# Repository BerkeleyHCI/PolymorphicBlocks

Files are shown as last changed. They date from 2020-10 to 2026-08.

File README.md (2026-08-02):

# Polymorphic Blocks






_subcircuit generator library based hardware description language for circuit board design_

Polymorphic Blocks is an open-source, Python-based [hardware description language (HDL)](https://en.wikipedia.org/wiki/Hardware_description_language) for schematic-equivalent design of printed circuit boards (PCBs).
Its library of components provide a high-level abstraction for circuit design while subcircuit generators automate the calculation of fine details.
Abstract component interfaces enable these libraries to be general across applications and component vendors.

Generates stable KiCad netlists to be routed in the KiCad PCB Editor.

### Built Boards

Many boards have been built with this system, from a mechanical keyboard macropad, to battery-powered IoT devices, to a USB source-measure unit.
Check out the [examples page](examples.md)!

## Example: from HDL to Keyboard

**Overall flow**: write HDL -> generate netlist -> import into KiCad PCB editor -> place and route (optionally iterating with HDL) -> export BoM and Gerbers -> optionally generate JLC PCBA data

A simplified version of the [getting started tutorial](getting-started.md) is this snippet for a 3x4 mechanical keyboard:

```python
from edg import *

class Keyboard(SimpleBoardTop):
    def contents(self) -> None:
        super().contents()

        self.usb = self.Block(UsbCReceptacle())
        self.reg = self.Block(LinearRegulator(3.3 * Volt(tol=0.05)))
        self.connect(self.usb.gnd, self.reg.gnd)
        self.connect(self.usb.pwr, self.reg.pwr_in)

        with self.implicit_connect(
            ImplicitConnect(self.reg.pwr_out, [Power]),
            ImplicitConnect(self.reg.gnd, [Common]),
        ) as imp:
            self.mcu = imp.Block(IoController())
            self.connect(self.usb.usb, self.mcu.usb.request())

            self.sw = self.Block(SwitchMatrix(ncols=3, nrows=4))
            self.connect(self.sw.cols, self.mcu.gpio.request_vector("sw_col"))
            self.connect(self.sw.rows, self.mcu.gpio.request_vector("sw_row"))

            self.enc = imp.Block(DigitalRotaryEncoder())
            self.connect(self.enc.a, self.mcu.gpio.request("enc_a"))
            self.connect(self.enc.b, self.mcu.gpio.request("enc_b"))
            self.connect(self.enc.with_mixin(DigitalRotaryEncoderSwitch()).sw, self.mcu.gpio.request("enc_sw"))

    def refinements(self) -> Refinements:
        return super().refinements() + Refinements(
            class_refinements=[
                (IoController, Ch32v203),
                (Switch, KailhSocket),
            ])

compile_board_inplace(Keyboard)
```

The system:
- provides a library of subcircuit generators, like switch matrices and USB-C ports, that automatically include supporting components like decoupling capacitors and pullup resistors
- automatically selects generic parts like resistors and diodes against builtin parts tables
- performs basic electrical checks on the design, including voltage and current limits, automating some common datasheet parameter checking
- runs fully locally

This generates:
- a netlist that can be imported into the KiCad PCB editor
  - ... including hierarchical data, allowing subcircuit replication / channelization
  - ... and have stable tstamps, allowing incremental updates to in-progress board layouts
- a JLCPCB-compatible BoM
  - including a [postprocessing script](edg/tools/jlc_pcba/__main__.py) to shift part rotations from KiCad-generated component placements for JLC PCBA
- a [JSON representation of the full design](edg/core/CompiledDesignExport.py), including connectivity and solved circuit values, to integrate with custom / third-party tooling

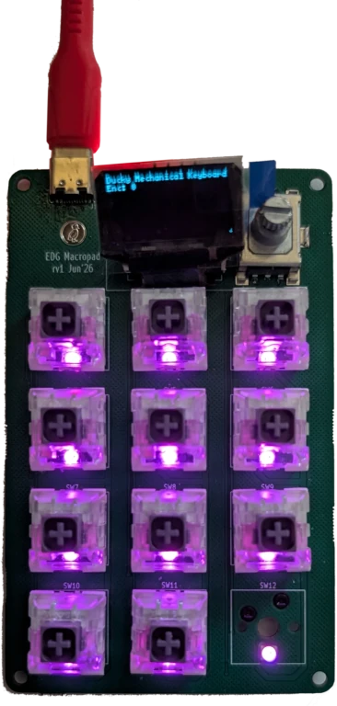
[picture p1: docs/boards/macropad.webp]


Advanced capabilities include:
- multi-board support including connector-pair management
- cross-hierarchy packing of multi-pack devices like dual op-amps and quad resistors
- standard abstract component interfaces, allowing for custom implementations of parts like resistors (including from a parts table), and microcontrollers
- full support for user component definition; very little is hard-coded into the infrastructure

## Getting Started

```
pip install edg
```

On first run, the system will automatically download a compatible Java runtime for the core compiler.

Then, work through building a mechanical keyboard (including subcircuit layout replication) in the [getting started tutorial](getting-started.md).

Also check out the [reference documentation](reference.md) for a concise list of capabilities.

Some documentation is available for library parts construction.
Be warned, this is more complex and less polished. 
See the [library block definition tutorial using KiCad schematic import](getting_started_schimport.md) and the [library construction reference](reference_library.md).

## Compared to Hierarchical Schematics

The main goal of this HDL is to enable the creation of _general_ subcircuit libraries that can be reused across many applications.

While graphical schematic tools support hierarchical sheets, direct re-use is limited because the sheets encode a lot of per-design information, like a specific resistor values or footprints.
Different users may have different requirements (e.g., different resistor values for a LED based on its input voltage, or preference for through-hole vs. surface-mount components).

This HDL addresses those limitations with two mechanisms:
- **Generators** allow the implementation of the subcircuit to depend on high-level parameters.
  A LED circuit could automatically size its resistor based on the input voltage.
- **Abstract parts** allow the subcircuit to use generic parts with generic interfaces, which many parts can implement.
  An abstract resistor interface could be implemented by through-hole and surface-mount resistors, enabling a generic LED circuit and deferring the choice.
  The top-level designer can then specify _refinements_ to make the specific choice of parts.

Both of these combined also present a higher level of abstraction for the board designer, more at the system architecture level-of-design than schematics.
We suspect this will also make it easier for novices to design boards, reducing the knowledge barrier to entry.

### Graphical Tooling

The fundamental design structure is the hierarchical block diagram, and we expect graphical tooling can layer cleanly on top of the HDL core.
Our current focus is on the HDL core and parts libraries, but we are open to collaborations with those interested in building graphical tooling.
We suspect this may be particularly useful for novice users.

We built a proof-of-concept mixed textual / graphical [IDE plugin for IntelliJ / PyCharm](https://github.com/BerkeleyHCI/edg-ide).
It has some nifty concepts (including a block diagram visualizer and [design space sweep](https://doi.org/10.1145/3613904.3642009)) but is rough around the edges and only sees basic maintenance.
It could be a good source for ideas for community developers.

## Additional Notes 

### Project Status
**This is functional has been used to [produce a wide variety of boards](examples.md) over the years.**
While the core is reasonably stable, as a pre-v1.0-release there are no formal guarantees of API stability.
In practice, deprecation shims are / will be maintained for common features if APIs change.

This started as an academic research project and continues to be developed as a personal project post-graduation, including for designing boards for fun.

### (Some) Dragons Be Ahead
Many functional boards have been built with this system and most of the library parts have been physically tested (some across many designs), but there may still be bugs and edge cases.
You are recommended to sanity check generated designs during layout.

Be prepared for things to be rough around the edges.
The error messages in particular are not great and need work.

Building boards with the included libraries should be relatively straightforward, but building custom library parts is a more complex process.

### Scope
The current libraries best support intermediate-level (and simpler) PCB designs.
This includes circuits with discrete microcontrollers, microcontroller modules (like ESP32s), and socketed dev boards.
Libraries include common subcircuits like switch matrices, digitally attached peripherals like I2C sensors, voltage converters, and some analog signal conditioning circuits.
Check out the [subcircuits library folder](edg/circuits/) and [parts library folder](edg/parts/).

There is no prescribed architecture and microcontrollers are not required.

ESPHome boards are a great fit.

Designs that do not decompose neatly(ish) into subcircuits blocks are a poor fit.

There is no support for high-speed digital design (like DDR memories).
There are some experimental RF subcircuits.

The electrical checks are not a design assurance tool and only automate some of the most common datasheet checks.
More advanced parameters, especially performance characteristics not related to maximum ratings, are currently out of scope of the electronics model.

### Parameter Engine

This system has a concept of parameters (variables, think voltages and currents) that can be attached to blocks and propagate through ports.
This is limited to directed assignments, with the goal of deterministic, predictable compilation.

Assertions are supported on parameters to enforce electrical correctness checks.

Solving may happen within a single block with arbitrary Python code (for example, find the best set of E12 resistor values to implement a divider), but not across multiple blocks.
Search involving multiple blocks must be handled by the block exposing tuning knobs and the user turning those knobs with recompilation.

### Parts Data

Most passive parts / discretes are selected from a 2022 JLCPCB parts table (included in this repository).
JLC no longer makes parts tables publicly available.

This parts table still works well and boards have been built using this table as recently as 2026.
Some basic parts have drifted and some parts may be no longer stocked.

### Contributing
We take pull requests and would love to see contributions and collaborations!

See [CONTRIBUTING.md](CONTRIBUTING.md) for details.

### Papers
This started as an academic project, though with the goal of broader adoption.
Check out our papers (all open-access), which have more details:
- [System overview, UIST'20](http://dx.doi.org/10.1145/3379337.3415860) (some details may be out of date)
- [Mixed block-diagram / textual code IDE, UIST'21](https://dl.acm.org/doi/10.1145/3472749.3474804)
- [Array ports and multi-packed devices, SCF'22](https://doi.org/10.1145/3559400.3561997)
- [Design space sweep / exploration, CHI'24](https://doi.org/10.1145/3613904.3642009)

### Misc
- **_What is EDG?_**:
  [Embedded Device Generation](https://dl.acm.org/doi/10.1145/3083157.3083159) (or more generally Electronic Device Generation) was a prior version of this project that focused on algorithms and models for embedded device synthesis, though it lacked a user-facing component.
  This project is a continuation of that work focusing on an end-to-end system, and for most of its development cycle has been called `edg`.
  But, for the purposes of writing research papers, naming collisions are confusing and bad, and we chose to keep the repo and paper name consistent.

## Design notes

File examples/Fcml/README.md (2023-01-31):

Potential improvements for v2
- Converter in connectors: rotated 90 degrees, balanced lengths to V+ and V-
- Bootstrap diodes: rotated 90 so they're not protruding into the converter power path pour
- Maybe move decoupling caps closer to FPGA and MCU
- Decoupling cap 1uF on USB Vbus line, as transient suppression

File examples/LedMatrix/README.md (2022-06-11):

## Revision 1

Revision 1 of this board had an error, where the ESP32-C3's IO8 was pulled down instead of up.
This prevents the device from going into download mode.

Suggested fix: remove the pull-down resistor, then bridge the IO8-side resistor pad to the adjacent EN resistor pad, which is pulled up.

This has since been fixed in the ESP32-C3 definition, though that fix is currently untested.

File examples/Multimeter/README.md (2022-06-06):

## Revision 2

Some items were out of stock and substituted with pin compatible alternatives:

- NLAS4157 (analog switch)
  - ~TS5A3160DCKR~
  - PI5A3157 (low-end), TS5A3159 (higher-end)
- TPA2005D1 (class D audio amp)
  - ~TPA2005D1DRBQ1 (8SON / DFN package)~ also out of stock =()
  - PAM8302AASCR (note internal resistors)
- TLV9061SQDBVRQ1 (opamp)
  - ~OPA991SIDBVR~ - NOT COMPATIBLE - IT'S ACTIVE HIGH SHUTDOWN

Part selection for some generics:
- Tactile switch
  - PTS820 J25K SMTR LFS
- FFC connector alternatives that are less expensive
  - 1734592-8
  - SFV8R-1STBE1HLF

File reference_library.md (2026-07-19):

# Quick Reference, Library Construction

A short reference specifically for building subcircuit / part library blocks.

New? Consider reading through the [getting started guide](getting-started.md), including the subsequent sections on building library blocks.

Also see the [top-level board design reference](reference.md).

This document provides a quick reference and list of common primitives and design patterns.
However, your best resource is going to be all the examples in the parts libraries. 

## Dragons be Ahead

The library design experience is much less polished and more intricate than the top-level board design experience.

## Blocks

`Block`s are a subcircuit that contain boundary ports, optional parameters, internal sub-blocks, and connections between them.

```python
class IndicatorLed(Block):
    def __init__(self, current_draw: RangeLike = (1, 10) * mAmp) -> None:
        super().__init__()
        self.current_draw = self.ArgParameter(current_draw)
        self.actual_current_draw = self.Parameter(RangeExpr())
        self.gnd = self.Port(Ground(), [Common])
        self.signal = self.Port(DigitalSink(...))

    def contents(self) -> None:
        super().contents()
        self.led = self.Block(Led(...))
        self.res = self.Block(Resistor(resistance=self.signal.link().voltage / self.current_draw))
        self.assign(self.actual_current_draw, self.signal.voltage / self.res.resistance)
        self.connect(self.signal.net, self.led.a)
        self.connect(self.res.a, self.led.k)
        self.connect(self.gnd.net, self.res.b)
```

- The `Block` API for top-level board design is also available in subcircuit `Block`s.

### Port Interfaces

- Boundary ports are defined with `self.Port(PortType(...)` and must be defined in `__init__`.
  - Boundary ports may optionally have `tags=[...]` to support implicit connections.
    Common tags are `Power` (v+), `Common` (gnd).
    Tags to support `chain` are `Input`, `Output`, and `InOut`.
  - Boundary ports may optionally define `optional=True` to indicate that the port may be left unconnected.
  - Use `PortType.empty()` to define a port without modeling, where its modeling is defined by the inner port it is connected to.
- Ports are connected with `self.connect(...)`; these may be part of a connect:
  - Boundary ports (as a unit) or their bundle inner ports (separately).
  - Boundary ports of sub-blocks (as a unit only).

> <details>
> <summary>Common Port Types</summary>
>
> - `Passive`: a single netlist pin without electrical modeling, a building block for ports with electrical modeling on top
>
> Single Wire Port that wrap (has-a) `Passive`:
> - `VoltageSource`, `VoltageSink`: models voltage and current, and their limits.
> - `DigitalSource`, `DigitalSink`, `DigitalBidir`: models voltage, voltage thresholds, current, and their limits.
>   Checks for multiple-driver conflicts, with multiple `DigitalBidir` drivers are allowed.
> - `AnalogSource`, `AnalogSink`: models voltage, current, and input/output impedance, and their limits.
>   Arbitrary requirement that the source has 1/10 the parallel impedance of sinks.
> 
> Bundle Ports
> - `I2cController`, `I2cTarget`: models I2C as two digital ports and address.
>   Checks for address conflicts.
> - `SpiController`, `SpiPeripheral`: models the shared SPI lines (excluding CS) as three digital ports.
> - `UartPort`: models UART TX/RX as two digital ports.
>   Connections generate a crossover connection.
> - `UsbHostPort`, `UsbDevicePort`: USB D+/D- ports
> - `CanControllerPort`, `CanTransceiverPort`: controller-side and transceiver-side RXD and TXD ports.
> - `CanDiffPort`: differential-side CAN (CANH, CANL) ports
> 
> See their class docstring and constructor for details.
> 
> See Design Patterns below for adapting between (some) port types.
> 
> </details>

### Parameters

Parameters are variables that can be passed into and through blocks.

- Parameters are defined purely symbolically and concrete values are not available to (non-generator) `Block`s.
- Parameters are restricted to a set of types supported by the compiler and the operations on them:
  - `BoolExpr` / `BoolLike`: boolean (true / false) variable
  - `IntExpr` / `IntLike`: numeric variable
  - `FloatExpr` / `FloatLike`: numeric variable
  - `RangeExpr` / `RangeLike`: range (interval) variable
  - `StringExpr` / `StringLike`: string (text) variable
  - See the `xExpr` class definition for supported operations.
  - See the generator section for how to use arbitrary Python code for calculations.
- Parameters must be defined in `__init__`, either with:
  - `self.ArgParameter(arg)`, to wrap `__init__` argument `arg`.
    Use the `xLike` type for `__init__` arguments, which also allow the literal Python value.
  - `self.Parameter(ParameterType())` (for a parameter without a value, to be assigned in `contents()`).
    Use the `xExpr` type in `Parameter(...)` to declare a parameter without a value, to be assigned in `contents()`.
- `RangeExpr` types are used to represent a device tolerance or toleranced specification
  - Most operations between `RangeExpr` types are tolerance-expanding (computes the worst-case range of the inputs)
  - `a = c.shrink_multiply(b)` is a tolerance-shrinking operation to calculate the maximum allowable toleranced `a`, such that tolerance-expanding `a * b` is equal to `c`.
    Example: for `v = i * r`, to solve for allowable (target) `r` given requirement `i` and contributing tolerance `v`, use `r = (1/i).shrink_multiply(v)`
- Access parameters on the link of ports using `port.link().link_param`.
  Links contain the aggregated parameter of all connected ports, for example the voltage.

Quirks:
- `port.link().link_param` will be undefined for an unconnected port.
  For optional ports, gate checks with `port.is_connected().else_then(..., ...)`.
  This may be fixed eventually, see [#360](https://github.com/BerkeleyHCI/PolymorphicBlocks/issues/360).

### Footprints

The `FootprintBlock` base class is a `Block` that defines at most one footprint.

```python
class Sk6812Mini_E(FootprintBlock):
    def __init__(self) -> None:
        super().__init__()
        self.gnd = self.Port(Ground())
        self.vdd = self.Port(VoltageSink(...))
        self.din = self.Port(DigitalSink(...))
        self.dout = self.Port(DigitalSource(...))

    def contents(self) -> None:
        self.footprint(
            "D",
            "edg:LED_SK6812MINI-E",
            {"1": self.vdd, "2": self.dout, "3": self.gnd, "4": self.din},
            mfr="Opsco Optoelectronics",
            part="SK6812MINI-E",
            datasheet="https://cdn-shop.adafruit.com/product-files/4960/4960_SK6812MINI-E_REV02_EN.pdf",
        )
```

- `self.footprint(...)` defines the footprint associated with this block and its pinning and takes these arguments:
  - `refdes`
  - `footprint`: KiCad footprint name.
  - `pinning`: dictionary mapping footprint pin numbers to ports.
    - Pin numbers must be `str` or `Tuple[str, ...]` (for multi-pin pads).
    - Ports must be `Passive` or `HasPassive`.
  - Optional metadata `mfr`, `part`, `value`, `datasheet`.
  - Optional pick-and-place metadata `pnp_rot`, `pnp_offset` for KiCad footprint to JLC PCBA PnP data. 
- While not (yet) forbidden, `FootprintBlock`s should not have inner sub-`Block`s.

## Schematic-Defined Blocks

`KiCadSchematicBlock` is a `Block` that is defined by a KiCad schematic sheet.

```python
class MySchematicDefinedBlock(KiCadSchematicBlock):
    def __init__(self) -> None:
        super().__init__()
        self.gnd = self.Port(Ground())
        self.pwr = self.Port(VoltageSink(...))

    def contents(self) -> None:
        super().contents()
        self.import_kicad(
          self.file_path(f"{self.__class__.__name__}.kicad_sch"),
          conversions={'pwr': VoltageSink(...), 'gnd': Ground()},
          auto_adapt=True
        )
```

- The HDL stub is required to define the boundary ports and parameters.
- Graphical schematic components map as follows:
  - Labels, including symbols like GND and VCC, connect internally.  
  - Hierarchical labels connect to the boundary ports.
  - True global labels (that connect design-wide) are not supported.
  - Components map to `Block`s, with the refdes mapping to the `Block` name.
  - Wires map to `connect`s.
  - Pins must be connected at a wire end or bend.
- Components can be defined as:
  - Using a `KiCadInstantiableBlock` (which defines the symbol to port mapping), and the symbol has no footprint:
    - **Value parsing**: some blocks can parse the symbol value to parameters, see the table below.
    - **HDL instantiation**: the block is instantiated in HDL and the symbol refdes matches the HDL `Block` name and has no value.
    - **Inline HDL**: the symbol value starts with a `#` and contains Python code to instantiate the `Block`.
      Multi-line values supported using the `Value2`, `Value3`, ... fields.
  - **Blackboxing**, where the symbol has a footprint specified and is created as a `Block` with all `Passive` ports.
- Port connections are direct and types of connected pins must be compatible.
  - Use `conversions` to optionally specify a electrically typed `Port` model for a `Passive` `Port`.
  - Use `auto_adapt` to automatically insert ideal adapters from `Passive` `Port`s to the HDL-defined electrically typed boundary ports.

> <details>
> <summary>Common `KiCadInstantiableBlock`s</summary>
>
> With Passive-typed Ports, typically for constructing basic (sub)circuits:
> 
> | Symbol                             | HDL Block          | Value Parsing    |
> |------------------------------------|--------------------|------------------|
> | Device:C, Device:C_Polarized       | Capacitor          | e.g. `10uF 10V`* |
> | Device:R                           | Resistor           | e.g. `100`       |
> | Device:L                           | Inductor           |                  |
> | Device:Q_NPN_\*, Device:Q_PNP_\*   | Bjt.Npn, Bjt.Pnp   |                  |
> | Device:D                           | Diode              |                  |
> | Device:D_Zener                     | ZenerDiode         |                  |
> | Device:L_Ferrite                   | FerriteBead        |                  |
> | Device:Q_NMOS_\*, Device:Q_PMOS_\* | Fet.NFet, Fet.PFet |                  |
> | Switch:SW_SPST                     | Switch             |                  |
> * Capacitor voltage is required and is specified as the expected operating voltage, not a rating.
> 
> Where value parsing is empty, the Block can only be defined by HDL instantiation or inline HDL.
> 
> In many cases, the `_Small` (like `Device:C_Small`) symbol can also be used.
>
> With electrically-typed ports, typically used in higher-level subcircuits like analog signal-processing chains:
> 
> | Symbol                               | HDL Block             |
> |--------------------------------------|-----------------------|
> | Simulation_SPICE:OPAMP               | Opamp*                |
> | edg_importable:Amplifier             | Amplifier             |
> | edg_importable:DifferentialAmplifier | DifferentialAmplifier |
> | edg_importable:IntegratorInverting   | IntegratorInverting   |
> | edg_importable:OpampCurrentSensor    | OpampCurrentSensor    |
> * `Opamp`s include any datasheet-required supporting circuitry like decoupling capacitors.
> 
> Search for all subclasses of `KiCadImportableBlock` for a complete listing.
> 
> </details>

Guidance:
- Good uses include analog subcircuits where the graphical connectivity is complex and meaningful.
- This can be used to construct both library subcircuits as well a higher-level subcircuits like signal-processing chains using amplifier subcircuits.
- Most chip subcircuits are defined purely in HDL.

## Generators

`GeneratorBlock` is a `Block` that can retrieve the concrete value of its parameters and run arbitrary Python code to create its inner definition, including structural circuitry and parameters.

```python
class IndicatorLedArray(GeneratorBlock):
    def __init__(self, count: IntLike):
        super().__init__()
        self.count = self.ArgParameter(count)
        self.generator_param(self.count)
        
        self.gnd = self.Port(Ground.empty(), [Common])
        self.signals = self.Port(Vector(DigitalSink.empty()))
    
    def generate(self) -> None:
        super().generate()
        self.led = ElementDict[IndicatorLed]()
        for led_i in range(self.get(self.count)):
          led = self.led[str(led_i)] = self.Block(IndicatorLed())
          self.connect(...)
```

- `self.generator_param(...)` is required to declare parameters that the generator needs.
  - Only `ArgParameter`s, `port.is_connected()` and `port.elements()` are allowed.
- `self.get(...)` can be invoked in `generate()` to retrieve the concrete value of a parameter.

Guidance:
- Generators are necessary for parametric structural circuit construction.
- Prefer using non-generator expression operations for parameter calculations where possible.
  Generators should only be used where the expression operations are insufficient. 

## Abstract Blocks

`abstract_block`s are `Blocks` that define an interface that can be implemented by (concrete) subclasses.
They can be instantiated but will error during compilation if not refined.

```python
@abstract_block
class Led(Block):
    def __init__(self):
        self.a = self.Port(Passive.empty())
        self.k = self.Port(Passive.empty())
```

- Boundary ports and parameters are defined as usual.
- Ports are defined with `PortType.empty()` to allow subclasses flexibility in modeling.
  - Subclasses can specify modeling with `self.port.init_from(PortType(...))`.
    Replacing the port object is not allowed.
- A default refinement can be attached to the `abstract_block` with `@abstract_block_default(lambda: DefaultRefinementBlock)`. 
  - The `lambda` is required to break circular definitions.
  - Top-level designers can still override these refinements.

Guidance:
- Use `abstract_block`s to define a common interface for `Block`s that are drop-in interchangeable.
- You can always refactor to pull out a common `abstract_block` later.

### Mixins

`BlockInterfaceMixin`s define an interface that can be added to an `abstract_block`.

```python
# mixin interface definition
class RotaryEncoderSwitch(BlockInterfaceMixin[RotaryEncoder]):
    def __init__(self, *args: Any, **kwargs: Any) -> None:
        super().__init__(*args, **kwargs)
        self.sw = self.Port(Passive.empty(), optional=True)

# concrete class implementing the mixin
class Ec11eWithSwitch(RotaryEncoderSwitch, RotaryEncoder):
    ...
```

- A `Block` definition can inherit multiple mixins (the `Block` implements multiple mixins).
- A `Block` instantiation can use multiple mixins (requiring the concrete `Block` refinement to implement those mixins).
- Mixin interface ports are typically `optional` to allow usage without the mixin.
  This may be a generator that provides a default connection in a basic usage configuration.

### Abstract Passives and Parts Tables

Many common passive and discrete parts (like `Resistor`, `Capacitor`, `Diode`) are `abstract_blocks` and support different (including user-defined) implementations, e.g. to support different vendors and distributors.

Many of these include a utility subclass for selecting a part from a table (like `TableResistor`, `TableCapacitor`, `TableDiode`).

These also provide a separate utility subclass that defines KiCad footprint to port mappings that implement the `HasStandardFootprint` interface (like `ResistorStandardFootprint`, `CapacitorStandardFootprint`, `DiodeStandardFootprint`).

These classes provide utility functions for parts table selectors:
- `PartsTablePart`: interface parameters (part requirement, excluded parts, and more) for part selected from a parts table.
- `PartsTableSelector`: utility code to select a part from a `PartsTable`, implementing `PartsTableSelector`.
- `SelectorFootprint`: interface parameters to allow filtering by footprint.
- `PartsTableFootprintFilter`: utility code to filter a parts table by footprint, implementing `SelectorFootprint`.
- `PartsTableSelectorFootprint`: utility code to construct the footprint, for a `HasStandardFootprint`. 

Look at some example implementations for the `PartsTable` API and utilities.

## Design Patterns and Conventions

These are design patterns and conventions used in the included parts library.

### `_Device` Footprint and Subcircuit

The `x_Device` `Block` defines the footprint only, while the application circuit `Block` is the user-friendly name and instantiates `x_Device`.
`x_Device` is not exported in `__init__.py`.

### Passive and Typed Layers

Passive components are `Passive` port typed, and applications of them are separate `Block`s that instantiate the `Passive` typed `Block`s. 
This allows different implementation of the same `Passive` device, eg, `PullupResistor`, `PulldownResistor`.
Subcircuits follow this pattern too, with them instantiating the `Passive` typed `Block`, connecting the `Passive` ports internally and to the `Passive` `.net` of the electrically-typed boundary `Port`s.

### Target and Actual Parameters

Most parameters are defined as a target requirement.

The actual expected operating value may be calculated as a readout parameter and is prefixed `actual_`. 

### PassiveConnector

Devices that use a standard connector (like FPCs) should instantiate the appropriate `PassiveConnector` subclass to allow the system designer to make choices for the concrete connector.
`PassiveConnector` supports parameterized pin counts.

### Circular Dependencies

There is currently no structural prevention of circular parameter dependencies.

This may happen when a `Block` has a parameter that is calculated from a `Port`'s link, and the `Port`'s link is calculated from the `Block`'s parameter.
For example, the LED calculates current from the link's voltage, while a source block that calculates voltage from the link's current would be unsolvable.

We typically resolve this by using the user-specified range for one of the parameters and accepting that it will be a wider range than the actual operating range.

## Custom Ports and Links

Custom `Port`s and `Link`s can be defined.

`Port`s should define properties of that `Port` only, not properties influenced by any other connected `Port`.
The `Link` aggregates parameters on the connected `Ports` and optionally defines constraints as assertions.

`Port`s can contain other `Port`s, such as:
- Bundles of `Port`s, like `SpiController`
- An inner `Passive` that provides the connectivity layer 

The design convention for whether bundle `Port`s are `Passive` or electrically typed is:
- Protocols that define an electrical specification are `Passive` typed.
  The electrical modeling is functionally redundant and connections between any parts should be compatible.
  Example: CAN, USB.
- Protocols that only define the signal specification are electrically typed.
  Electrical modeling is needed to check for compatibility.
  Examples: SPI, I2C, which use `DigitalSource` / `DigitalSink` / `DigitalBidir` internally.

Look at examples in the standard interfaces library for details.

### Bridges

`PortBridge` are a quirk of the hierarchical model: how to expose a single boundary `Port` of a `Block` that is internally connecting multiple internal `Port`s.

`PortBridge` "aggregate" the `inner_link` (by connecting to a `Port` on that `Link`) and expose a single `outer_port`.

General design patterns:
- Parameters always propagate outward, never inward.
- Checks that require context at the outer level are handled by propagating the relevant parameters outward. 
- If needed, define additional internal parameters (`_`-prefixed) on the `Port` to propagate all the relevant data outward.

### Mixins

Mixins on `Port`s may be an interesting concept to support opt-in specialized parameter propagation without an excessive base (see [#333](https://github.com/BerkeleyHCI/PolymorphicBlocks/issues/333)) but do not have an implementation plan yet.

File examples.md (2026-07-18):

# Example boards

This is a small, curated list of example boards built with this HDL framework. 

## Mechanical Macropad



[test_keyboard.py](examples/test_keyboard.py), [Keyboard.kicad_pcb](examples/Keyboard/Keyboard.kicad_pcb)

[Minimal Rust firmware](https://github.com/ducky64/edg-pcbs/tree/main/KeyboardExample) (note, RMK crashes on this device, possibly an issue with mutex implementation on the CH32V203 HAL).

A 3x4 mechanical macropad with per-key RGB lighting, using a discrete CH32V203 microcontroller and USB-C.
Also includes a rotary encoder and a small OLED display.
Example of a full device built with minimal HDL, demonstrating the power of subcircuit generator libraries.

A variation of the design in the [getting started tutorial](getting-started.md).

## BLE Joystick

_This is a new board, bring-up is a work in progress._

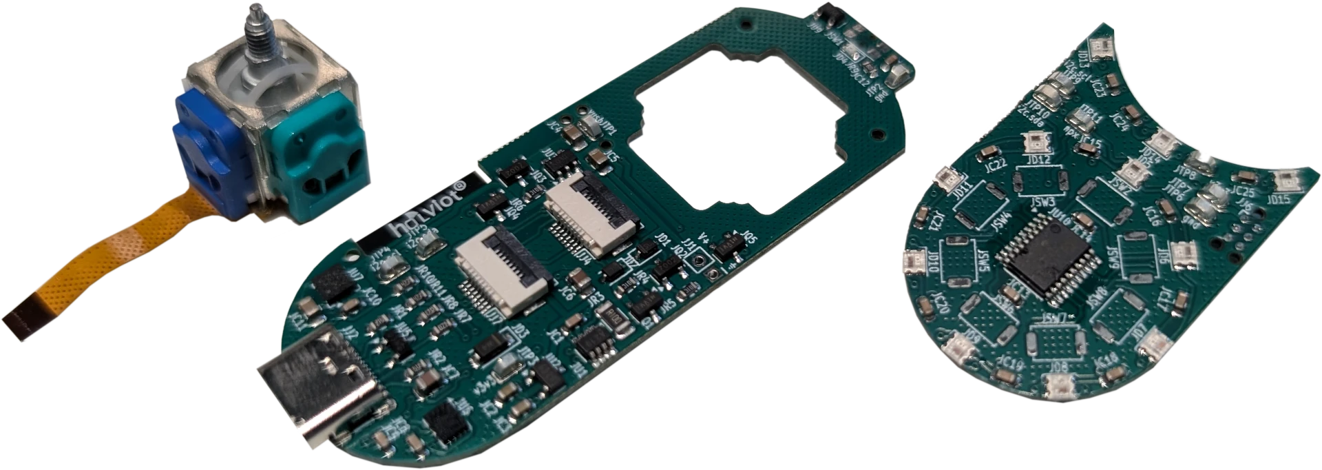
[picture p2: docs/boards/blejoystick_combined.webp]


[test_ble_joystick.py](examples/test_ble_joystick.py), [BleJoystick.kicad_pcb](examples/BleJoystick/BleJoystick.kicad_pcb) (main board), [BleJoystick_btns.kicad_pcb](examples/BleJoystick/BleJoystick_btns.kicad_pcb) (buttons sub-board), [BleJoystick_stick.kicad_pcb](examples/BleJoystick/BleJoystick_stick.kicad_pcb) (joystick FPC)

[Rust firmware](https://github.com/ducky64/blejoystick-rs)

An nRF52840 based air-mouse with an XBox joystick and d-pad.

Example of a three board assembly with connector-pairs managed by the system: the buttons daughterboard connects to the main board via a FFC, and the joystick itself is on a FPC "board".

## USB Source-Measure

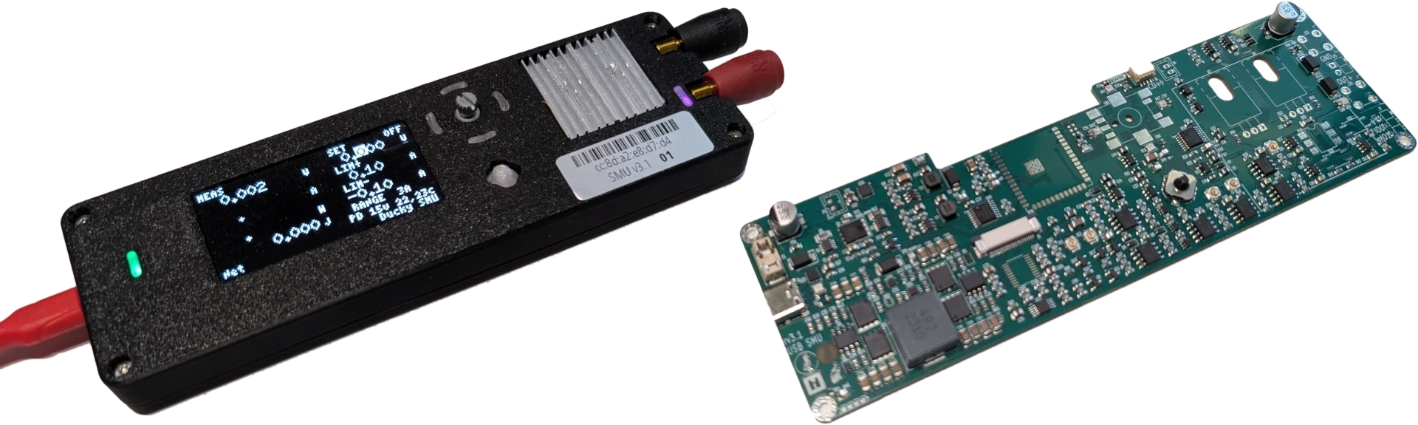
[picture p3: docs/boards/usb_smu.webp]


[test_usb_source_measure.py](examples/test_usb_source_measure.py), [UsbSourceMeasure.kicad_pcb](examples/UsbSourceMeasure/UsbSourceMeasure.kicad_pcb)

[ESPHome firmware](https://github.com/ducky64/usb-source-measure/)

A portable 2-quadrant (positive voltage only, sourcing or sinking current) DC power supply, powered from USB-PD.
Design target of 0 - 30V output, -3 - +3A current (electrical limits, thermal limits lower), three current ranges (30mA, 300mA, 3A).
Buck-boost (four-switch) pre-regulator and linear analog feedback stage.

Example of a fairly complex device with dual-pack opamps and significant analog circuitry.
The analog feedback circuitry is a high-level KiCad-schematic-defined-block:

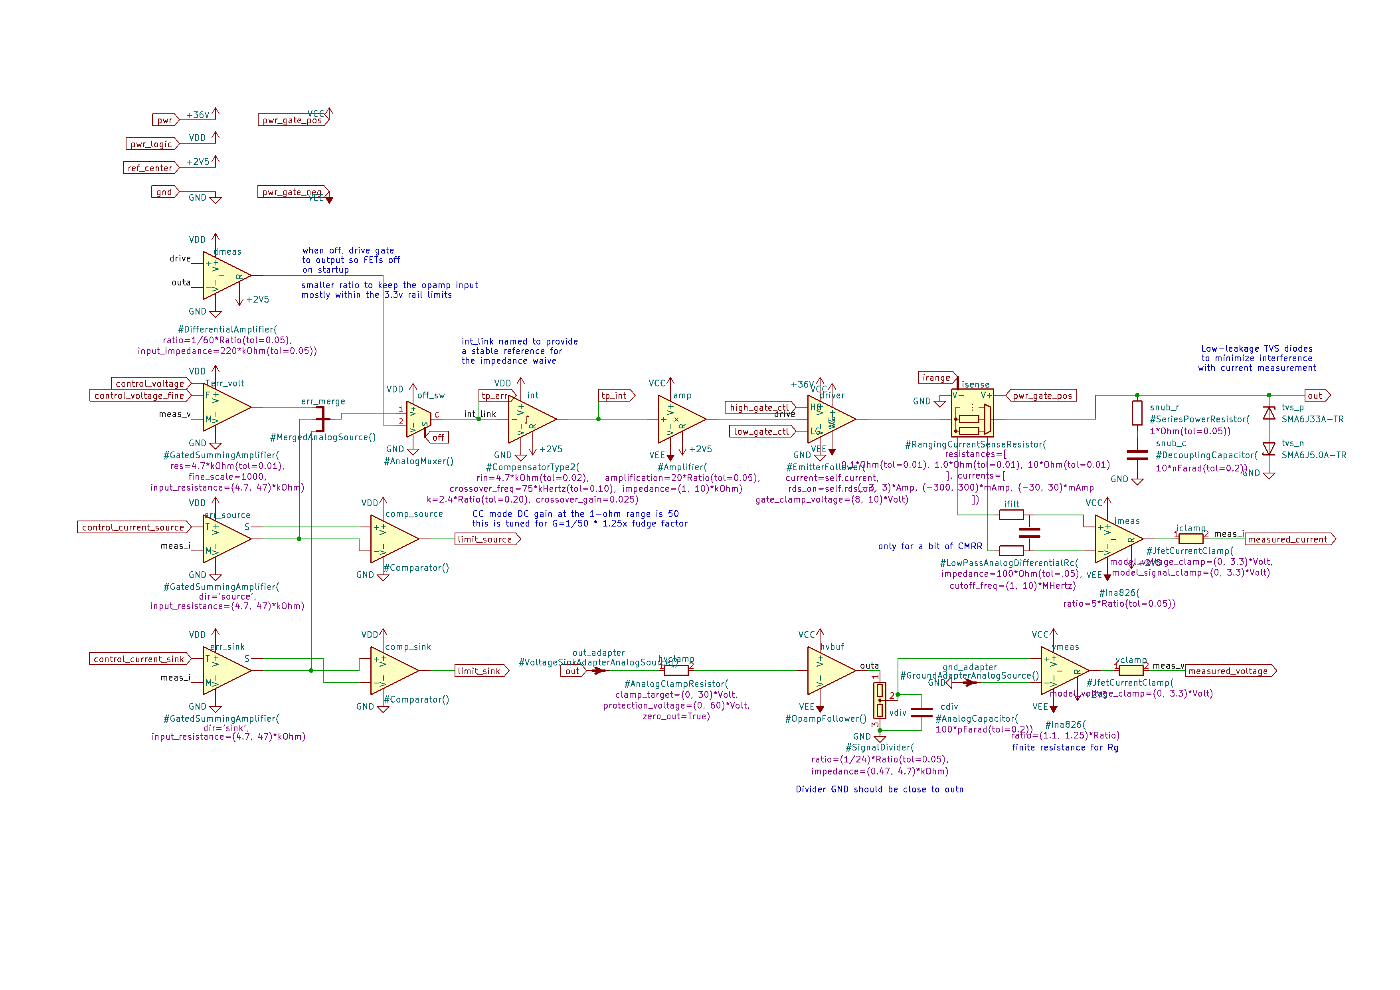
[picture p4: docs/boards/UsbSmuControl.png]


This device functions fine as a basic DC lab supply but frequency response and measurement noise needs more tuning and iteration.   

## E-ink Display

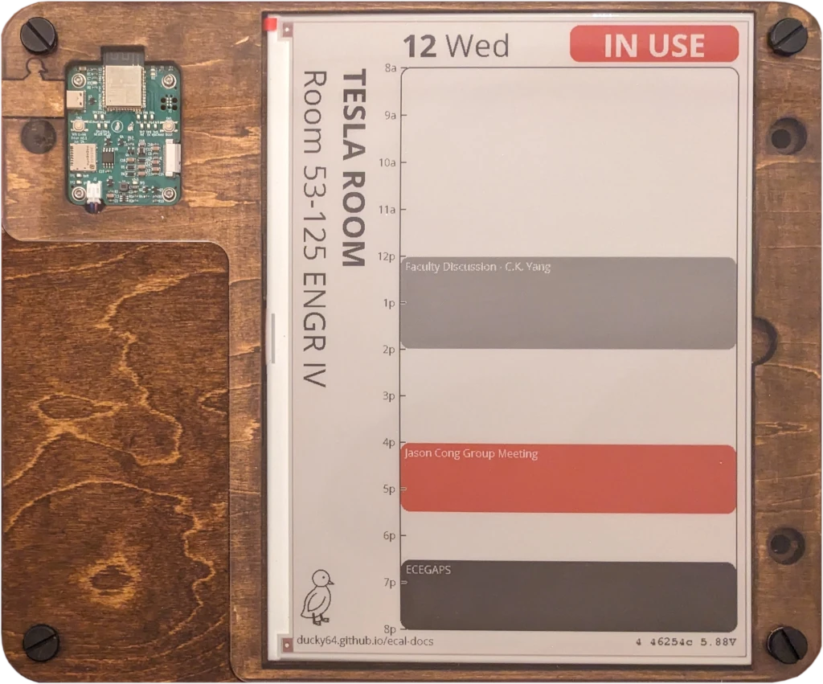
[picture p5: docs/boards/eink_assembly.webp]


[test_iot_display.py](examples/test_iot_display.py), [IotDisplay.kicad_pcb](examples/IotDisplay/IotDisplay.kicad_pcb)

[Arduino firmware](https://github.com/ducky64/edg-pcbs/tree/main/IoTDisplay)

A battery-powered WiFi e-ink display controller with low sleep current and expected 1 year life on 4xAA batteries.
Designed for simple deployment: no power wires to run, piggybacks off existing WiFi network infrastructure.

A few of these are deployed outside the UCLA ECE departmental meeting rooms as room calendars.

## SWD and ESP Programmers

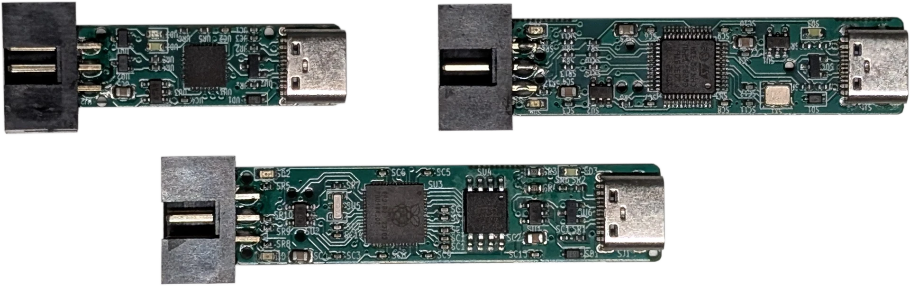
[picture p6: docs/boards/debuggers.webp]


[test_swd_debugger.py](examples/test_swd_debugger.py), [SwdDebugger.kicad_pcb](examples/SwdDebugger.kicad_pcb), [PicoProbe.kicad_pcb](examples/PicoProbe/PicoProbe.kicad_pcb),

[test_esp_programmer.py](examples/test_esp_programmer.py), [EspProgrammer.kicad_pcb](examples/EspProgrammer/EspProgrammer.kicad_pcb)

Tiny SWD and ESP programmers with USB-C and a 6-pin Tag-Connect interface to the target.

The STM32 SWD programmer run a variation of [DAPLink](https://github.com/armmbed/daplink), the RP2040 SWD programmer runs the Picoprobe firmware.

The ESP programmer is a CP2102 USB-UART bridge with no microcontroller.

## LoRa and NFC Demonstrator

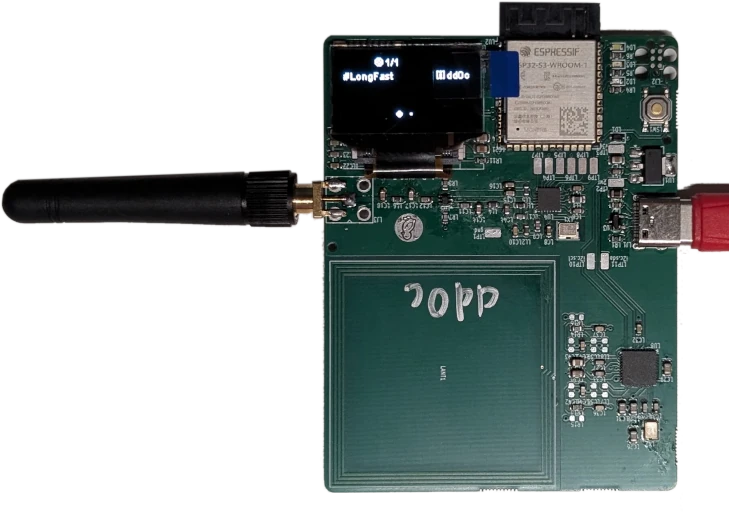
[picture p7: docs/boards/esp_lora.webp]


[test_lora.py](examples/test_lora.py), [EspLora.kicad_pcb](examples/EspLora/EspLora.kicad_pcb)

[ESPHome firmware for NFC](https://github.com/ducky64/edg-pcbs/blob/main/IoTDevices/nfctest.yml); also runs Meshtastic

A demonstrator / test board for RF subcircuit generators, generating the analog frontend for the SX1262 LoRa transceiver and PN7160 NFC controller.
Both of these subcircuits work, though RF performance hasn't been characterized in any detail.

## Multilevel Converter Demonstrator

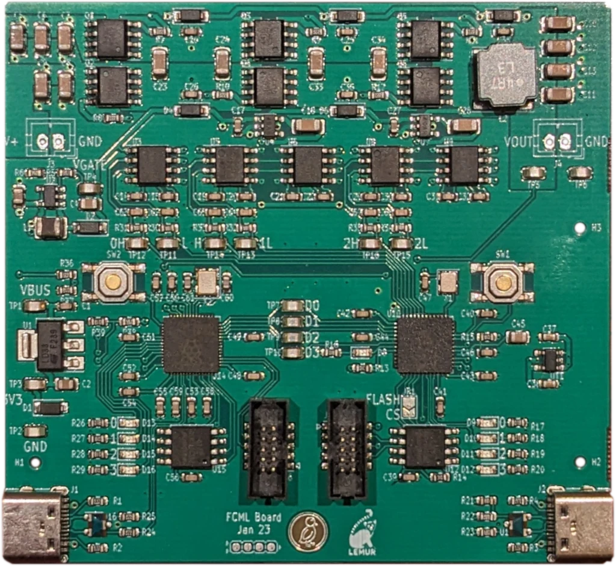
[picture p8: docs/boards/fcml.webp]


[test_fcml.py](examples/test_fcml.py), [Fcml.kicad_pcb](examples/Fcml/Fcml.kicad_pcb)

[Minimal Chisel RTL / gateware](https://github.com/calisco/fcml-rtl)

A design using an iCE40 FPGA that drives a 4-level flying capacitor multilevel buck converter, a converter topology that trades inductor size for more switches. 
A few basic tests have been run with this device, and it appears to be able to process power efficiently.

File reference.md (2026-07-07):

# Quick Reference

A short reference for writing HDL for (top-level) board designs.

New? Consider reading through the [getting started guide](getting-started.md).

Also see the [reference for building subcircuit / part library blocks](reference_library.md).

### DesignTop Block
`Block`s represent a subcircuit (including the top-level circuit) and contain inner blocks and connections between them.

```python
class MyBoard(SimpleBoardTop):
    def contents(self) -> None:
        # declare subblocks and connections here
        super().contents()  # required to call this superclass method first        
        self.mcu = self.Block(IoController())
        self.led = self.Block(IndicatorLed())
        self.connect(self.mcu.gpio.request("led"), self.led.signal)
        self.connect(self.mcu.gnd, self.led.gnd)
        self.sw = self.Block(DigitalSwitch())
        self.connect(self.mcu.gpio.request("sw"), self.sw.out)
        self.connect(self.mcu.gnd, self.sw.gnd)
        
    def refinements(self) -> Refinements:
        # refinements describe modifications across the design hierarchy
        return super().refinements() + Refinements(
            class_refinements=[
                (IoController, Esp32c3),  # replace all abstract IoController with Esp32c3
            ],
            instance_values=[
                (["mcu", "pin_assigns"],  ["led=3", "sw=6"])  # assign to footprint pins 3 and 6
            ],
        )
```

- `SimpleBoardTop` maps abstract passive components to the JLC parts library and relaxes some strict constraints that do not matter for maker-type boards.
- Alternatively, use `DesignTop` (which has no default mappings) or `JlcBoardTop` (which has JLC part mappings).

### Block definition

Internal blocks are created using `self.Block(...)` and must be assigned a unique name (in `self`) for netlist stability.

```python
self.block_name = self.Block(BlockType(...))
```

- Some blocks may take arguments, see their `__init__` for details.
- Builtin parts (like ICs) are in [the parts folder](edg/parts) and builtin circuits are in [the circuits folder](edg/circuits).
- See [the examples](examples/) for common blocks and how they're used.
- Abstract blocks can be instantiated, but require a refinement in the top-level design.
  - Some DesignTop subclasses like `SimpleBoardTop` provide default refinements.

#### Range Arguments

Blocks commonly take arguments as a range-like type, typically a specification for an allowable range accounting for tolerance stackup.

```python
self.reg = self.Block(LinearRegulator(3.3 * Volt(tol=0.05)))
```

#### ElementDict

`ElementDict` creates an internal namespace, providing an unique name for elements in an array of blocks by attaching their index to the name.

```python
self.block_name = ElementDict[IndicatorLed]()
for i in range(4):
    self.block_name[i] = self.Block(IndicatorLed())
```

### Connections

`self.connect` connects ports on blocks, inferring the link type from the port types in the connection.

```python
self.connect(self.block1.port, self.block2.port, ...)
```

- `self.connect` returns a `Connection` object, which can be used in connections.
- Optionally assign a name to the `Connection` by assigning to a `self` variable.
- Connections must be between ports of compatible type.
  Typed ports (like `Ground` or `VoltageSink`) are distinct from `Passive` ports and not connectable without adapters.
- Only the block's ports and inner blocks' ports can be connected.
  Connections cannot be made arbitrarily deep in the block hierarchy.

#### Implicit Connection Blocks

`self.implicit_connect` creates a scope for implicit connections, typically for power and ground.

```python
with self.implicit_connect(
    ImplicitConnect(self.pwr, [Power]),
    ImplicitConnect(self.gnd, [Common]),
) as imp:
    self.block_name = imp.Block(BlockType(...))
``` 

- Port matching is done against the block's ports' tags using tag objects `Power` and `Common`.

#### Chain Connections

`self.chain` connects ports (and ports on blocks) in a chain, from left to right.

```python
(self.led,), _ = self.chain(imp.Block(IndicatorSinkLed()), self.mcu.gpio.request("led"))
```

- `self.chain` returns a nested tuple of `((blocks...), chain)`.
  Blocks must be named, the chain object can be optionally named to name the interior nets.
- In the example above:
  - The trailing comma in `(self.led, )` unpacks the single-element blocks tuple to name it.
  - The `_` discards (does not name) the chain object.
- Blocks in the chain are connected to:
  - their `Input` tagged port, for an incoming connection from the left,
  - their `Output` tagged port, for an outgoing connection to the right,
  - their `InOut` tagged port, for both incoming and outgoing connections (tapped connection).

#### .connected(...)

Some (but far from all) blocks define a `.connected(...)` as a shorthand connection method, see each class's API for details.
These return the block itself, allowing it to be assigned to a name.

```python
self.tp_gnd = self.Block(GroundTestPoint()).connected(self.gnd)
```

### Refinements

Refinements allow specifying, at the top level, modifications across the design hierarchy.

```python
def refinements(self) -> Refinements:
    return super().refinements() + Refinements(
        class_refinements=[
            (IoController, Esp32c3),
        ],
        instance_refinements=[
            (["mcu"], Esp32c3),
        ],
        instance_values=[
            (["mcu", "pin_assigns"],  ["led=3"])
        ],
        class_values=[
            (SelectorArea, ["footprint_area"], Range.from_lower(1.5)),
        ]
    )
```

- `class_refinements` replaces all instances of a block type with a subclass.
- `instance_refinements` replaces a specific instance of a block with a subclass.
  The instance is specified as a path, as a list of block names from the root.
- `instance_values` sets a parameter value on a specific instance of a block, specified as a path.
- `class_values` sets a parameter value on all instances of a block type.
  It is specified as a class, then a sub-path to the parameter.

### Parts Table Parts

- Some blocks, particularly discrete components like `Resistor`s and `Fet`s, are implemented as automatic selection from a parts table.
- These are some common top-level refinements:
  - Class refinement `(SelectorArea, ["filter_area"], Range.from_lower(1.5))`: require a minimum footprint courtyard area, in mm²
  
    | Package | Minimum Area (mm²) |
    |---------|------------------|
    | 01005   | 0.72             |
    | 0201    | 0.98             |
    | 0402    | 1.74             |
    | 0603    | 4.32             |
    | 0805    | 6.38             |
    | 1206    | 10.21            |
  - Instance refinement `(["part_table_block", "excluded_parts"], ["1N2127"])`: exclude parts from selection, e.g., if they're out-of-stock.
  - Instance refinement `(["part_table_block", "part"], "1N2127")`: require a particular part.
  - Instance refinement `(["part_table_block", "filter_footprints"], ["Diode_SMD:D_SMA"])`: require specific footprints.

### IoController

`IoController` is an abstract class for any programmable IO controller, typically microcontrollers, but also including FPGAs.

```python
self.mcu = imp.Block(IoController())
self.connect(self.mcu.gpio.request("led"), self.led.signal)
```

- `IoController`s have `gnd` and `pwr` input power ports, and `gpio`, `adc`, `spi`, `i2c`, `uart`, and `usb` Vector IO ports which elements can be requested from.
- Not all `IoController`s support all IO types, see each class's API for details.
- The `request(...)` name is used in the `pin_assigns` refinement, with each entry specified as either `led=3` (by footprint pin number) or `led=GPIO4` (by IO name, see each class's API for details).
- These request types are available, and their pin assignment entries are:

  | Request Type            | Request Syntax                           | Pin Assignment Entries                                 |
  |-------------------------|------------------------------------------|--------------------------------------------------------|
  | Single Element          | `self.mcu.gpio.request("my_io")`         | `"my_io=3"`                                            |
  | Vector                  | `self.mcu.gpio.request_vector("my_ios")` | `"my_ios_0=3", "my_ios_1=4", ...` (underscore-indexed) |
  | Bundle (e.g., SPI, I2C) | `self.mcu.spi.request("my_spi")`         | `"my_spi.sck=3", "my_spi.mosi=4", ...` (dot-indexed)   |
  | Unnamed                 | `self.mcu.gpio.request()`                | Arbitrarily named, don't rely on this                  |

### Mixins

Mixins are a way to require additional functionality (or ports) on an abstract block, they restrict refinements to concrete classes that implement the mixin.

```python
# require additional ports defined by a mixin
self.connect(self.can.controller, self.mcu.with_mixin(IoControllerCan()).can.request("can"))

# require a mixin as a refinement constraint only
self.mcu.with_mixin(IoControllerWifi())
```

- IoController has these mixins:
  - defining IO ports: `IoControllerDac`, `IoControllerI2cTarget`, `IoControllerSpiPeripheral`, `IoControllerTouchDriver`, `IoControllerCan`, `IoControllerUsbCc`, `IoControllerI2s`, `IoControllerDvp8`
  - connectivity requirements only: `IoControllerWifi`, `IoControllerBluetooth`, `IoControllerBle`
  - defining power ports, typically for microcontroller dev boards: `IoControllerPowerOut`, `IoControllerUsbOut`, `IoControllerVin`

### Connector Blocks

Custom connectors are implemented as a `Block` with ports representing its IOs.

```python
class CustomUartConnector(Block):
    def __init__(self) -> None:
        super().__init__()
        self.gnd = self.Port(Ground(), [Common])
        self.pwr = self.Port(VoltageSink(), [Power])
        self.uart = self.Port(UartPort())

        self.conn = self.Block(PassiveConnector(length=4)).connected(
            {
                "1": self.gnd,
                "2": self.pwr,
                "3": self.uart.tx,
                "4": self.uart.rx,
            }
        )
```

- `self.port_name = self.Port(...)` defines a port on the block.
- Ports must be typed, the `Passive` port type is not automatically connectable to typed single-wire ports like `Ground` or `VoltageSink` without adapters.
- Ports take electrical modeling parameters (like voltage and current limits) as parameters, empty parameter generally means an ideal port.
- `PassiveConnector` is an abstract class for connectors with a parameterizable number of passive-typed pins, including 2.54mm headers, FPCs, and more.
- `PassiveConnector.connected(...)` automatically adapts typed ports to the connector's Passive ports.

### Multipacking

Multipacking allows multiple components, potentially spread across the design hierarchy, to be combined into one component.
This is an optimization that may save board area and cost.
Example: quad-pack resistor networks, dual-pack opamps, RGB LEDs.

```python
class MyBoard(SimpleBoardTop):
    def contents(self) -> None:
        ...
    
    def multipack(self) -> None:
        self.res_pack = self.PackedBlock(ResistorArray())
        self.pack(self.res_pack.elements.request('0'), ['led[0]', 'res'])
        self.pack(self.res_pack.elements.request('1'), ['led[1]', 'res'])
        self.pack(self.res_pack.elements.request('2'), ['led[2]', 'res'])
        self.pack(self.res_pack.elements.request('3'), ['led[3]', 'res'])
```

- `multipack()` is a blend of `contents()` (in that `PackedBlocks` are declared within) and `refinements()` (in that it uses `List[str]` to reference blocks in the design hierarchy).
- All multipack Blocks, Blocks that allow other components to be packed into it, extend `MultipackBlock`.
- `self.PackedBlock(...)` is similar to `self.Block(...)`.
- `self.pack(...)` takes two arguments:
  - `multipack_part`: the multipack element that is part of the packed block, either a block or an element of a dynamically-sized packed block array.
  - `path`: the path to the block which this replaces, as a list of strings.
- This remains correct ERC model-wise, elements of the packed block are modeled as being 'inside' the replaced block.  
- Each multipack element has its own ports, including for shared pins like the common power pins of a dualpack opamp.
  A compiler assertion checks that these are all connected to the same netlist net.
- Multipacking can only be defined at the BoardTop level.

### Sub-boards and Connector Pairs

Subboards are `Block`s that define a subcircuit that is its own board (generates a separate netlist).

```python
class LedSubboard(SubboardBlock):
    def __init__(self) -> None:
        super().__init__()

        self.led = self.Block(IndicatorLed())
        self.gnd = self.Export(self.led.gnd, [Common])
        self.signal = self.Export(self.led.signal, [Input])

        self.conn = self.Block(Fpc050SocketTabPair(2), external=True)
        self.export_tap(self.gnd.net, self.conn.pins.request("1"))
        self.export_tap(self.signal.net, self.conn.pins.request("2"))
```

- These are defined `Block`s that have their subcircuits inside and exported ports crossing the physical board boundary.
- These use a `SubboardConnectorPair` block (like `Fpc050SocketTabPair`) to define the physical connector pair.
  - `SubboardConnectorPair` are similar to `PassiveConnector`, with `Passive` typed ports. 
    - Typed ports (like `Ground` or `VoltageSink`) internally contain a `Passive` `net` which can be attached to the connector's `Passive` ports.
  - `self.Export(...)` creates a Port on the Block that is connected to (and takes on the type) of the inner port.
  - `self.export_tap` behaves similar to `self.connect`, but attaches the inner port to the outer port without propagating parameter values (non-physical attachment).
    Conceptually, the connector taps onto (or hangs off) the parameter-propagating Export connection.

### Overriding Values / "Waiving" ERCs

Some of the electrical modeling may have overly strict limits or overly broad operating parameters resulting in compiler errors from ERC failures, use refinements to override their values.

```python
class_refinements=[
    (Neopixel, ["pwr", "voltage_limits"], Range(3.0, 5.5)),  # kinda works-ish at 3.3v
]
```

- Values can be inspected via:
  - CLI compiler error messages for values failing constraints,
  - the IDE,
  - or, the .json generated during compilation which contains the entire compiled / solved design.

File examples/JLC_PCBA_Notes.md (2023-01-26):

## Process for generating a JLC pick-and-place file

### Exporting data

From EDG: export with NetlistGenerator.py set to refdes mode and LCSC parts

From KiCad: export both BoM and footprint position files (in CSV)

### Post-processing data

#### Script

The `jlcpcb_pcba_postprocess.py` automates the below steps.

Note that other plugins depend on a schematic with a LCSC field, whereas currently this writes the LCSC part number in the value field.

#### Manual post-processing 

Post-process BoM CSV:

- Replace `;` with `,` to make it an actual CSV
- Rename these columns:
  - Designation -> JLCPCB Part #
- Add a Comment column

Post-process position CSV:

- Rename these columns:
  - Ref -> Designator
  - PosX -> Mid X
  - PosY -> Mid Y
  - Rot -> Rotation
  - Side -> Layer  
- Diodes may need a 180 rotation

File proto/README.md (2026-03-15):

IR definition in protocol buffer format.

You will need [mypy-protobuf](https://github.com/dropbox/mypy-protobuf) (to generate type stubs) and protoletariat (post-processing to use relative imports)
```commandline
pip install grpcio-tools
pip install mypy-protobuf
pip install protoletariat
```

To compile, run in this directory:

```
protoc --proto_path=. --python_out=../edg --mypy_out=../edg edgir/*.proto edgrpc/*.proto
protol --in-place --python-out ../edg protoc --proto-path=. edgir/*.proto edgrpc/*.proto
```

If installing with `pip` under Ubuntu, you may have to invoke `pip` with `sudo` so the executables are found in your PATH. 

The current committed stubs are generated with mypy-protobuf 3.0.0.
pip can be forced to install particular versions of packages, such as with: 
```
pip install --force-reinstall 'mypy-protobuf==3.0.0'
```

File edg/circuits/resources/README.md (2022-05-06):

This folder contains parts tables used by some components.

## JLC Parts Library
The full table (274MB) was downloaded on April 24, 2022, and is [available on the Internet Archive here](https://web.archive.org/web/20220424072635/https://jlcpcb.com/componentSearch/uploadComponentInfo).

Only a pruned version is included in this repository, to reduce cloning and compilation time.
See jlcprune.py for the script used to produce the pruned file.

## DigiKey Parts Library (deprecated)
Some older example designs used parts tables from DigiKey using their CSV export.
A strict reading of their terms of service implies that we cannot redistribute those, so those were never made public.

In any case, the export format has also changed, and newly downloaded tables will not work with the existing component parsers. 

For context, these tables were downloaded between Fall 2019 and Spring 2020.

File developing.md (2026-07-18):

# Developer Documentation

## Quick Reference Commands

### Static checking
This project has optional static typing annotations for Python which can be checked using [mypy](http://mypy-lang.org/).
If you have mypy installed (you may also need the type stubs for protobuf: `pip install mypy-protobuf`), you can typecheck code using:

```
mypy .
```

Or faster, with mypy in daemon mode:
```
dmypy run .
```

Or, using the [Mypy plugin for Intellij](https://plugins.jetbrains.com/plugin/13348-mypy-official-).

### Unit testing
```
python -m unittest discover
```

Or, to run tests for a specific package (eg, `edg_core` in this command):
```
python -m unittest discover -s edg.core -t .
```

Or, to run one specific test:
```
python -m unittest examples.test_blinky.BlinkyTestCase.test_design_complete
```

### Compiling the Compiler
A pre-compiled compiler JAR is included.
If you have not modified any of the .scala files, you do not need to recompile the compiler.

1. [Download and install sbt](https://www.scala-sbt.org/download.html), a build tool or Scala.
2. In the `compiler/` folder, run `sbt assembly` to compile the compiler JAR file.
   The system will automatically prefer the locally built JAR file over the pre-compiled JAR and indicate its use through the console.
3. Optionally, to commit a new pre-compiled JAR, move the newly compiled JAR from `compiler/target/scala-*/edg-compiler-assembly-*-SNAPSHOT.jar` to `edg_core/resources/edg-compiler-precompiled.jar`.

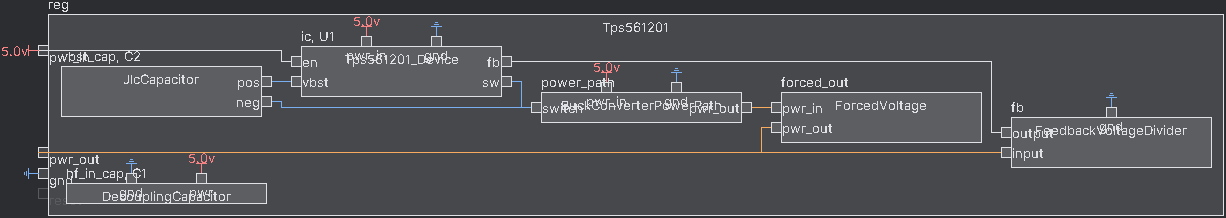
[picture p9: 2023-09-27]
docs/ide/ide_buck_internal.png

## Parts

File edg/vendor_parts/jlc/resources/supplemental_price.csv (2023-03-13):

LCSC Part | First Category | Second Category | MFR.Part | Package | Solder Joint | Manufacturer | Library Type | Description | Datasheet | Price | Stock
C2678152 | ICE40UP5K-SG48I |  |  |  |  |  |  |  |  | 0:9.15 | Digikey
C2962219 | X1270WVS-2x05B-6TV01 |  |  |  |  |  |  |  |  | 0:0.2774
C5118826 | MDBT50Q-1MV2 |  |  |  |  |  |  |  |  | 0:9.94 | Digikey
18010 | 18010 |  |  |  |  |  |  |  |  | 0:6.58 | AliExpress
ESP32-WROVER-DEV | ESP32-WROVER-DEV |  |  |  |  |  |  |  |  | 0:8.21 | AliExpress
C8734 | STM32F103C8T6 |  |  |  |  |  |  |  |  | 0:2.4824

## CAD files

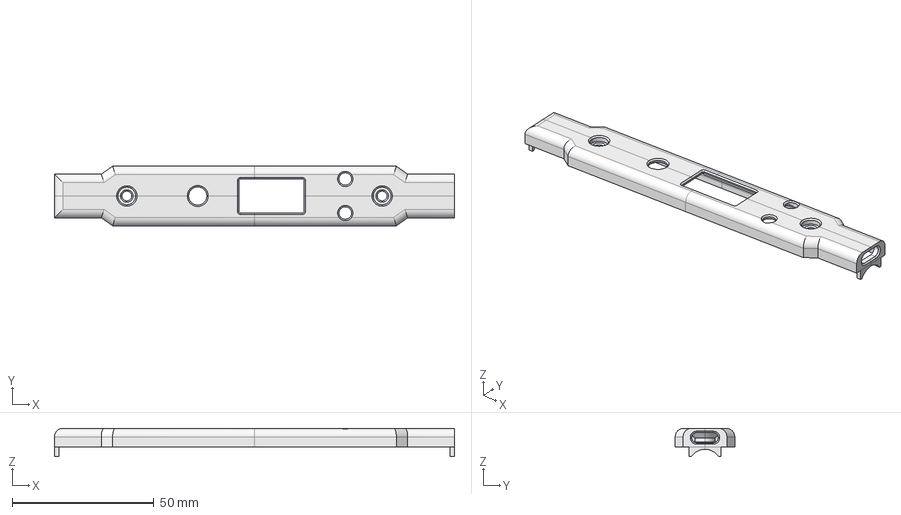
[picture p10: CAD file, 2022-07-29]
examples/Multimeter/mechanical/top-case.FCStd
141.0 x 21.0 x 10.0 mm

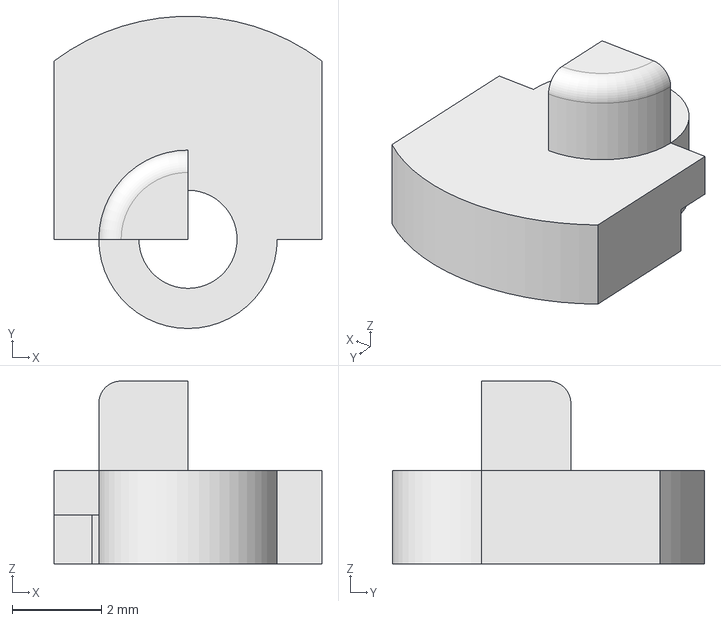
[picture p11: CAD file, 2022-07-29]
examples/Multimeter/mechanical/button-small.FCStd
6.00 x 7.00 x 4.10 mm

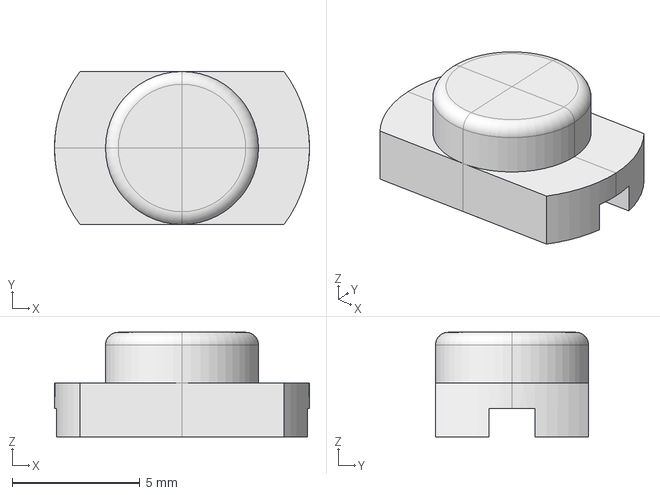
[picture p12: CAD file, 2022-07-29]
examples/Multimeter/mechanical/button.FCStd
10.0 x 6.00 x 4.10 mm

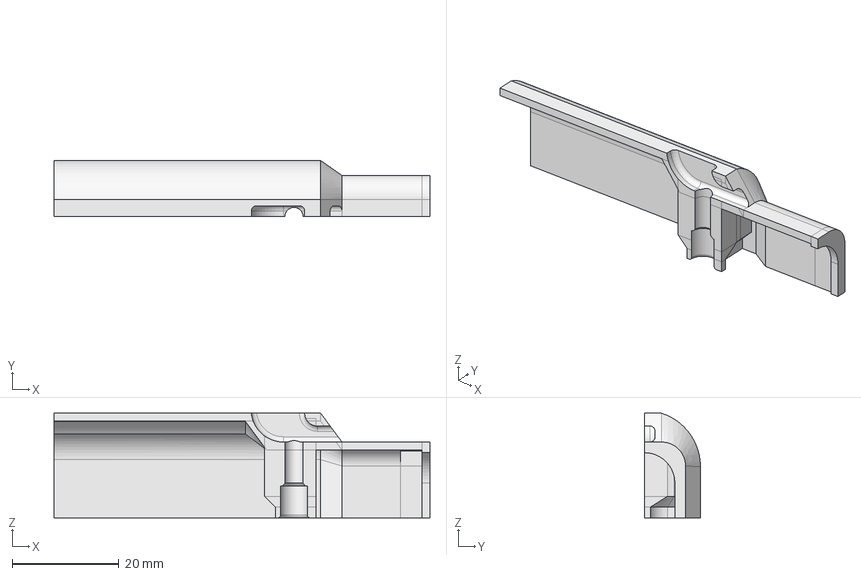
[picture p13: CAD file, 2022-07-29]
examples/Multimeter/mechanical/bottom-case.FCStd
70.5 x 10.5 x 19.6 mm

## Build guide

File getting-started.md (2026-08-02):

# Getting Started Tutorial

Introductory tutorial and example starter project, building towards a basic mechanical keyboard macropad.

The overall workflow is:
1. Write HDL code to define a top-level design, using library blocks.
2. Compile the design to generate a netlist and BoM data.
3. Load the netlist into KiCad PCB Editor for layout and routing.
4. Optionally, iterate without losing layout progress.

### Reference Document
While this getting started guide is meant to be self-contained, you may also find the [reference document](reference.md) helpful, especially as you build designs outside this tutorial.

## Goals
The main goal of this HDL are:
- enable libraries of subcircuits, through concepts supporting direct (without modification) reuse of subcircuit blocks, even in projects with different requirements
- automate straightforward calculations, like resistor sizing
- automate passive parts selections, like choosing resistors from a parts table
- automate common correctness checks, including voltage limits, current limits, and logic level compatibility

These capabilities will be shown throughout this tutorial. 

## Setup

```
pip install edg
```

On first run, the system will automatically download a compatible Java runtime for the core compiler.

## Core concepts
The core abstraction is the hierarchical block diagram, shown here using an example design of a microcontroller driving an LED.

In conventional schematic tools, such a design could be a flat schematic, consisting of the microcontroller module, LED, and resistor:  
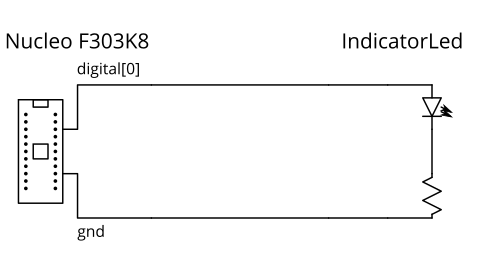
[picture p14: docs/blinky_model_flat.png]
Blinky Hierarchy Block Diagram


Modern tools have the concept of hierarchy blocks, where a block could be a subcircuit:
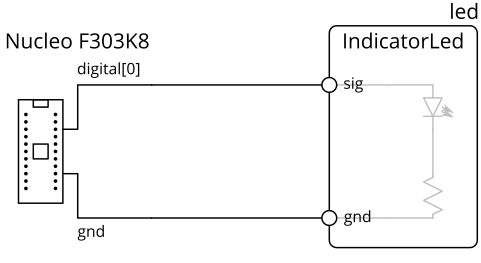
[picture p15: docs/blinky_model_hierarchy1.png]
Blinky Hierarchy Block Diagram


In the example above, the LED-resistor subcircuit is contained within a block, which can be manipulated as a unit, and exposes ports (circles on the diagram) while encapsulating internal pins.

Generalizing this model, components are blocks too, and component pins are also block ports:  
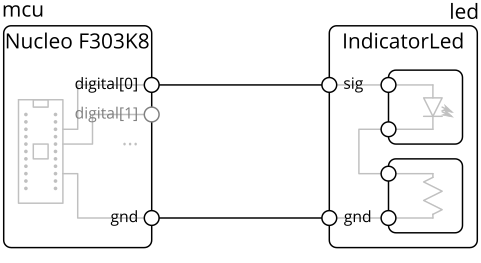
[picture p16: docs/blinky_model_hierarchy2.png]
Blinky Hierarchy Block Diagram


The main concepts our model extends on top of the simple hierarchy blocks above are **parameters** and **generators**.

**Parameters** are variables that can be attached to blocks and ports.
For example, a digital IO, like the `mcu`'s `digital[0]` in the example above, would have parameters like voltage limits, output voltage range, and logic thresholds.
This allows for automated design correctness check of basic datasheet parameters (think ERC++) and provides a foundation for generators.

**Generators** allow a block's internal contents to be constructed by code, possibly based on parameters on it and its ports.
For example, the `IndicatorLed` block automatically sizes the resistor based on the input voltage on the `sig` pin, and the DC-DC converter block automatically sizes inductors and capacitors based on the target output voltage and current.

<details> <summary>Under the hood: from connections to links</summary>

While the user-facing HDL design model is connections between ports, the internal model expands these connections into **links**.
Links are a block-like construct (diamonds in the diagram) that define how parameters propagate between ports and constraints on them.
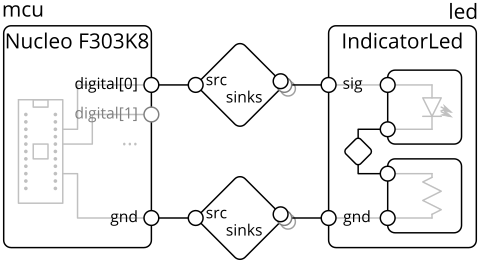
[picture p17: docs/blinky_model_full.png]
Blinky Hierarchy Block Diagram


Continuing the digital IO example, the link checks the output thresholds against the input thresholds and calculates the full range of voltage levels given all connected drivers.
These could be viewed as a block-like object (diamonds on the diagram) instead of direct wire connections:  

All links are fully defined in the same HDL code, and you can inspect the link definitions of included port types to see how they work and what they check.
You can also write custom links and ports, though this will be unnecessary for most users.

</details>

### Hardware Description Language (HDL)
To support user-defined computation of parameters and generator blocks, the design system is implemented as a _hardware description language_ (HDL).
That is, blocks are "placed" or instantiated, and their ports are connected, through lines in code instead of GUI actions in a graphical schematic.

### Optional PyCharm IDE with Graphical Editor
We have also built a basic IDE (as a PyCharm plugin, must be compiled locally) that provides some basic graphical integrations for working with HDL. 
Specifically, it:
- generates a block diagram visualization of the design
- allows inspection of solved / computed parameters in the design
- provides schematic-like graphical edit actions to insert HDL

The graphical edit actions have significant limitations (and probably bugs / unhandled edge cases) compared to the full HDL and are best suited for simple designs or as a learning tool.
It sees only minimal maintenance.
**Consider it more of a tech demonstrator and proof-of-concept**.

If you want to try it, see its [README](https://github.com/BerkeleyHCI/edg-ide/blob/main/README.md) for setup instructions. 

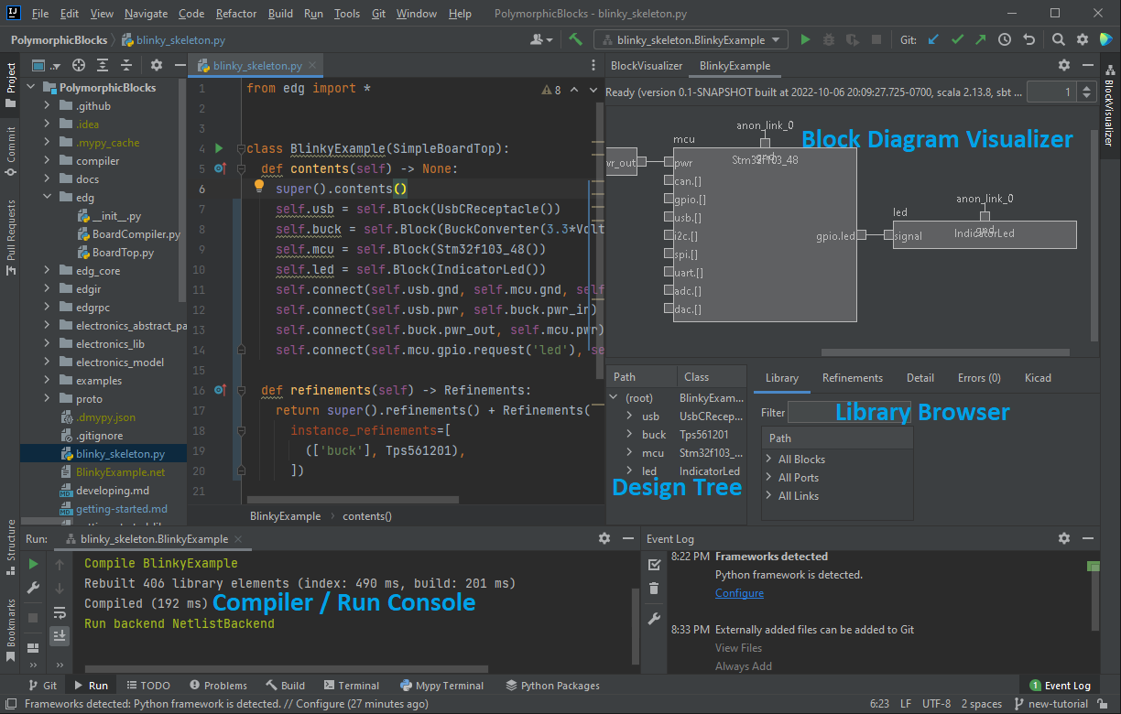
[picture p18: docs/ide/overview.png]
Annotated IDE screen


The IDE has these major components:
- **Block Diagram Visualization**: shows the compiled design visualized as a block diagram.
  - **Design Tree**: shows the compiled design as a tree structure of the block hierarchy.
- **Library Browser**: shows all the library blocks, ports, and links.
  The text box at the top allows filtering by keyword.
  - The preview box on the right shows more information on the selected library block, including docstring (if available), instantiation parameters, and block diagram preview.
- **Compiler / Run Console**: shows the compilation log, including any errors and prints from Python as HDL runs.

The rest of this tutorial focuses on the HDL, but equivalent graphical edit actions (where possible) are described in expandable boxes.
**As you go through the tutorial, you can write the code shown in the code blocks or follow the graphical actions.**

## A top-level design: Blinky
_In this example, we will create a basic LED controlled by a microcontroller._

Start by creating a `blinky.py`, and filling it with this skeleton code:

```python
from edg import *

class BlinkyExample(SimpleBoardTop):
    def contents(self) -> None:
        super().contents()
        # your implementation here

if __name__ == "__main__":
    compile_board_inplace(BlinkyExample)
```

- `from edg import *` brings in the base classes for circuit construction, like `SimpleBoardTop`.
- `class BlinkyExample` contains the (top-level) circuit you're going to build, and it extends the top-level block base class `SimpleBoardTop`.
  It's empty for now, but we'll fill it in the next section.
  - `SimpleBoardTop` provides some default component mappings and relaxes some strict constraints that do not matter for maker-type boards.
- `compile_board_inplace(...)` invokes the circuit generator given the top-level design (`BlinkyExample`).
  This is the starting point that allows the file to run as a Python script, and you can treat it as magic.

Try building the example now.

**If using the command line**: 
1. Run `python blinky.py`.
   If all worked, this should create a folder `BlinkyExample` with a netlist `BlinkyExample.net` inside.

**If using the IDE**: 
1. Click the run icon run icon in the gutter (with the line numbers) next to `class BlinkyExample`:

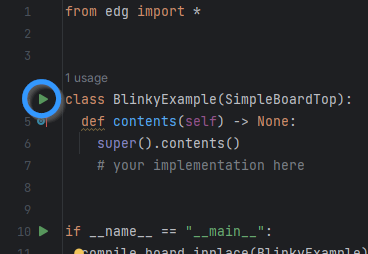
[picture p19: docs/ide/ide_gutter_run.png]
run in IDE
   
   
   _Make sure that you're using the run icon associated with `class BlinkyExample`, not the file, and not `if __name__ == "__main__"`._
2. Then from the menu, click the Run option.  
   run menu
   > **Tip**: Next time, you can rebuild the design by re-running the last selected run configuration with hotkey **Shift+F10** (Windows) or **Ctrl+R** (MacOS).

   > **Recompilation caching behavior**: the IDE only re-compiles block classes when it detects changes in its source (including some dependencies), but this misses edge cases including:
   >
   > - Any changes outside the class, even if the code is called by the class.
   > - Changes to supporting files (such as part tables and imported schematics), even if they are referenced in the class.
   > - Changes to default values of `__init__` arguments.
   >
   > You can clear all compiled blocks through main menu > Tools > Empty Block Cache.
3. The design should build, and you should get a run log that looks something like:
   ```
   Starting compilation of blinky.BlinkyExample
   Using interpreter from configured SDK [...]
   [... lots of compilation output here ...]
   Completed: generate netlist: wrote [...]
   Completed: generate BOM: write [...]
   Done
   ```
4. Some options (like where the netlist is generated into) can be modified via the run options at the top right:  
   run menu

### Creating the microcontroller and LED
For this simple example, we connect an LED to a self-powered Xiao Rp2040 microcontroller dev board.

**Make these changes** to the `contents` method:
```diff
  def contents(self) -> None:
      super().contents()
-     # your implementation here
+     self.mcu = self.Block(Xiao_Rp2040())
+     self.led = self.Block(IndicatorLed())
```

<details> <summary>Alternatively, with IDE graphical edit actions</summary>

Let's start by instantiating the USB type-C receptacle through graphical operations in the IDE.
1. In the Library Browser, search for the block (here, `Xiao_Rp2040`) using the Filter textbox:  
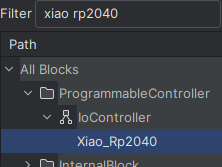
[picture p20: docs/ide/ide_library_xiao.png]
Library filtering by xiao
   

   > The library icons have these meanings:
   > - Folder (category): this "block" is actually a category organizer and cannot be instantiated.
   > - Abstract Type (abstract type): this block is an abstract type.
   >   Abstract blocks can be instantiated and will be discussed more later.

2. Double-click the library entry.
   This will insert the code to instantiate the block as a _live template_, code with template fields you can fill in:  
   Live template example  
   **Editing outside the currently active template field (boxed in blue) will break off and cancel the template.**
   **Moving the cursor outside the currently active template field, either using the mouse or keyboard arrows, is discouraged.**
3. Name the block `mcu`, by typing it into the first template field.  
   Live template example
4. Then press [Tab] through the end of the template (leaving the other fields empty, they're optional).
5. Once you commit the live template, the block will appear in the block diagram visualizer.
    - The hatched pattern (diagonal lines) in the block diagram visualizer indicates that the block may be out-of-sync with the code until the next re-compile.

> While the template is active, you can:
> - Press [Enter] or [Tab] to move to the next template field.
>   Validation may prevent moving to the next field, for example if the name field is invalid.
> - Tabbing past the last field will commit the template.
> - Press [Shift+Tab] to move back to the previous template field.
> - Use [Alt+Click] to move the template to another place in the code.
>   If the selected place isn't valid, the template will snap to a valid location.
> - Press [Esc] to cancel the template, ending the editing but leaving the code in place.
>   Canceling a blank template deletes the inserted code.

**Repeat for the LED** (`IndicatorLed`, named `led`).

</details>

`self.Block(...)` creates a sub-block in `self` (the current hierarchy block being defined).
It must be assigned to an instance variable (in this case, `mcu`), which is used as the name sub-block.

If using the IDE: the compiled block diagram should look like:  
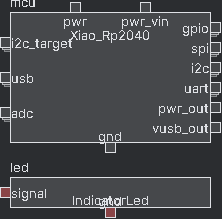
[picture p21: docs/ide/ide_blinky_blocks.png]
Blink diagram with blocks only
  
With something on your screen now, you can zoom in and out of the visualization using the mousewheel, or pan by clicking and dragging.

As the design is incomplete, **it is expected that there will be errors**.
The red ports indicate ports that need to be connected, but aren't.
We'll fix that next.

### Connecting blocks
Blocks alone aren't very interesting, and they must be connected to be useful.
First, we need to connect the power and ground between the devices.

**Make these changes** to the `contents` method:
```diff
  def contents(self) -> None:
      super().contents()
      self.mcu = self.Block(Xiao_Rp2040())
      self.led = self.Block(IndicatorLed())
+     self.connect(self.mcu.gnd, self.led.gnd)
```

<details> <summary>Alternatively, with IDE graphical edit actions</summary>

1. Double click any of the ground ports (say, `mcu.gnd`).
   This starts a connection operation, which dims out the ports that cannot be connected:  
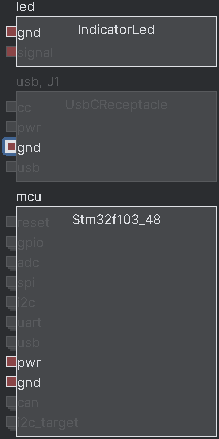
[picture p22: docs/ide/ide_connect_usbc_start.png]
Connection beginning
   
2. Select (single click) the other ports to be connected (here, just `led.gnd`).
3. Double-click anywhere (within a block) to complete and insert the connections as a live template.
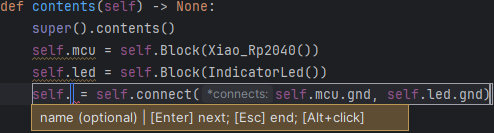
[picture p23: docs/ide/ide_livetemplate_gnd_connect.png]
Connection live template
   
   > - Double-click on a port to simultaneously select that port and complete and insert the connection.
   > - Alternatively, cancel a connect operation by pressing [Esc] while the block diagram visualizer is selected.
4. The name template field is optional, leave it blank and [Tab] past it.
   > - Like the block instantiation, you can move the live template with [Alt+Click].
5. Once you commit the live template, the connection will appear in the block diagram visualizer.

</details>

`self.connect(...)` connects all the argument ports together.
Connections are strongly typed based on the port types: the system will try to infer a _link_ based on the argument port types and count.

Then, we need to connect the LED to a GPIO on the microcontroller.
Make these changes to the `contents` method:

```diff
  def contents(self) -> None:
      super().contents()
      self.mcu = self.Block(Xiao_Rp2040())
      self.led = self.Block(IndicatorLed())
      self.connect(self.mcu.gnd, self.led.gnd)
+     self.connect(self.mcu.gpio.request('led'), self.led.signal)
```

<details> <summary>Alternatively, with IDE graphical edit actions</summary>

1. **Repeat the previous connect process**, but with `mcu.gpio` to `led.signal`.
   The microcontroller GPIO port port array symbol looks different as it is a dynamically sized port array.
   Connections into it port array symbol `request(...)` a new element from the array.

   Graphical port array connect operations are buggy. 
2. Give the GPIO pin an (optional) name `led` by modifying the generated code:
   ```diff
   - self.connect(self.mcu.gpio.request(), self.led.signal)
   + self.connect(self.mcu.gpio.request('led'), self.led.signal)
   ```
   
   Port array element naming has no graphical operation. 

</details>

Microcontroller GPIOs (and other IOs like SPI and UART) are _port arrays_, which are dynamically sized.
Here, we `request(...)` a new GPIO from the GPIO port array, then connect it to the LED.
`request(...)` takes an optional name parameter, the meaning of which depends on the block.

By default, these connections are arbitrarily assigned to microcontroller pins.
However pin assignments can also be manually specified (using this name parameter) to simplify board layout - this will be covered at the end of this tutorial.
 
Port arrays can be connected as a unit, which also propagates the length, though this isn't yet supported with graphical operations.
 
Port arrays behave differently when viewed externally (as we're doing here) and internally (for library builders).
Internal usage of port arrays will be covered later in the library building section.

This should now compile without errors.
The LED subcircuit automatically calculates the resistor specification from the connected microcontroller's GPIO voltage and a builtin wide target current range (1-10mA).
The resistor in the LED subcircuit then chooses a suitable resistor from its parts table.

If using the IDE: the compiled block diagram should look like:
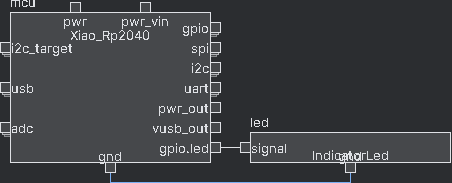
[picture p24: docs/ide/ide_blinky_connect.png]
Fully connected block diagram


## To KiCad Layout

If you have KiCad installed, you can import the design into the layout editor. _KiCad 6.0+ is required, the netlist format is not compatible with 5.x or lower!_

The example-so-far needs the Seeed Studio KiCad footprint library: https://github.com/Seeed-Studio/OPL_Kicad_Library
Don't worry about installing it, in a few sections this will be replaced with a standard STM32.

In the KiCad standalone PCB Editor (layout tool), go to File > Import > Netlist..., and open the netlist file generated.
KiCad will produce an initial placement that roughly clusters components according to their hierarchical grouping:
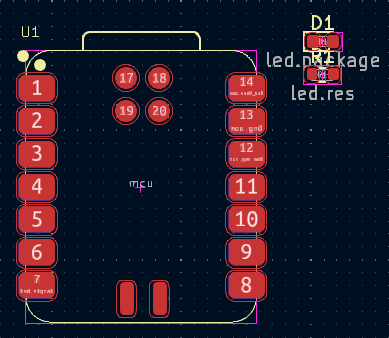
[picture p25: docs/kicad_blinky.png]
Blinky layout with default placement


The generated netlist preserves the design hierarchy.
This works with KiCad 10+'s native design blocks feature (which is somewhat heavyweight) as well as the [Sublayout plugin](https://github.com/ducky64/sublayout) (more lightweight and limited).
Once you complete this keyboard example, check out the [hierarchical layout tutorial](getting_started_hierarchy_layout.md) for hierarchical layout replication.
Some plugins (like Replicate Layout) require a schematic for equivalence validation and cannot be used with this flow.

By default, each footprint's value field is set to the block's full path name, on the F.Fab layer.
This can be useful during placement to understand the function of each component.

As you continue to modify HDL, the unique component identifiers (tstamps) are stable and allows you to update a partial layout with a new netlist.
**Unique component identifiers are generated from Block names, so if HDL names change those footprints will not update.**

Component refdeses are generated in order of block instantiation, depth-first.

## Adding a Switch Matrix Generator
__Now, we'll add a 3x2 switch matrix with just a few lines of code, this is where generators really shine!__

**Make these changes** to the `contents` method:
```diff
  def contents(self) -> None:
      super().contents()
      self.mcu = self.Block(Xiao_Rp2040())
      self.led = self.Block(IndicatorLed())
      self.connect(self.mcu.gnd, self.led.gnd)
      self.connect(self.mcu.gpio.request('led'), self.led.signal)
  
+     self.sw = self.Block(SwitchMatrix(ncols=2, nrows=3))
+     self.connect(self.sw.cols, self.mcu.gpio.request_vector('cols'))
+     self.connect(self.sw.rows, self.mcu.gpio.request_vector('rows'))
```

Array-array connect operations are not supported with graphical edit actions.

`SwitchMatrix` is a generator block that takes the number of columns (width) and rows (height) as parameters and generates the switch matrix (including diodes for multi-key detection).
For keyboard enthusiasts, this generates COL2ROW circuits.

`SwitchMatrix` has two ports, `cols` and `rows`, both of which are port arrays.
Unlike microcontrollers, where the array is defined by its incoming connections (are elements sinks), `SwitchMatrix` port arrays are internally defined (are elements sources) based on the parameters.

Port arrays can be connected to other arrays, forming a parallel connection.
Here, we connect `cols` (and `rows`) to the microcontroller, using `request_vector(...)` to request a new GPIOs the size of the incoming connection.

If we load the netlist into KiCad, we get this:
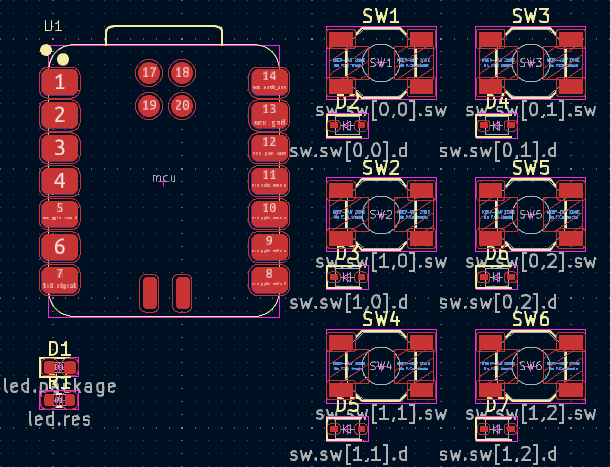
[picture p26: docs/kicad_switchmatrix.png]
Default SwitchMatrix Layout


## Abstract Parts and Refinements
_Tactile switches are probably not what we want for a mechanical keyboard, so we'll fix that here._

Internally, SwitchMatrix uses the abstract `Switch` block, and `SimpleBoardTop` defines a global default mapping `Switch` to a 5.1mm tactile switch.

**Make these changes** to the `contents` method:
```diff
  class BlinkyExample(SimpleBoardTop):
      def contents(self) -> None:
          ...
  
+   def refinements(self) -> Refinements:
+       return super().refinements() + Refinements(
+           class_refinements=[
+               (Switch, KailhSocket),
+           ],
+       )
```

<details> <summary>Alternatively, with IDE graphical edit actions</summary>

1. **Navigate into the switch in the switch matrix hierarchy and select it**.
   It is currently refined to a JlcSwitch, the tactile 5.1mm switch that is part of the JLC basic parts library.

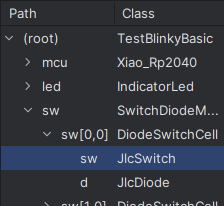
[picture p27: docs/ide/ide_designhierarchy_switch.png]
Switch design hierarchy
   
2. **In the library, search for KailhSocket**, then right-click it and select "Refine class Switch to KailhSocket"

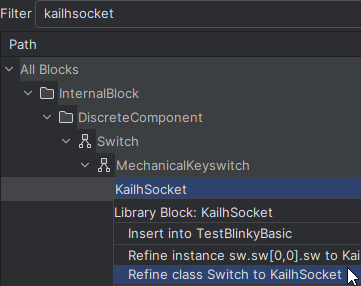
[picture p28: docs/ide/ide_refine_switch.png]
KailhSocket refinement menu
    

</details>

Refinements allow specifying, at the top level, modifications across the design hierarchy.
Here, we override the default Switch refinement to use a mechanical keyswitch socket.

If we load the netlist into KiCad, we get more reasonable components:
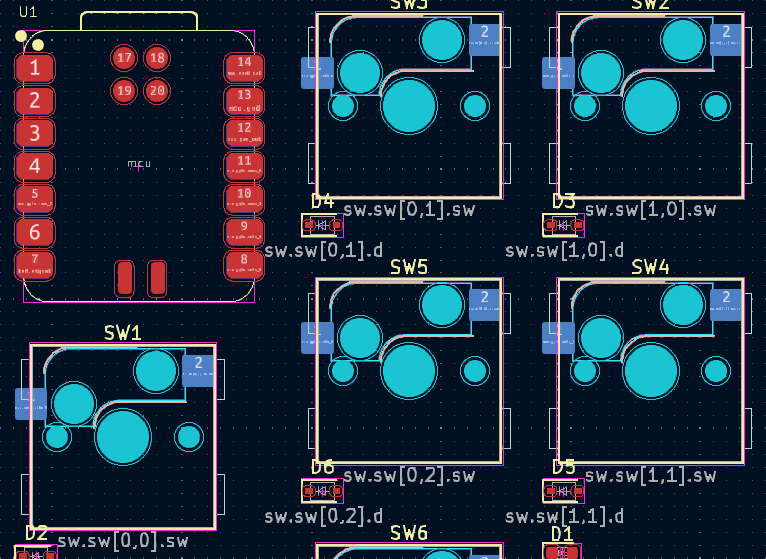
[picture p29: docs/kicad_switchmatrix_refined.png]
Refined SwitchMatrix Layout


After finishing this tutorial, see the [hierarchical layout tutorial](getting_started_hierarchy_layout.md) for speeding up layout using hierarchical layout replication.

You could place and route this board now, get it fabbed, and it will (probably) work.
This design requires footprints from the Keyswitch KiCad Library, available in the KiCad Plugin and Content Manager.

## Towards a Discrete Microcontroller 
_So far, we have used a microcontroller development board, which while convenient, may not be the best choice from a cost and size perspective. Here, we'll replace it with a discrete chip and supporting component._

Because blocks encapsulate their subcircuits, using a discrete microcontroller is as easy as a development board from an HDL perspective.

**Make these changes** to the design:
```diff
  class BlinkyExample(SimpleBoardTop):
      def contents(self) -> None:
          super().contents()
-         self.mcu = self.Block(Xiao_Rp2040())
+         self.mcu = self.Block(IoController())
          self.led = self.Block(IndicatorLed())
          self.connect(self.mcu.gnd, self.led.gnd)
          self.connect(self.mcu.gpio.request('led'), self.led.signal)
      
          self.sw = self.Block(SwitchMatrix(ncols=2, nrows=3))
          self.connect(self.sw.cols, self.mcu.gpio.request_vector('cols'))
          self.connect(self.sw.rows, self.mcu.gpio.request_vector('rows'))
    
      def refinements(self) -> Refinements:
          return super().refinements() + Refinements(
              class_refinements=[
+                 (IoController, Stm32f103),
                  (Switch, KailhSocket),
              ],
          )
```

Refactoring and delete operations are not supported with graphical edit actions.
However, you can delete lines of code, then recompile, then insert new blocks and connections using the graphical edits flow.

Instead of directly replacing the microcontroller, we replace it with the `IoController` abstract block, which all microcontrollers implement.
Then, we refine that to a specific microcontroller, here the STM32F103.

If we recompile this now, it will give errors since the microcontroller has no power source.

### Adding Supporting Components

We'll add in the USB type-C port that was previously part of the Xiao, and connect its power and data lines.
**Make these changes** to the `contents` method:
```diff
  class BlinkyExample(SimpleBoardTop):
      def contents(self) -> None:
          super().contents()
          
+         self.usb = self.Block(UsbCReceptacle())
          
          self.mcu = self.Block(IoController())
+         self.connect(self.usb.gnd, self.mcu.gnd)
+         self.connect(self.usb.pwr, self.mcu.pwr)
+         self.connect(self.usb.usb, self.mcu.usb.request('usb'))
    
          self.led = self.Block(IndicatorLed())
          self.connect(self.mcu.gnd, self.led.gnd)
          self.connect(self.mcu.gpio.request('led'), self.led.signal)
      
          self.sw = self.Block(SwitchMatrix(ncols=2, nrows=3))
          self.connect(self.sw.cols, self.mcu.gpio.request_vector('cols'))
          self.connect(self.sw.rows, self.mcu.gpio.request_vector('rows'))
```

We will still get errors if we recompile, since USB provides 5v, while the STM32F103 is a 3.3v part.
We'll insert a simple linear regulator, a step-down voltage converter.
**Make these changes** to the `contents` method:
```diff
  class BlinkyExample(SimpleBoardTop):
      def contents(self) -> None:
          super().contents()
          
          self.usb = self.Block(UsbCReceptacle())
          
+         self.reg = self.Block(LinearRegulator(3.3*Volt(tol=0.05)))
+         self.connect(self.usb.gnd, self.reg.gnd)
+         self.connect(self.usb.pwr, self.reg.pwr_in)
          
          self.mcu = self.Block(IoController())
          self.connect(self.usb.gnd, self.mcu.gnd)
-         self.connect(self.usb.pwr, self.mcu.pwr)
+         self.connect(self.reg.pwr_out, self.mcu.pwr)
          self.connect(self.usb.usb, self.mcu.usb.request('usb'))
    
          self.led = self.Block(IndicatorLed())
          self.connect(self.mcu.gnd, self.led.gnd)
          self.connect(self.mcu.gpio.request('led'), self.led.signal)
      
          self.sw = self.Block(SwitchMatrix(ncols=2, nrows=3))
          self.connect(self.sw.cols, self.mcu.gpio.request_vector('cols'))
          self.connect(self.sw.rows, self.mcu.gpio.request_vector('rows'))
```

Once we recompile, it should complete with no errors.

If we load the netlist into KiCad, we get the discrete microcontroller and its bundles of capacitors.
Because we used USB, the microcontroller subcircuit also automatically generated a crystal to meet USB timing requirements.
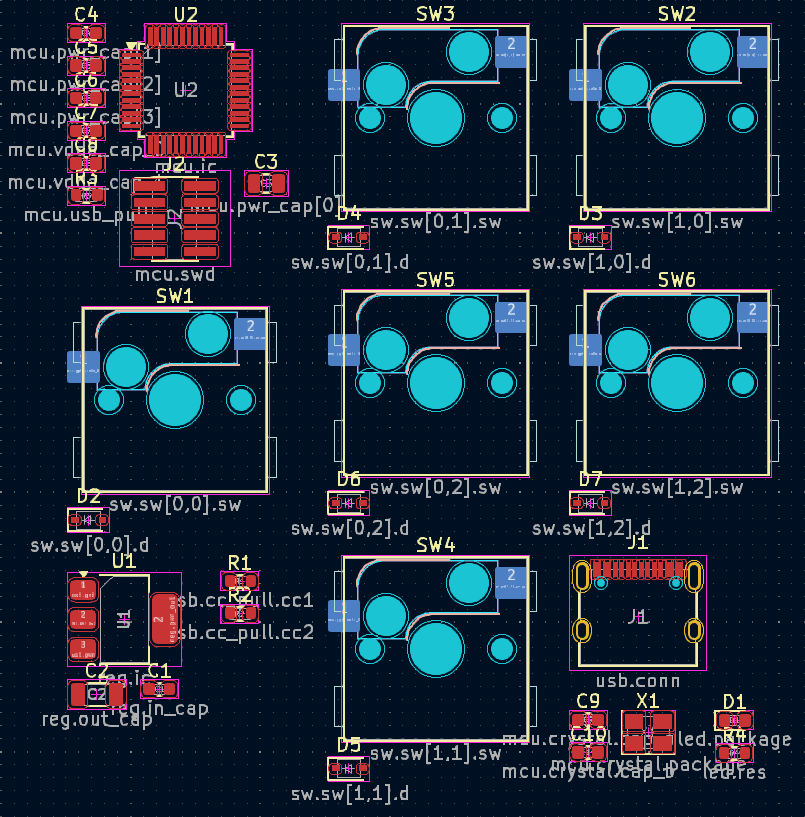
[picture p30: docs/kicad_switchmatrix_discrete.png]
Refined SwitchMatrix Layout


After finishing this tutorial, see the [hierarchical layout tutorial](getting_started_hierarchy_layout.md) for speeding up layout by loading an existing microcontroller block layout.

## Adding addressable RGBs with Mixins
Electronics sometimes have variations-on-a-theme with a common base, for example adding addressable RGBs to the switch matrix without redefining it completely.
This is supported through **mixins**.

**Make these changes** to the `contents` method:
```diff
  class BlinkyExample(SimpleBoardTop):
      def contents(self) -> None:
          super().contents()
          
          self.usb = self.Block(UsbCReceptacle())
          
          self.reg = self.Block(LinearRegulator(3.3*Volt(tol=0.05)))
          self.connect(self.usb.gnd, self.reg.gnd)
          self.connect(self.usb.pwr, self.reg.pwr_in)
          
          self.mcu = self.Block(IoController())
          self.connect(self.usb.gnd, self.mcu.gnd)
          self.connect(self.reg.pwr_out, self.mcu.pwr)
          self.connect(self.usb.usb, self.mcu.usb.request('usb'))
    
          self.led = self.Block(IndicatorLed())
          self.connect(self.mcu.gnd, self.led.gnd)
          self.connect(self.mcu.gpio.request('led'), self.led.signal)
      
          self.sw = self.Block(SwitchMatrix(ncols=2, nrows=3))
          self.connect(self.sw.cols, self.mcu.gpio.request_vector('cols'))
          self.connect(self.sw.rows, self.mcu.gpio.request_vector('rows'))
          
+         sw_npx = self.sw.with_mixin(SwitchMatrixNeopixels(npx_order="row_snake"))
+         self.connect(self.usb.gnd, sw_npx.npx_gnd)
+         self.connect(self.usb.pwr, sw_npx.npx_pwr)
    
+         self.npx_shift = self.Block(L74Ahct1g125())
+         self.connect(self.usb.gnd, self.npx_shift.gnd)
+         self.connect(self.usb.pwr, self.npx_shift.pwr)
+         self.connect(self.mcu.gpio.request('npx'), self.npx_shift.input)
+         self.connect(self.npx_shift.output, sw_npx.npx_din)

    def refinements(self) -> Refinements:
        return super().refinements() + Refinements(
            class_refinements=[
                (IoController, Stm32f103),
                (Switch, KailhSocket),
+               (Neopixel, Ws2812c_2020),
            ],
        )
```

Mixins are not supported with graphical edit actions.

Mixins are a way to require additional functionality (including ports and parameters) on a base abstract block.

Mixins are also used elsewhere, such as adding optional IO types to IoController (like CAN or the requirement for onboard WiFi) or adding requiring a switch port on a rotary encoder.

We have also added a buffer (`L74Ahct1g125`) to shift the 3.3v logic level of the microcontroller to the higher data voltage required by the addressable RGBs.
The RGBs datasheet defines their input thresholds as incompatible with 3.3v and this will generate ERC errors without the buffer.
Go ahead and try it!

We also add a refinement to use the `Ws2812c_2020`, an 0808-size addressable RGB LED.
The `SK6812-Mini-E`, a through-board addressable LED commonly used on mechanical keyboards, is also part of the HDL library, but requires the [examples footprint library](examples/edg.pretty). 

## Implicit Connections
_The code is starting to get a bit long and tedious. We'll refactor that using implicit scopes, a syntactic sugar construct, to make it shorter and more readable._

**Replace** the `contents` method:
```python
class BlinkyExample(SimpleBoardTop):
    def contents(self) -> None:
        super().contents()
        
        self.usb = self.Block(UsbCReceptacle())
        
        self.reg = self.Block(LinearRegulator(3.3*Volt(tol=0.05)))
        self.connect(self.usb.gnd, self.reg.gnd)
        self.connect(self.usb.pwr, self.reg.pwr_in)
        
        with self.implicit_connect(
            ImplicitConnect(self.reg.pwr_out, [Power]),
            ImplicitConnect(self.reg.gnd, [Common]),
        ) as imp:
            self.mcu = imp.Block(IoController())
            self.connect(self.usb.usb, self.mcu.usb.request('usb'))
      
            self.led = imp.Block(IndicatorLed())
            self.connect(self.mcu.gpio.request('led'), self.led.signal)
      
            self.sw = self.Block(SwitchMatrix(ncols=2, nrows=3))
            self.connect(self.sw.cols, self.mcu.gpio.request_vector('cols'))
            self.connect(self.sw.rows, self.mcu.gpio.request_vector('rows'))
        
        with self.implicit_connect(
            ImplicitConnect(self.usb.pwr, [Power]),
            ImplicitConnect(self.usb.gnd, [Common]),
        ) as imp:
            sw_npx = self.sw.with_mixin(SwitchMatrixNeopixels(npx_order="row_snake"))
            self.connect(self.usb.gnd, sw_npx.npx_gnd)
            self.connect(self.usb.pwr, sw_npx.npx_pwr)
      
            self.npx_shift = imp.Block(L74Ahct1g125())
            self.connect(self.mcu.gpio.request('npx'), self.npx_shift.input)
            self.connect(self.npx_shift.output, sw_npx.npx_din)
```

Refactoring operations are not supported with graphical edit actions.
The IDE is not implicit-scope-aware for graphical edit actions.

The implicit scope defines the connections to make and the conditions for which ports to connect (through tags):

```python
with self.implicit_connect(
    ImplicitConnect(self.reg.pwr_out, [Power]),
    ImplicitConnect(self.reg.gnd, [Common]),
) as imp:
    # any blocks here instantiated with imp.Block(...) instead of self.Block(...)
    # will have Power-tagged ports connected to self.reg.pwr_out
    # and Common-tagged ports connected to self.reg.gnd
```

> When blocks define ports, they can associate tags with them to specify implicit connectivity.
> To prevent errors, all ports with tags are required to be connected, either implicitly (as in this section) or explicitly (through `connect` statements).
>
> The most common tags are `Power` (for a general positive voltage rail) and `Common` (for ground).

Inside an implicit connection block, only blocks instantiated with `imp.Block(...)` have implicit connections made.

There is also a more complex `self.chain(...)` construct allowing for very compact HDL, detailed in the [reference document](reference.md).

### Explicit Pin Assignments
While `IoController` automatically assigns IO pinnings according to the capabilities of each chip, it does not have access to layout data to do physically-based pin assignment.
However, it does define a `pin_assigns` parameter (as an array-of-strings) which allows specifying a pin number (on the footprint) or pin name (eg, `GPIO3` - format specific to each microcontroller) for each requested pin.

We can also force parameter values through the refinements system, using `instance_values`.
Let's arbitrarily choose sequential pins:
**Add a pin assignment for the STM32 in the refinements section**:
```diff
  class BlinkyExample(SimpleBoardTop):
      def contents(self) -> None:
        ...
        
      def refinements(self) -> Refinements:
          return super().refinements() + Refinements(
              ...
+             instance_values=[
+                 (['mcu', 'pin_assigns'], [
+                     'led=10',
+                     'cols_0=16',
+                     'cols_1=17',
+                     'rows_0=18',
+                     'rows_1=19',
+                     'rows_2=20',
+                 ])
              ])
```

Each pin assignment entry is specified as `pin=num`.
`pin` is the name of the requested pin (the `request(...)` argument for single element requests, or the argument plus a `_index` for vector requests).

## Next: Hierarchical Layout
Continue to the [hierarchical layout tutorial](getting_started_hierarchy_layout.md) for importing the generated netlist into KiCad PCB layout and using the hierarchical structure to speed up layout through reuse.

Or, continue to [the library block definition tutorial using KiCad schematic import](getting_started_schimport.md).

### Additional Resources
For some more complex examples of boards designed in this HDL, check out:
- [Keyboard](examples/test_keyboard.py): the fabbed-out version of this example, with a few more features and different choices of parts.
- [LED Matrix](examples/test_ledmatrix.py): a charlieplexed LED matrix, using a parameterized charlieplexing LED array generator.
- [Seven Segment Clock](examples/test_seven_segment.py): an IoT (ESP32S3) seven-segment LED clock, using individually-addressable RGBs for each segment.
- [Simon Game](examples/test_simon.py): an implementation of the Simon electronic game, that uses 12v dome buttons and includes the needed power conversion circuitry.

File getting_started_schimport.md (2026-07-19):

# Getting Started Tutorial: Schematic-Defined Library Blocks
_In this section, we build a graphical-schematic-defined HX711-based load cell amplifier subcircuit block and add it to our board._

> This section describes how to define a block in KiCad's graphical schematic editor and import it into an HDL flow.
> Blocks can also be defined in HDL using the same constructs used to define a board, which is covered in the [next section](getting_started_library.md).
>
> While defining blocks in HDL provides the most programming power, schematics can be a better option for blocks with complex connectivity or where the graphical arrangement is meaningful, in particular analog subcircuits.
> Graphical schematics may also be a more familiar interface and may be a good choice where programmatic generation is not necessary.
> 
> Schematic-defined blocks can make use of HDL library blocks (as schematic components), including all the automation (like automatic parts selection from a parts table) those libraries provide. 

### Dragons be Ahead
Library block definition is a less polished and more complex experience than building boards using existing library blocks.

## Schematic Definition
**Start by drawing the application schematic for the HX711**, as described in Figure 4 of its [datasheet](https://cdn.sparkfun.com/datasheets/Sensors/ForceFlex/hx711_english.pdf).

For common parts like capacitors, resistors, and transistors, we use the generic built-in KiCad symbols, which ultimately map down to HDL library blocks with parts selection automation.
A full list is available in the [reference section](#reference).
Parts where there isn't a corresponding library block can instead be defined with a footprint and pinning (like the HX711 chip here).

Hierarchical labels are used to define the block's boundary ports (electrical interface).

Our finished schematic looks like this and is available in [examples/resources/Hx711.sch](examples/resources/Hx711.sch):  
HX711 schematic

A few notes here:
- Labels like GND and VCC work as expected within this block.
- True global labels (which would directly connect to the rest of the design, not through the block's boundary ports) are not supported.
- Components mapping down to parameterized library blocks (like resistors and capacitors) must be defined with a value.
 See the [reference section](#reference) for details on formatting.

## HDL Stub
While the schematic defines the implementation, an HDL Block wrapper class is still required to interoperate with the rest of the system.
Start by **creating a empty `KiCadSchematicBlock` Block class:**

```diff
+ class Hx711(KiCadSchematicBlock):
+   def __init__(self) -> None:
+     super().__init__()
+     # block boundary (ports, parameters) definition here
+ 
+   def contents(self) -> None:
+     super().contents()
+     # block implementation (subblocks, internal connections, footprint) here
```

> `KiCadSchematicBlock` is a `Block` that is defined by a KiCad schematic.

Then, **define the ports in `__init__(...)`**, which must have the same name as the hierarchical labels:

```diff
  class Hx711(KiCadSchematicBlock):
    def __init__(self) -> None:
      super().__init__()
+ 
+     self.pwr = self.Port(VoltageSink.empty(), [Power])
+     self.gnd = self.Port(Ground.empty(), [Common])
+ 
+     self.dout = self.Port(DigitalSource.empty())
+     self.sck = self.Port(DigitalSink.empty())
+ 
+     self.ep = self.Port(Passive.empty())
+     self.en = self.Port(Passive.empty())
+     self.sp = self.Port(Passive.empty())
+     self.sn = self.Port(Passive.empty())

    def contents(self) -> None:
      super().contents()
      # block implementation (subblocks, internal connections, footprint) here
```

> Like the top-level board, the contents of a Block can be defined in `def contents(...)`.
> However, interfaces (like boundary ports and constructor parameters) must be defined in `def __init__(...)`.

> In the HDL model, ports must have a type.
> `Ground`, `VoltageSink`, `DigitalSource`, and `DigitalSink` are typed ports that have electronics modeling (e.g. voltage limits for `VoltageSink` and IO thresholds for `DigitalSink`).
> `Passive` represents a port with no electronics modeling and can be connected to any other `Passive` port.
> Unlike schematic ERC, `Passive` cannot be directly connected to a typed port and requires an adaptor (described later).
> 
> As these are intermediate ports (they connect to internal ports, here in the schematic), they must be `.empty()` to not define parameters like voltage limits which will be inferred from internal connections.

Then, **import the schematic**:

```diff
  class Hx711(KiCadSchematicBlock):
    def __init__(self) -> None:
      super().__init__()
      ...

    def contents(self) -> None:
      super().contents()
+ 
+     self.import_kicad("path/to/your/hx711.sch", auto_adapt=True)
```

> Many of the symbols in KiCad map to library Blocks with ports that are Passive-typed.
> The `auto_adapt` argument in `import_kicad` automatically adds adapters from Passive to (for example) VoltageSink and DigitalSource at these interfaces.
> These automatically-generated adapters produce ideal ports (for example, a VoltageSink with infinite voltage limits) and are great to get a quick-and-dirty schematic out fast, but do not enable the electronics model to check for correctness.

> `KiCadSchematicBlock` provides a `file_path` method which allows paths to be specified relative to the Python file.
> This takes a variable number of arguments, each as a path component under the Python file's folder.
>
> In the core libraries and examples, we typically put imported schematics in the `resources` folder and name the schematic consistently with the class, which is then imported as:
> ```python
> self.file_path("resources", f"{self.__class__.__name__}.kicad_sch")
> ```

Finally, while the capacitors and resistor parameters can be parsed by value, the transistor is more complex and must be instantiated separately in the HDL.
**Instantiate a BJT in contents(...), making sure the name matches with the schematic refdes so the importer recognizes both as the same component.**
**Make sure the schematic symbol has no value.**

```diff
  class Hx711(KiCadSchematicBlock):
    def __init__(self) -> None:
      super().__init__()
      ...

    def contents(self) -> None:
      super().contents()
  
+     self.Q1 = self.Block(Bjt.Npn((0, 5)*Volt, 0*Amp(tol=0)))
      self.import_kicad("path/to/your/hx711.sch", auto_adapt=True)
```

> Overall, there are four ways to define a component in this schematic import process:
> 1. **Value parsing** (like with resistors and capacitors), where the importer has an associated library Block for that particular symbol: the particular library Block is created and parses the value string to determine parameters.
>    Typically, these are Passive-typed.
> 2. **HDL instantiation** (like with the BJT), where the symbol has neither footprint or value, but a Block whose name matches the symbol refdes and with a defined symbol to port mapping: the existing Block is connected as described in the schematic.
> 3. **Inline HDL** (not shown, but could be done with the BJT), where a Block's value contains HDL code prefixed with a `#`, and the resulting Block defines a symbol to port mapping.
>    For the BJT, instead of instantiating the Block in `contents(...)`, you could instead have set the value in the schematic to `#Bjt.Npn((0, 5)*Volt, 0*Amp(tol=0))`.
>    - Multi-line values are supported using the `Value2`, `Value3`, ... fields.
> 4. **Blackboxing** (like with the HX711 chip), where the symbol has a footprint defined: a Block is created with all Passive ports.
>
> See the [reference section](#reference) below for KiCad symbols for value parsing, HDL instantiation, or inline HDL.  

## Top-Level Board
With a fully defined library Block, you can now **add it to your board:**

```diff
  class BlinkyExample(SimpleBoardTop):
    def contents(self) -> None:
      super().contents()
      ...

      with self.implicit_connect(
              ImplicitConnect(self.reg.pwr_out, [Power]),
              ImplicitConnect(self.reg.gnd, [Common]),
      ) as imp:
        self.mcu = imp.Block(IoController())

        ...

+       self.conn = self.Block(PassiveConnector(4))
+       self.sense = imp.Block(Hx711())
+       self.connect(self.mcu.gpio.request('hx711_dout'), self.sense.dout)
+       self.connect(self.mcu.gpio.request('hx711_sck'), self.sense.sck)
+       self.connect(self.conn.pins.request('1'), self.sense.ep)
+       self.connect(self.conn.pins.request('2'), self.sense.en)
+       self.connect(self.conn.pins.request('3'), self.sense.sp)
+       self.connect(self.conn.pins.request('4'), self.sense.sn)
```

> The new Block should also show up in the library browser and can be added with graphical actions in the IDE.
> A recompile may be needed for the library browser to index the new Block.

## Additional Modeling

While a schematic-defined Block allows subcircuit definition quickly and easily, we didn't model the device's electrical characteristics like pin voltage limitations, and as a result the automated checks would not be able to help here.
However, instead of using `auto_adapt`, we can instead define `conversions` on a symbol pin or boundary port basis.
**Add these conversions:**
```diff
  class Hx711(KiCadSchematicBlock):
    def __init__(self) -> None:
      super().__init__()
      ...

    def contents(self) -> None:
      super().contents()
  
      self.Q1 = self.Block(Bjt.Npn((0, 5)*Volt, 0*Amp(tol=0)))
-     self.import_kicad("path/to/your/hx711.sch", auto_adapt=True)
+     self.import_kicad("path/to/your/hx711.sch",
+                       conversions={
+                         'pwr': VoltageSink(
+                           voltage_limits=(2.6, 5.5)*Volt,
+                           current_draw=(0.3 + 0.2, 1400 + 100)*uAmp),
+                         'gnd': Ground(),
+                         'dout': DigitalSource.from_supply(self.gnd, self.pwr),
+                         'sck': DigitalSink.from_supply(self.gnd, self.pwr),
+                       })
```

> `conversions` allows a port model to be specified on either a symbol pin or boundary port, and is defined as a dict from the pin name to the port model.
> If specified on a symbol pin, the adapter is inserted inline at the symbol pin; and if specified on a boundary port, the adapter is inserted before the boundary port, with the symbol pins internally connected as Passive.
> 
> Port models can be fully or partially specified.
> For example, the `pwr` VoltageSink is fully specified with both `voltage_limits` and `current_draw`, while the `sck` DigitalSink is only partially specified and missing its digital input thresholds which are not defined in the datasheet.
> By convention, unspecified fields default to ideal models: for example, a missing `voltage_limits` would mean infinite voltage tolerance.
> 
> `conversions` can be used in conjunction with `auto_adapt`, with `conversions` taking priority:
> ```python
> self.import_kicad("path/to/your/hx711.sch", conversions={...}, auto_adapt=True)
> ```

## References

See the [library construction reference](reference_library.md) for a list of KiCad symbols.

## Defining Library Parts
Continue to [the next part of the tutorial](getting_started_library.md) on defining a library Block in pure HDL.

### Additional Resources
If you want to see some more complex examples of schematic-defined Blocks, check out:
- The FET power gate [schematic](examples/resources/FetPowerGate.kicad_sch) and [FetPowerGate stub class](examples/test_multimeter.py), a power button that turns on a FET which can then be latched on by a microcontroller.
- The priority power OR [schematic](electronics_lib/resources/PriorityPowerOr.kicad_sch) and [PriorityPowerOr stub class](electronics_lib/PowerConditioning.py), a diode-FET circuit that merges two voltage sources with priority.
- The source measure unit analog chain [schematic](examples/resources/SourceMeasureControl.kicad_sch) and [SourceMeasureControl stub class](examples/test_usb_source_measure.py), a higher-level schematic that makes use of the opamp building blocks.
- The differential amplifier [schematic](electronics_abstract_parts/resources/DifferentialAmplifier.kicad_sch) and [DifferentialAmplifier stub class](electronics_abstract_parts/OpampCircuits.py), a standard opamp circuit that mixes schematic definition for the connectivity and generator code to compute resistor values.

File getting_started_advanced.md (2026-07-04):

# Getting Started Tutorial: Advanced Library Construction
_In this section, we will build a re-usable n-LED array Block, going through the advanced constructs of generators and port arrays._

> The IDE does not support graphical operations for programmatic circuit construction.
> However, you can continue to use the IDE for visualization.

## The Naive (but Broken) Approach

The HDL provides the ElementDict construct for giving unique names to a dynamically-sized array of blocks.
An array of LEDs looks like: 
```python
self.led = ElementDict[IndicatorLed]()
for i in range(4):
  self.led[i] = self.Block(IndicatorLed())
  ...
```

You might be tempted to drop the above into a Block and pipe the `int` through as a constructor argument:
```python
# DON'T DO THIS - THIS WON'T WORK
class LedArray(Block):
  def __init__(self, count: int) -> None:
    super().__init__()

    self.led = ElementDict[IndicatorLed]()
    for i in range(count):
      self.led[i] = self.Block(IndicatorLed())
      ...
```

However, there's a few problems with this, which illustrates a few significant ways our HDL model differs from Python:
- When you instantiate a block, for example with `self.Block(LedArray(4))`, it only constructs a block stub.
  As a result, we can't pass parameters into `Blocks` that are concrete values like `int`.
  - This structure allows the compiler to resolve the dataflow and fill out the details when the parameter values are ready, instead of forcing the user to take into account dataflow when ordering their code.
    For example, the `IndicatorLed` generated resistor depends on its input voltage, which depends on the voltage on its signal pin, which isn't available until it's connected.
- All IOs must be static, since classes define a single template block.
  So we can't create different numbers of top-level IOs based on a parameter value.

But, we have ways of achieving the same goals even within the above structure.

## Interface
_In this section, we'll define the block's interface using advanced constructs for library writers._
_This will hopefully also illuminate how some of the existing block generators work under the hood._

**Start by creating an empty block, as done previously:**
```python
class LedArray(Block):
  def __init__(self) -> None:
    super().__init__()
```

### Parameters
First, we'll need to define the block such that it can take a parameter.
This is actually only slight twist on the naive approach:  
```python
class LedArray(Block):
  def __init__(self, count: IntLike) -> None:
    super().__init__()
```

Instead of the constructor argument being a Python type that defines a value like `int`, we use an expression-type.
This defines the type of the parameter being passed but not the value.

> The expression type is a way to refer to the parameter but without giving it a concrete value.
> This is needed since the value is resolved in the compiler and therefore not available in the HDL to the constructor.
> 
> Note that the type is not `IntExpr`, but `IntLike`, which also includes `int`.
> This allows calling the constructor with an `int` value directly, if we just have a static parameterization.

### Port Arrays - Definition
Next, because we will have _n_ LEDs, we will need _n_ IO pins.
While we can't define a separate top-level IO for each LED, we can define a port array IO that is dynamically sized:  
```python
class LedArray(Block):
  @init_in_parent
  def __init__(self, count: IntLike) -> None:
    super().__init__()
    self.ios = self.Port(Vector(DigitalSink.empty()), [Input])
    self.gnd = self.Port(Ground.empty(), [Common])
```

Port arrays are a container port that contain individual ports internally.
As we saw from Part 1, viewed externally, they have no defined size and ports can be requested from them with optional names.
However, from internally, we will be able to define their size, as well as get the names of incoming connections.

> Port arrays require the port type to be undefined.
> Since we have not defined any ports so far, this is only needed for the type and may not have additional data like parameter values.

## Implementation
_In this section, we'll actually implement the circuit generator._

### Generator
First, we will need a way to get the concrete (`int`) value for the LED count.
Generators are a way to defer the implementation of the block until its parameter values are ready, then get the concrete Python version of that parameter for use in the HDL.
**We'll change the base class in our prior code from `Block` to `GeneratorBlock` which provides this functionality**.
```python
class LedArray(GeneratorBlock):
  @init_in_parent
  def __init__(self, count: IntLike) -> None:
    super().__init__()
    self.ios = self.Port(Vector(DigitalSink.empty()), [Input])
    self.gnd = self.Port(Ground.empty(), [Common])
    self.count = self.ArgParameter(count)
    self.generator_param(self.count)
    
  def generate(self) -> None:
    super().generate()
    ...
```

> While here we use generators as a way to get a concrete value for circuit generation (the LED count), generators can also be used to do calculations beyond the operations available with the parameters.
> For example, while we can add two `IntExpr`s (which produces another `IntExpr`), something more complex like square root is not provided.
> For those cases, use a generator to get the parameter's concrete value, where you have access to the full power of Python.
> 
> Generator parameters must be explicitly defined using `self.generator_param(...)`.
> Within `generate`, you can get the concrete value of a generator parameter using `self.get(...)`.

### Port Arrays - Internal
So far, the port array is still empty, so we must define its elements.
With the count available as an int, we can use the `for` loop structure from before:
```python
class LedArray(GeneratorBlock):
  ...
  def generate(self) -> None:
    super().generate()
    for i in range(self.get(self.count)):
      self.ios.append_elt(DigitalSink.empty())
      ...
```

> Port array's `.append_elt(...)` takes in the same arguments as `self.Port(...)`.
> 
> To mark a port array as explicitly having no elements, use `.defined()`:
> 
> ```python
>   class EmptyArrayBlock(Block):
>     def __init__(self) -> None:
>       super().__init__()
>       self.empty_array = self.Port(Vector(DigitalSink.empty()))
>       self.empty_array.defined()
> ```

### Circuit Generation
Instantiate the LEDs and connect them to the IO pin and ground as needed.
`.append_elt(...)` returns the newly created port within the array, which can be used in `self.connect(...)`.

> <details>
>   <summary>At this point, your HDL might look like...</summary>
>
>   ```python
>   class LedArray(GeneratorBlock):
>     @init_in_parent
>     def __init__(self, count: IntLike) -> None:
>       super().__init__()
>       self.ios = self.Port(Vector(DigitalSink.empty()), [Input])
>       self.gnd = self.Port(Ground.empty(), [Common])
>       self.count = self.ArgParameter(count)
>       self.generator_param(self.count)
>   
>     def generate(self) -> None:
>         super().generate()
>         self.led = ElementDict[IndicatorLed]()
>         for i in range(self.get(self.count)):
>           io = self.ios.append_elt(DigitalSink.empty())
>           self.led[i] = self.Block(IndicatorLed())
>           self.connect(io, self.led[i].signal)
>           self.connect(self.gnd, self.led[i].gnd)
>   ```
> </details>

## Putting it All Together

Replace the `for` loop in your top-level design with the single parameterized `LedArray` instantiation, and connect it to the microcontroller:  
```python
class BlinkyExample(SimpleBoardTop):
  def contents(self) -> None:
    ...
    with self.implicit_connect(
            ...
    ) as imp:
      ...
      self.led = imp.Block(LedArray(4))
      self.connect(self.mcu.gpio.request_vector('led'), self.led.ios)
```

As shown above, port arrays can be directly connected together to make parallel connections, and we can request sub-arrays from a port array.
When connecting port arrays together, exactly one must define the array width, which is automatically propagated to the others in the connection.
As a result, the single LED count parameter also drives the connection width and the pins requested from the microcontroller. 

> There are several ways to connect to arrays from externally:
> - As in the first part of the tutorial, we can request individual sub-ports.
> - As seen here, we can request a sub-array.
> - Or as also seen here, we can connect the array as a whole
> 
> For connections, only the types have to match, so you can (as done above) connect a whole array to a requested sub-array, or connect two whole arrays.
> Just remember that in any array connection, there must be exactly array of defined width, and all other arrays will take their widths from that.
> 
> Exception, if connecting an internally-facing array as a whole: it can only be connected to exactly one other externally-facing array. 

When `request_vector` is used, each element's suggested name is the sub-array's suggested name, an underscore (`_`), then the element index.
This is slightly different than the naming we've used for pin assignment so far, so we will need to update the refinements:

```python
class BlinkyExample(SimpleBoardTop):
  ...
  def refinements(self) -> Refinements:
    return super().refinements() + Refinements(
      ...
      instance_values=[
        (['mcu', 'pin_assigns'], [
          'led_0=26',
          'led_1=27',
          'led_2=28',
          'led_3=29',
        ])
      ])

```

### Additional Resources
Check out these examples of generators:
- [Charlieplexing LED generator](examples/test_ledmatrix.py): a much more advanced version of the LED array that minimizes IO pins to drive LEDs, by allowing one IO pin to drive both a column and row of LEDs.
- [Buck and boost converter generators](electronics_abstract_parts/AbstractPowerConverters.py): the power path generator for these switching DC/DC converters encode well-known design equations using generators.

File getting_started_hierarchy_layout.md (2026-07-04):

# Hierarchical Layout Tutorial

Hierarchical layout tips and tricks, using the macropad circuit from the [introductory tutorial](getting-started.md) as an example.

This assumes familiarity with KiCad PCB layout.
If you're new to KiCad, there are plenty of excellent tutorials online, go through one of those, then come back.

## Requirements

The example uses the Keyswitch Kicad Library, available on the KiCad Plugin and Content Manager.

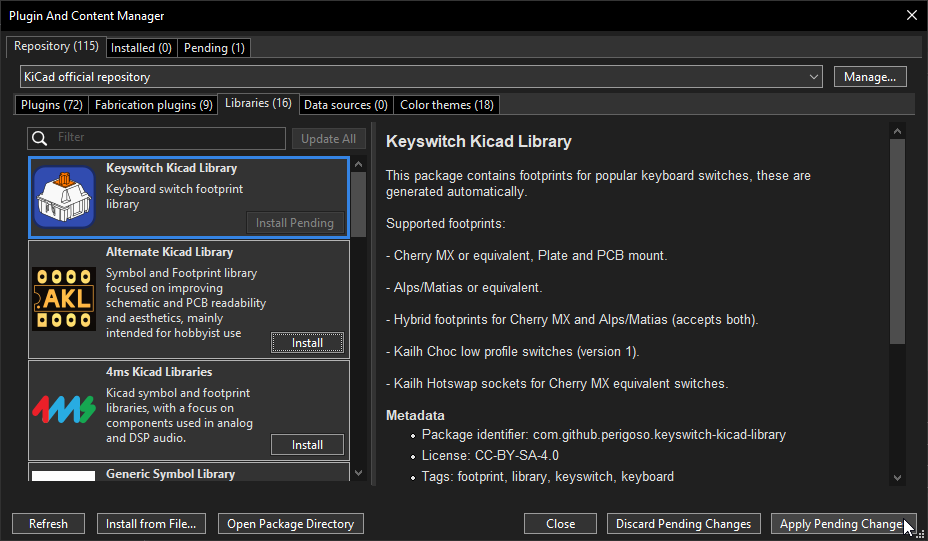
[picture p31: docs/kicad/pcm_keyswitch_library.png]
Keyswitch


For hierarchical loading and replication, you have a few options:

- Use the Sublayout plugin (KiCad 8+), also available on the KiCad Plugin and Content Manager.

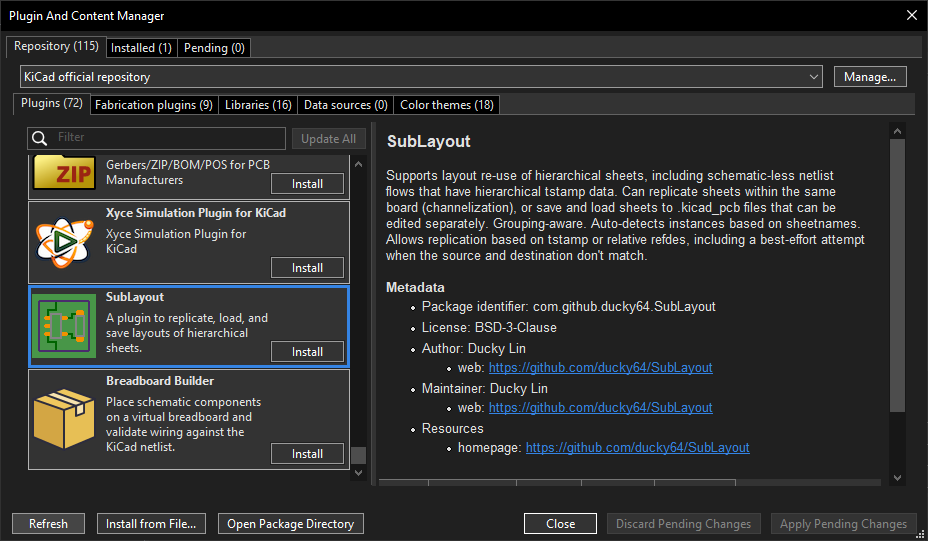
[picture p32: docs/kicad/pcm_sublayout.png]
Sublayout
  
  - This was designed to work with netlist-based flows and automatically detects grouping based on hierarchy data in the netlist.  
  - This works with KiCad 10+, but zones will not be replicated.
- Use KiCad's native design blocks feature (KiCad 10+).
  - This tutorial covers hierarchical replication, but hierarchical loading is not covered.
  - The design blocks flow is heavyweight (requires local library creation) and (at least for netlist driven flows, like this one) requires you to group footprints within a block manually.
- Use KiCad's Multi-Channel and Placement Rule Area feature.
  - This tutorial does not cover this.
  - This seems brittle to other traces overlapping the placement rule area and does not seem grouping-aware. 

> ⚠️ Replicate Layout, Save/Restore Layout, and HierarchicalPCB will **NOT work**. 
> These require and validate against schematic files, which are not generated in this HDL flow.

## Netlist Import

1. Start the PCB Editor (standalone)

   PCB Editor
2. Open Import Netlist from the toolbar: 
   
   
   > If you launched the PCB Editor from a KiCad project, this will not be on the toolbar (you will have "Update PCB from Schematic" instead).
   > You can still access it from the menu: File > Import > Netlist...
3. Select the generated netlist file, likely `BlinkyExample/BlinkyExample.net` in wherever you ran your HDL script, then click Load and Test Netlist.
   It should load with no errors, but there may be some warnings about missing pins.

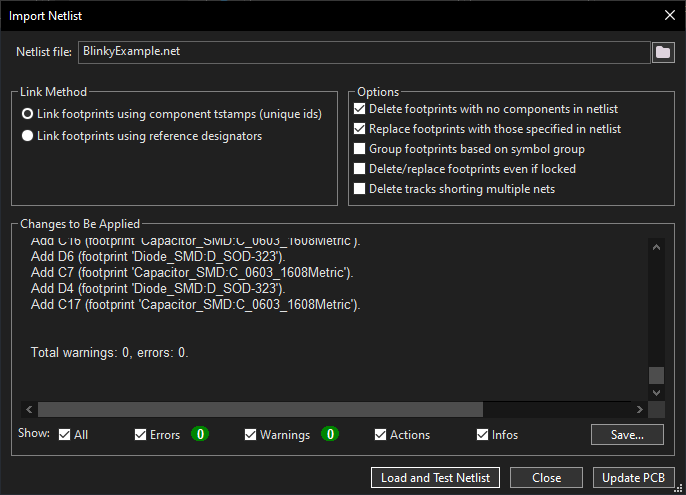
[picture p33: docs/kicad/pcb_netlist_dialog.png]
   

   > In KiCad 10, uncheck "Group footprints based on symbol group".
   > This ignores hierarchical data in the netlist and removes footprint grouping.

4. Click "Update PCB" to place the components on the board.
   Drop them anywhere for now.

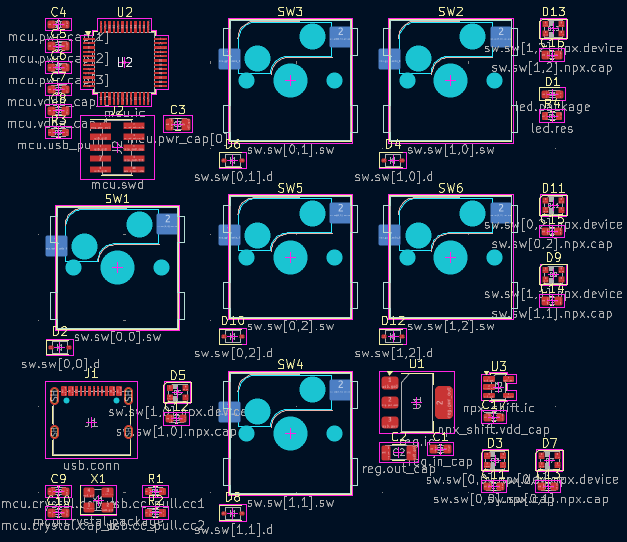
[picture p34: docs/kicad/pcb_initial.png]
   
   - This may give you error(s) about missing pins, which you can ignore.

## Switch Matrix Placement and Replication

The switch, diode, LED, and LED capacitor are all part of a SwitchCell hierarchical sheet in the netlist, which allows the layout to be replicated for each switch.

Start by arranging all the switch footprints in a grid.
This can be done by selecting all the switch footprints, then right-clicking and selecting Create from Selection > Create Array...
Set the grid array size (here, 2x3 as consistent with the HDL parameters) and spacing (19.05mm typical for mechanical keyboard switch spacing).
Set Item Source to Arrange selection (move the footprints, instead of creating new ones), and the Grid Position to Source items remain in place.

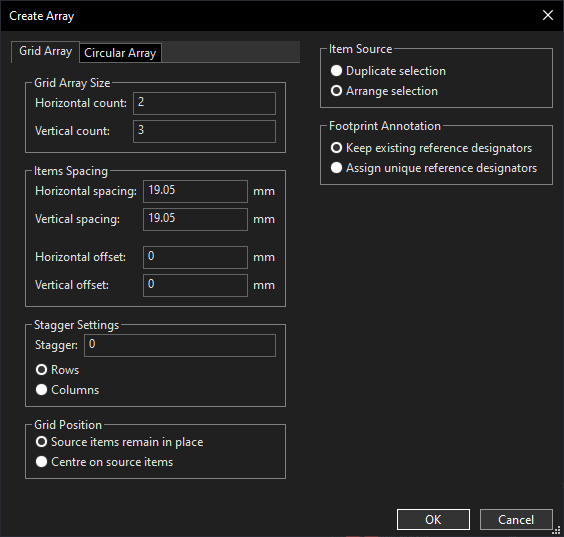
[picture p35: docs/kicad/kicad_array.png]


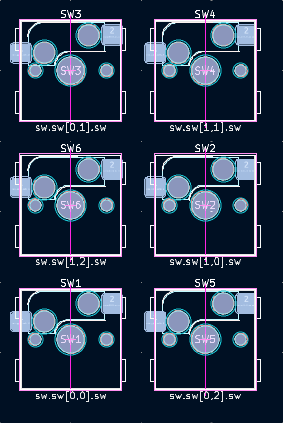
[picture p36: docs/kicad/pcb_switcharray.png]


You may need to swap components to get the right ordering.

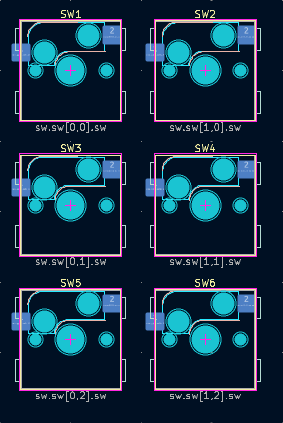
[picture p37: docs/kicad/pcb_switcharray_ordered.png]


> You may also use external plugins to arrange the footprints.

Then, lay out a single switch cell, including the switch, diode, LED, LED capacitor, and traces.
Here is an example layout:

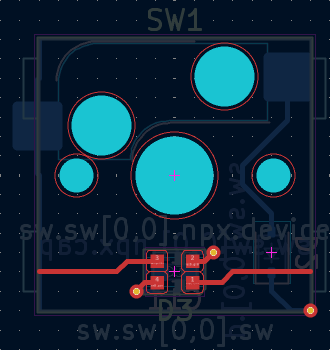
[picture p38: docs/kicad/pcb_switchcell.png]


In this layout, I've allocated the top layer to run horizontal traces (rows and LEDs) and the bottom layer to run vertical traces (columns).

> Tip: use the footprint pathname on the F.Fab layer to find the footprints that are part of the same block.
> For example, find all the footprints starting with `sw.sw[0,0]`.

> Right-click > Select > Items in Same Hierarchical Sheet only selects items _strictly_ in the same sheet, not recursively.
> For example, selecting the hierarchical sheet for the switch includes the diode, but not the LED or LED capacitor, which are in a sub-sheet.

Group the switch cell footprints: select them, right click, Grouping > Group Items.

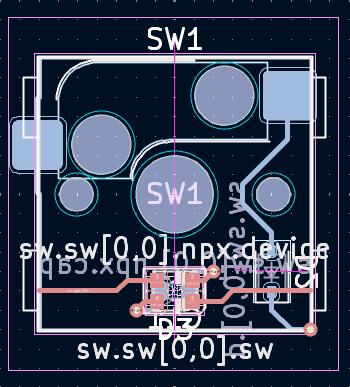
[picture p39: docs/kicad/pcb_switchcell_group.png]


### Option 1: Sublayout Plugin

1. Enter into the switch cell footprint group you just created and select the switch.

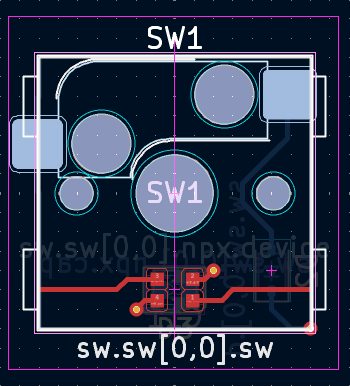
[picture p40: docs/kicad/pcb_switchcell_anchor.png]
   

   The group defines the objects to replicate, while the selected footprint defines the _anchor footprint_, the matching component in the other sheets that other footprints are placed around.

2. Run the Sublayout plugin and select all the instances (bottom list box).

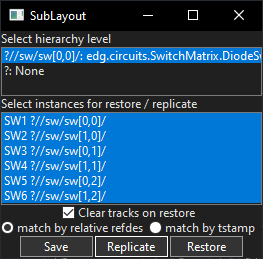
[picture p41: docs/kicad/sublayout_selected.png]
   

   The Sublayout plugin automatically detects all instances of the same hierarchical sheet (HDL block, by name) and lists them.

3. Press Replicate, and the plugin will replicate the layout, including footprint positions, traces, and groupings.

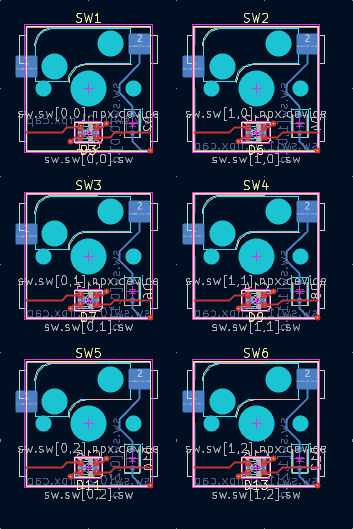
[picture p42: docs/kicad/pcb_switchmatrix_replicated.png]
   

4. You can re-replicate if you change the switch cell layout, it will update the other instances including clearing out the previous traces.

### Option 2: KiCad Design Blocks

_KiCad 10+ required._

1. Open the Design Blocks panel: main menu > View > Panels > Design Blocks.

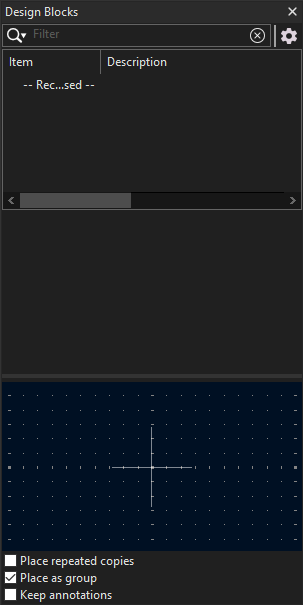
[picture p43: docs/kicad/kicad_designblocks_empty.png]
   
2. If you don't already have a testing library: create a new library.
   Right click > New Library, and select a location for it.

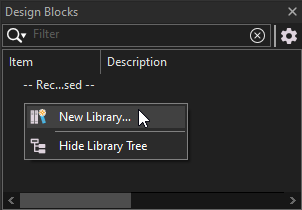
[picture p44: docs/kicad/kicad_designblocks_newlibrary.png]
   
3. Select the switch cell footprint group, and save it.
   Right click on the design blocks library, > Save Selection as Design Block...

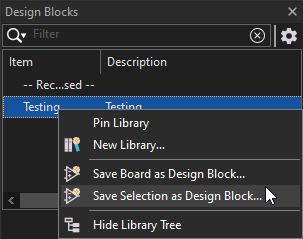
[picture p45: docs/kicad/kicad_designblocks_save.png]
   

   It should show up as a new entry in the library:

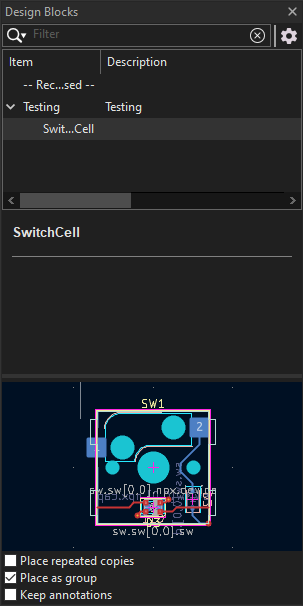
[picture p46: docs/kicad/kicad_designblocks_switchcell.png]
   
4. If you inspect the group properties of the reference layout (select group, `E` hotkey), you'll see the Library link.
   This links the group to the design block.

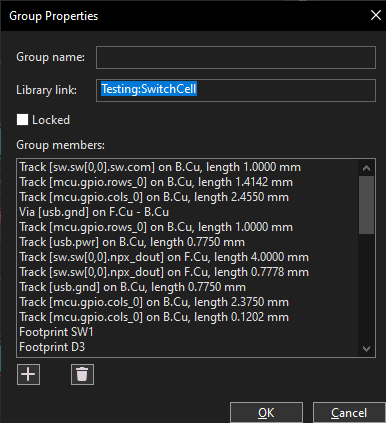
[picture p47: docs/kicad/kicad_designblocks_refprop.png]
   
5. Group the other switch cells footprints (switches, diodes, LEDs, capacitors), one group per switch cell instance.
   For each group, set the library link to the same as the reference group.

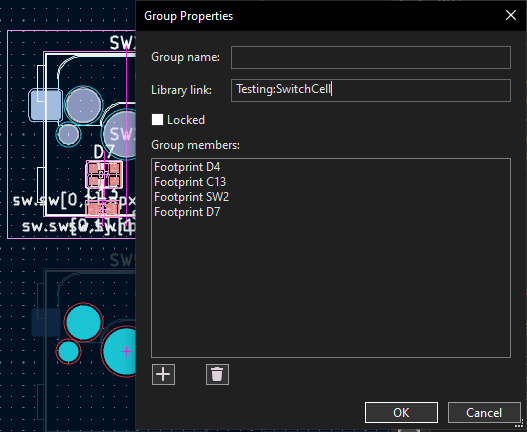
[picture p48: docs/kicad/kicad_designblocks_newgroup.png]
   
6. To replicate: right-click the group and select Apply Design Block Layout.

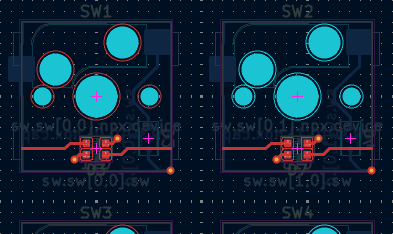
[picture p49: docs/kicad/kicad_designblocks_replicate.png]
   

   > This may shift the position of footprints and you may need to reposition the group.

### Snaking

The LEDs are connected in a snaking pattern, which means every other row reverses the LED connection order.
You may want to have a different switch cell for the odd rows, which flips the LED rotation so data flows from right-to-left.

## Loading a Stock Microcontroller Layout

_The tutorial only covers using the Sublayout plugin._
_Some pre-routed blocks are provided in [examples/prerouted_blocks](examples/prerouted_blocks) which are Sublayout-compatible .kicad_pcb files._
_You can open those files as boards to inspect the layout snippet._

1. Select the STM32F103 footprint and run the Sublayout plugin.
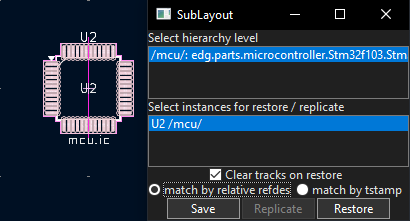
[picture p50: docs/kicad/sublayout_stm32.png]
   

2. Press Restore and select the pre-routed block, here [examples/prerouted_blocks/Stm32f103.kicad_pcb](examples/prerouted_blocks/Stm32f103.kicad_pcb).
   It will complete with warnings about missing footprints (R3, the USB pullup resistor, and J2, the programming header) which are not included in the prerouted block. 
   However, it will place the rest of your components including the crystal oscillator.

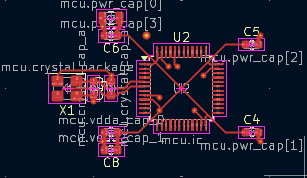
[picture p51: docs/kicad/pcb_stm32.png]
   

> Footprints are positioned exactly as they appear in the prerouted block, even if they are different footprints (e.g., using 1206 instead of 0603, or choosing a different crystal package).
> The Sublayout plugin allows restoring a prerouted block with different footprints, but you will probably need to do some fix-up work.
> In this case, consider it as a first-pass layout.

## Finishing the Board

With the switch matrix and microcontroller done, that's a huge chunk of the work of laying out this board.

You will still need to place and route the USB connector (including the CC pulldown resistors for passive power delivery negotiation), programming header, voltage regulator, and debugging LED.

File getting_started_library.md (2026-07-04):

# Getting Started: Building Library Blocks
_In this section, we build and add a digital magnetic field sensor ([LF21215TMR](https://www.littelfuse.com/~/media/electronics/datasheets/magnetic_sensors_and_reed_switches/littelfuse_tmr_switch_lf21215tmr_datasheet.pdf.pdf)) to our design._
_We do this in two stages, first defining a `FootprintBlock` for the chip itself, then building the wrapper application circuit `Block` around it._

> While `Block`s are arbitrary hierarchy blocks that only have ports, inner blocks, and connections, `FootprintBlock` also allows up to one PCB footprint, and a mapping from the block ports to footprint pins.
> In schematic terms, think of `FootprintBlock` as analogous to a schematic symbol, while `Block` is closer to a hierarchy sheet.

### Dragons be Ahead
Library block definition is a less polished and more complex experience than building boards using existing library blocks.

This tutorial only walks through the basics and constructs.
The next best place is to look through the parts libraries for how these work in practice.

## Creating a part
Block definitions correspond to classes, and a new block can be defined by creating a new class.
**Create the class for `Lf21215tmr_Device`** by inserting: 
```python
class Lf21215tmr_Device(FootprintBlock):
  def __init__(self) -> None:
    super().__init__()
    # block boundary (ports, parameters) definition here 

  def contents(self) -> None:
    super().contents()
    # block implementation (subblocks, internal connections, footprint) here
```

> IDE support for graphical edit actions for library construction is very limited and is not recommended.

> `__init__` is meant to define the interface of a block (all Ports and Parameters), while `contents` is meant to define the contents of a block (largely Blocks, connections, and constraints).
> This split is not enforced (and there are cases where it is desirable to mix them into just `__init__`), but the main benefits of this are performance (avoid building the full design tree unnecessarily) and separation for readability.

### Creating Ports
The chip itself has three pins:
- Vcc: voltage input, type **VoltageSink**
- GND: voltage input, type **VoltageSink**
- Vout: digital output, type **DigitalSource**

Let's start by **creating a port for each** in `__init__`:
```python
class Lf21215tmr_Device(FootprintBlock):
  def __init__(self) -> None:
    super().__init__()
    self.vcc = self.Port(VoltageSink())
    self.gnd = self.Port(VoltageSink())
    self.vout = self.Port(DigitalSource())
  ...
```

Similar to the buck converter blocks, these ports are also parameterized.
We will need to modify these with values from the datasheet:
- operating supply voltage of 1.8-5.5v
- supply current of 0.5-2.0uA
- output thresholds of 0.2v (low) and (Vcc-0.3) (high)

> Limits are typically modeled with recommended operating conditions (as opposed to absolute maximum ratings) where available - for example, the 1.8 - 5.5v Vcc input limit.
> Other parameters are modeled for worst case / full range - for example, the 0.5 - 2.0uA typical current draw and the 9 mA (assumed symmetric) output current capability.
>
> Currently, we only model electrical characteristics - so while data like temperature range and accuracy would be useful, those are not currently modeled.

For Vcc, **set the `voltage_limits` and `current_draw`**:
```python
self.vcc = self.Port(
  VoltageSink(voltage_limits=(1.8, 5.5)*Volt, current_draw=(0.5, 2.0)*uAmp))
```

For `gnd`, we have a special `Ground()` convenience constructor for voltage inputs used as ground:
```python
self.gnd = self.Port(Ground())
```

For `DigitalSource`, while we could write the parameters explicitly:
```python
# DON'T DO THIS - BETTER STYLE BELOW
self.vout = self.Port(DigitalSource(
  voltage=(self.gnd.link().voltage.lower(),
           self.vcc.link().voltage.upper()),
  current_limits=(-9, 9)*mAmp,
  output_thresholds=(self.gnd.link().voltage.upper() + 0.2 * Volt,
                     self.vcc.link().voltage.lower() - 0.3 * Volt)
))
```

there's also a wrapper `DigitalSource.from_supply` that wraps the common way of specifying a digital output as offsets from voltage rails:
```python
self.vout = self.Port(DigitalSource.from_supply(
  self.gnd, self.vcc,
  current_limits=(-9, 9)*mAmp,
  output_threshold_offset=(0.2, -0.3)
))
```

> With a relatively simple example like this, you may be wondering why this needs an HDL instead of a diagram with property sheet interface that supports mathematical expressions.
> That interface would have a few shortcomings:
> - First, it would be less straightforward to support wrappers like `DigitalSource.from_supply`.
>   While possible, these wrappers may need to be baked into the tool (and limited to what the tool designers support), instead of being user-defineable.
> - Second, interfaces that don't allow multi-line code (think spreadsheets) generally have issues with duplication for re-use.
>   While this example only had one port, consider if we had several outputs with the same electrical characteristics.
>   In code, we could define one port model and instantiate it multiple times, while the GUI may require repeating the definition several times.

> <details>
>   <summary>At this point, your HDL might look like...</summary>
>
>   ```python
>   class Lf21215tmr_Device(FootprintBlock):
>     def __init__(self) -> None:
>       super().__init__()
>       self.vcc = self.Port(
>         VoltageSink(voltage_limits=(1.8, 5.5)*Volt, current_draw=(0.5, 2.0)*uAmp))
>       self.gnd = self.Port(Ground())
>   
>       self.vout = self.Port(DigitalSource.from_supply(
>         self.gnd, self.vcc,
>         current_limits=(-9, 9)*mAmp,
>         output_threshold_offset=(0.2, -0.3)
>       ))
> 
>     def contents(self) -> None:
>       super().contents()
>   ```
> </details>

### Defining the footprint
`FootprintBlock` defines its footprint and pin mapping (from port to footprint pin) via a `self.footprint(...)` call.
**Add into `def contents()`**:
```python
class Lf21215tmr_Device(FootprintBlock):
  ...
  def contents(self) -> None:
    super().contents()
    self.footprint(
      'U', 'Package_TO_SOT_SMD:SOT-23',
      {
        '1': self.vcc,
        '2': self.vout,
        '3': self.gnd,
      },
      mfr='Littelfuse', part='LF21215TMR',
      datasheet='https://www.littelfuse.com/~/media/electronics/datasheets/magnetic_sensors_and_reed_switches/littelfuse_tmr_switch_lf21215tmr_datasheet.pdf.pdf'
    )
```

> `self.footprint(...)` takes these parameters:
> 1. Refdes prefix: when generating a traditional refdes (like U1 or R3), this is the prefix to use.
> 2. KiCad footprint name: in the same format KiCad uses.
> 3. Pinning: a dict associating a pin number to a port.
> 4. Additional data like `mfr`, `part`, and `datasheet`, which is generated in the netlist and may eventually be used for BoM generation.

> <details>
>   <summary>At this point, your HDL might look like...</summary>
>
>   ```python
>   class Lf21215tmr_Device(FootprintBlock):
>     def __init__(self) -> None:
>       super().__init__()
>       self.vcc = self.Port(
>         VoltageSink(voltage_limits=(1.8, 5.5)*Volt, current_draw=(0.5, 2.0)*uAmp))
>       self.gnd = self.Port(Ground())
>   
>       self.vout = self.Port(DigitalSource.from_supply(
>         self.gnd, self.vcc,
>         current_limits=(-9, 9)*mAmp,
>         output_threshold_offset=(0.2, -0.3)
>       ))
> 
>     def contents(self) -> None:
>       super().contents()
>       self.footprint(
>         'U', 'Package_TO_SOT_SMD:SOT-23',
>         {
>           '1': self.vcc,
>           '2': self.vout,
>           '3': self.gnd,
>         },
>         mfr='Littelfuse', part='LF21215TMR',
>         datasheet='https://www.littelfuse.com/~/media/electronics/datasheets/magnetic_sensors_and_reed_switches/littelfuse_tmr_switch_lf21215tmr_datasheet.pdf.pdf'
>       )
>   ```
> </details>

## Creating the application circuit
_In most cases, individual components are not used alone and  often require supporting components._ 
_Here, we will define the application circuit for the LF21215TMR, which then can be instantiated in the top-level design._

As described in the typical application circuit of the LF21215TMR datasheet, it requires a 0.1uF decoupling capacitor.
We will build the application circuit as a block around the device defined above, then use this in the top-level design.

**Start by creating a new block, `Lf21215tmr`**.
Since this won't be a footprint, it should extend `Block` directly, and you can insert such code by right clicking on All Blocks in the library browser.

> In contrast to definition we just wrote, this drops the `_Device` postfix we used to indicate a footprint block.

As indicated by the application circuit, this block would have the same ports as the device (two **VoltageSink** and one **DigitalSource**). It would have two parts, the `Lf21215tmr_Device` we just defined, and a `DecouplingCapacitor`.
**Instantiate them both, then connect them together**.
```python
class Lf21215tmr(Block):
  def __init__(self) -> None:
    super().__init__()
    self.ic = self.Block(Lf21215tmr_Device())
    self.cap = self.Block(DecouplingCapacitor(capacitance=0.1*uFarad(tol=0.2)))
```

> The design model requires a tolerance for all parts.
> We've chosen a default loose 20% tolerance for decoupling capacitors. 

For the ports, because these are intermediate ports, they must not have parameters (be `empty()`).
You can also add the implicit tags `Power` and `Common` and make the connections:
```python
class Lf21215tmr(Block):
  def __init__(self) -> None:
    ...
    self.pwr = self.Port(VoltageSink.empty(), [Power])
    self.gnd = self.Port(Ground.empty(), [Common])
    self.out = self.Port(DigitalSource.empty())

    self.connect(self.ic.vcc, self.cap.pwr, self.pwr)
    self.connect(self.ic.gnd, self.cap.gnd, self.gnd)
    self.connect(self.ic.vout, self.out)
```

> By default, instantiating a port without parameters defaults it to ideal parameters - for example, infinite voltage tolerance and zero current draw.
> This is different than empty parameters.
> 
> Having parameters in intermediate ports will cause an over-assignment error, as those parameters are simultaneously assigned from the port definition and the interior port.
> To avoid that, we explicitly use `.empty()`.

> <details>
>   <summary>At this point, your HDL might look like...</summary>
>
>   ```python
>   class Lf21215tmr(Block):
>     def __init__(self) -> None:
>       super().__init__()
>       self.ic = self.Block(Lf21215tmr_Device())
>       
>       self.pwr = self.Port(VoltageSink.empty(), [Power])
>       self.gnd = self.Port(VoltageSink.empty(), [Common])
>       self.out = self.Port(DigitalSource.empty())
> 
>       self.cap = self.Block(DecouplingCapacitor(capacitance=0.1*uFarad(tol=0.2)))
> 
>       self.connect(self.ic.vcc, self.cap.pwr, self.pwr)
>       self.connect(self.ic.gnd, self.cap.gnd, self.gnd)
>       self.connect(self.ic.vout, self.out)
>   
>     def contents(self) -> None:
>       super().contents()
>   ```
> </details>

### Export
Instead of creating ports, we can also use the `self.Export(...)` function to export an inner port directly.
This effectively combines the `self.Port` for creating the port and the `self.connect` from that new port to the inner port.
An additional benefit is that the port type is inferred from the inner port, so you don't need to repeat the specification.

With this style, the ports can be rewritten as follows (and remember to fix the capacitor connections):
```python
class Lf21215tmr(Block):
  def __init__(self) -> None:
    super().__init__()
    self.ic = self.Block(Lf21215tmr_Device())
    self.pwr = self.Export(self.ic.vcc, [Power])
    self.gnd = self.Export(self.ic.gnd, [Common])
    self.out = self.Export(self.ic.vout)
    ...
```

> <details>
>   <summary>At this point, your HDL might look like...</summary>
>
>   ```python
>   class Lf21215tmr(Block):
>     def __init__(self) -> None:
>       super().__init__()
>       self.ic = self.Block(Lf21215tmr_Device())
>       self.pwr = self.Export(self.ic.vcc, [Power])
>       self.gnd = self.Export(self.ic.gnd, [Common])
>       self.out = self.Export(self.ic.vout)
>   
>       self.cap = self.Block(DecouplingCapacitor(capacitance=0.1*uFarad(tol=0.2)))
>       self.connect(self.cap.pwr, self.pwr)
>       self.connect(self.cap.gnd, self.gnd)
>   
>     def contents(self) -> None:
>       super().contents()
>   ```
> </details>

## Finishing Touches
Instantiate and connect the magnetic sensor at the top level (if you haven't done so already).
You can put it in the implicit block to avoid the explicit power and ground `connect` statements.
The sensor output can be connected to the microcontroller's GPIO.

```python
class BlinkyExample(SimpleBoardTop):
  def contents(self) -> None:
    super().contents()
    ...
    with self.implicit_connect(
        ...
    ) as imp:
      ...
      self.mag = imp.Block(Lf21215tmr())
      self.connect(self.mcu.gpio.request('mag'), self.mag.out)
```

## Advanced Library Construction

Continue to [the next part of the tutorial](getting_started_advanced.md) on using generators and port arrays to refactor the LED array as a parameterized block.

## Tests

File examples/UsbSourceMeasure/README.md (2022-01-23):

First unit:
- J1: Molex 217179-0001
- J2: GCT USB4105-GF-A
- High side transistor: ~NPN PHPT60410NYX~, NMOS SIR172ADP-T1-GE3
- Low side transistor: ~PNP PHPT60410PYX (exploded at ~3A)~, PMOS SQJ433EP-T1_GE3

Second unit:
- D1, D2: white LEDs
- U15, U16: CPC1106N
- U20, U14, U18 (HV opamp): MC33171DT
- U4, U6, U8, U10, U12: MCP6001T-I/OT

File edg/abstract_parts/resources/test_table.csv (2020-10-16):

header1 | header2 | header3
1 | foo | 9
2 | bar | 8
3 | ducks | 7

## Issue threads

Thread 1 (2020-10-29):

Ground API refactor

ducky64, 2020-10-29:
All wires should have a ground reference (to another Port, of ground type or voltage-source type).

This issue only cares about the user-facing HDL / API, it does not include any analyses enabled by this API modification, or IR changes to propagate this.

Mechanism would be for all electrical model Ports to have an optional kwarg `ref_wire` that defaults to an object indicating a tag reference - keeping the current implicit ground model, but adding optional overrides. The ground port would be tagged on declaration.

## Explicit ground tagging
```python
self.gnd = self.Port(..., tag=Common, tag_internal=True)
```

Positives: very explicit syntax

Negatives: requires the most boilerplate, especially boilerplate that is needed for every single block, and probably isn't useful for anything else

## self.Ground() construct
```python
self.gnd = self.Ground(...)
```

where `self.Ground(...)` adds the internal-facing tag, in addition to everything `self.Port` is doing. This requires the containing Block to define a `Ground` method, so this would require a circuit-specific `Block` subclass (like `CircuitBlock`) in the hierarchy. Which might be a good thing in the future.

Positives: `Ground` makes sense as a conceptual unit, and `CircuitBlock` could be used for other extensions

Negatives: requires a circuit-specific `Block` type in the hierarchy

**This seems the best balance so far**

## Implicit Ground

`CircuitBlock` of above would also declare a `self.gnd`, available to all subclasses.

Positives: almost all circuit blocks would use this, except for those with isolation (and where there isn't an obvious primary)

Negatives: very magical

ducky64, 2024-07-24:
Obsoleted by #364. Implicit grounds have too many drawbacks.

Closed 2024-07-24.

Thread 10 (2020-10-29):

Hacking in net connections

ducky64, 2020-10-29:
Lack of comprehensive / fully modeled libraries means some tasks are very difficult to complete, so there needs to be some quick and dirty hack to allow pin-to-pin (or net) copper connections, bypassing the type system and block hierarchy (so this can be done at the top level). Goal is to keep centralized design data in the HDL (instead of doing netlist modifications in PCB layout).

Future ideas:
- bidirectional netlist diff, to allow / track changes in PCB layout

Migration ref: 144

ducky64, 2024-07-24:
Probably obsoleted by KiCad schematic import and unmodeled ports

Closed 2024-07-24.

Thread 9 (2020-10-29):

Clean up metadata keys

ducky64, 2020-10-29:
Currently, there are a bunch of strings that define metadata keys, spread out through the frontend codebase. This should get moved over to a typesafe object, or constants in proto.

Currently used core metadata:
- `refinement_original`: indicates the block is refined, value is a serialized proto [?] of the library path of the original base class
- `abstract`: indicates the block is abstract; errors during compilation, value is a dummy string
- `error`: indicates the block has an error, contains a subtree
  - `params`.(path as proto) -> error string
  - `constraints`.(constraint name) -> evaluated value
- `_params_order`, `_ports_order`, `_links_order`, as dict of index to name (since proto maps are unordered)
- `_edgdoc` (currently not fully implemented): contains docstring (for classes) and additional documentation for instantiated ports / etc
- `_sourcelocator`: source locator, as dict of reference to `(source file): (line no)`

Currently used electronics-specific metadata:
- `nets`: contains copper nets for netlisting, currently means all ports are connected by copper
- `pinning`: blocks defines a component for netlisting
  - tied to `footprint_name`, `mfr`, `part`, `value`, `refdes_prefix` parameters in the block
  - contains a dict of pin_name (footprint pin name), pin_path (proto Ref to associated Port)

Migration ref: 143

ducky64, 2023-05-07:
Obsoleted by refactoring that reduces the use of metadata

Closed 2023-05-07.

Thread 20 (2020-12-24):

Block-side Port Arrays

ducky64, 2020-12-24:
Potential implementation
- LinkArray construct, that allows an arbitrary-length parallel array of links. It has ports that remap to the internal links.
  For example, if the internal link is a DigitalLink with `src: DigitalSource` and `sinks: Array[DigitalSink]` ports, the LinkArray would have:
  - superclass `DigitalLink`
  - (once fully elaborated) ports `src: Array[DigitalSource]` and `sinks: Array[Array[DigitalSink]]`
  - (once fully elaborated) constraints to connect `array.src[x] <=> array.links[x].src` and `array.sinks[0][x] <=> array.links[x].sinks[0]`
  - Its length is equal to the length of all of its ports (bidirectional propagation / merged construct). It is ready to elaborate when any port's length is known.
  - **TODO**: how should width inference be handled in the constraint language - or should it be a special construct? Can it work for a fully directioned constraint language - in this case, where are the constraint directions set?
- `LENGTH` ReservedParam, which can be used on a PortArray to get a Int type corresponding to the length.
  - This is the mechanism for width inference. This `LENGTH` parameter can both be a value source (eg, in a generator, get the actual length of the block's ports) and a sink (eg, set the length from a generator)
- `ALLOCATE` ReservedParam, which can be used on a block-side PortArray to get a fresh "slice" of ports of the array. Dynamic length (length propagates to the block), and can be connected to either an element port (single link connect) or array port (link array "parallel" connect). The PortArray's length is the sum of the length of all ALLOCATE operations. Any PortArray can either be connected as a whole, or piecewise with its ALLOCATEd components (but never both - mutually exclusive).
  - The motivating use case is a microcontroller's digital IOs, which might consist of a mix of known-width connects and unknown-width (at compile time, but resolved by parameter propagation width inference in the backend) connects, and to make that representable in the IR.

### Alternatives
- Instead of an PortArray.ALLOCATE operation, perhaps something can be done with a make_array expression, eg `connect(make_array(io0, io1), link.io_array)`. But this doesn't capture the microcontroller digital IOs use case well, and would also collapse the links from multiple connect statements into one mega link-array which could make visualization and debugging less intuitive.
- However, make_array might be a good for for link-side array allocation - instead of connecting block ports to link.ios, all the block-side IOs in the connection can be grouped into one connect statement. Potentially simplifies the Python fake-backend code.
- Even for (single) links with array-typed IOs (eg, DigitalLink's arbitrary-length sinks), it might be worth indexing them with `ALLOCATE` in IR to distinguish an element connect from a vector (parallel) connect.
- Is it worth having a separate `ALLOCATE_ARRAY` for a array-typed slice vs. an element-typed slice?
  - Might need to in the frontend (mypy) type system. Doesn't necessarily need to propagate to IR?

### Mockup example
Motivating example: an abstract analog switch generator, that has n-bit AnalogSink inputs, 1 AnalogSource output, and log(n) (parallel) DigitalSink control bits.

#### System-level
Overview: the AnalogSwitch is connected to n analog sources at the top level (through n independent links), and a parallel log2(n) digital control line from the microcontroller. Width inference goes n analog sources -> AnalogSwitch generator runs -> defines its log2(n)-wide control line -> defines the microcontroller digital IO array length -> microcontroller generator runs

Frontend mockup
```python
self.mcu = self.Block(Microcontroller())
self.analog_switch = self.Block(AnalogSwitch())
self.connect(self.analog_switch.ins.allocate(), self.analog_in0)  # single element link connect
self.connect(self.analog_switch.ins.allocate(), self.analog_in1)  # single element link connect
...
self.connect(self.mcu.digital_ios.allocate(), self.analog_switch.control)  # link-array connect
```

IR mockup
- Blocks
  - analog_switch: AnalogSwitch
  - mcu: Microcontroller
- Links
  - ctl_link: Array[DigitalLink]
- Constraints
  - Export: analog_in0, analog_switch.ins.ALLOCATE
  - Export: analog_in1, analog_switch.ins.ALLOCATE
    - Note: the length of analog_switch.ins is inferred from these two connect statements
  - Connect: analog_switch.ctl, ctl_link.sinks[0]
    - Depending on if (element) link port allocations are done in the frontend
  - Connect: mcu.digital_ios.ALLOCATE, ctl_link.source
    - Note: the length of mcu.digital_ios can be inferred after the length of ctl_link.source is known, which happens after the length of analog_switch.ctl is known, which happens after the analog_switch generator runs
    - Note: mcu.digital_ios.ALLOCATE can be used in other connections, eg blinky LEDs and tactile switches

#### Analog Switch Generator
Overview: the switch generator requires the length of the analog inputs to be known before it can run, and provides the length of the digital control line.

##### Overall Computation Flow Mockup
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

1. The three export connections define all the allocations to analog_switch.in
2. Aggregating them, the port-array is of length 3. Solver knows analog_switch.in.length=3.
3. With the analog_switch.in.length defined, analog_sw is ready to generate. Inside, it also defines analog_switch.ctl.length = log2Ceil(3) = 2 and instantiates those internal connections.
4. With analog_switch.ctl.length defined, the link array is ready to elaborate. All the ports on the link array are constrained to have the same length.
5. Elaboration runs, the effects aren't visible externally (since the length equivalence on all ports is defined in the link array, not a product of elaboration).
6. All allocations to mcu.digital_ios are knows, and the solver knows mcu.digital_ios.length = 2.
7. mcu can elaborate.

##### Syntax Mockup

Frontend skeleton (`__init__`) mockup
```python
self.in = self.Port(Vector(AnalogIn()))
self.out = self.Port(AnalogOut())
self.ctl = self.Port(Vector(DigitalIn()))
self.register_generator(  # mockup API for generators that are dependent on directed constraints (eg, can only run after some parameter is resolved)
    prereqs=self.in.length,
    outputs=self.ctl.length,  # optional?
    self.generate
)
```

Frontend `generate` mockup
```python
length = self.get(self.in.length)
self.ctl.set_length(log2(length))  # instantiates (and allows indexing into) array elements

# and in a concrete implementation, which connects the abstract interface to an internal chip
self.ic = self.Block(SomeAnalogSwitchChip())
self.connect(self.in[0], self.ic.in0)
self.connect(self.in[1], self.ic.in1)
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
rohit507, 2021-11-01:
- What exactly is `ALLOCATE` in the context of the protos?
   - Is it a constraint expression?
   - A reserved/special local-step?

ducky64, 2021-11-01:
`ALLOCATE` is currently a ReservedParam LocalStep. It gets replaced with a named LocalStep during the compilation process. Currently, there aren't array connects, so the constraint is just rewritten, but with this proposed feature array connects will need to compile / lower into multiple single connects.

rohit507, 2021-11-01:
From my end, the key question is: How do I have non-directional semantics for an `ALLOCATE`?

In the local-step case, it would mean making both paths and array-like elements slightly more symbolic. I'd also have to explicitly bound the max size of an array, which is going to be interesting.

Finally, is there any issue with non-contiguous indices on arrays on your end? If I generate a design where an Array has elements at `[0,2,5,7]` will it break anything? Or do they have to be contiguous and minimal `[0,1,2,3]`? The former would make my implementation a bit simpler, and I'll be doing it regardless for an initial pass (since we don't plan to pipe things back from my solver) but it'd be something for me to keep in mind.

ducky64, 2021-11-01:
What do you mean non-directional semantics for `ALLOCATE`?

There shouldn't be any issues with non-contiguous indices, I believe the current compiler is set up to handle arbitrary indices, though generates contiguous and minimal indices when rewriting `ALLOCATE`s.

ducky64, 2022-03-01:
Rough roadmap:
- IR changes
  - Add array_export and connect_export constructs
- Add frontend changes to support these
- Unit test that the proto is expected
  - Test allocate-to-array connect (example use case: micro pin assignment, connecting to dynamically-sized ports eg n-ported analog switch), using existing (individual) connect constructs and individual links.
  - Test array-to-array connect (example use case: m-bit Digital control lines to micro pin IO), using new array-connect constructs and the link-array construct
  - Test individual ports (inner) to array (boundary) exports.
  - Are array-array exports needed? Potentially to support the adapter pattern?
- Write compiler support - expand array connects
- Compiler unit tests for array connect expansion
- Design and build frontend API for arrays on generators
  - How can generators declare which ones are input arrays and which ones are output arrays? Perhaps port-array elements in the generator that map to arrays of names in the generator function?
  - How can generators handle outputs? Perhaps just as collections of leaf-to-array export, minus input arrays?
- Compiler support for arrays on generators
- Refactor microcontroller pin assignment utility
  - Refactor examples to support this new style
- Unit tests for array-to-fixed refinement (eg, N:1 analog switch refined to a 2:1 analog switch - at least if N <= 2)
- Build new array types: N:1 voltage source merges, N:1 analog switches, ...
- Refactor examples to use these
- Opportunistic refactoring

Closed 2022-04-19.

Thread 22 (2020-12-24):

Compiler core rewrite

ducky64, 2020-12-24:
Some of the planned changes are pretty fundamental, in that it's likely the compiler core will need to be completely rewritten anyways. Current plan is to rewrite the core in Scala, which should make the code a bit more cleaner.

Planned changes:
- #20 link arrays
- #13 directed constraints
- Possible directed generators? As an alternative to the current subset tightening model, directed generators would "fire" when its inputs are ready. More thought would need to be put into supporting fixed-point design practices / loops
- Possibly #9, improved metadata fields
- Would need a Scala <-> Python interface to call into Python generators and still allow a Python top-level object

Design for these performance improvements, by having a persistent cache object, ideally one that can be serialized
- #17 cached generators
- #7 cached libraries
- #18 might be obsoleted, though there might be places to eliminate CopyFrom in the frontend (but likely to be less important, since the frontend execution is pretty shallow)

### Compiler structure
For each top-level design, the compiler maintains:
- The design graph, analogous to IR - which may contain unelaborated elements
- A directed graph data structure for parameters, parsed from the directed constraints. In addition to being useful for optimized solving, this could also be used as part of a constraint tracing visualization for debugging
- All solved variables

1. Start with the top-level design graph, which may or may not have been elaborated
2. Iterate, to fixed point (or nothing left to do) - in any order:
   1. Propagate solved values (can be done any time)
      - Refinements / parameter overrides are applied during this phase
      - This can be implemented as a fixed point algorithm (naive simple version - inefficient) or using a directed graph that keeps track of unevaluated directed assignments (edges pointing into (inputs/ RHS) and out of (outputs / LHS) each constraint, with the evaluation attempts triggered by evaluation of RHSs and on instantiation).
      - Multiple assignment would be an error
      - Unassigned parameters would be an error (everything must have a default in the frontend -
      - The two above should effectively detect cyclic dependencies - but a dedicated analysis pass might be useful for debugging and visualization purposes
      - Unreachable parameter names are ignored - but a dedicated check pass might be useful for debugging
      - Existing "==" constraints would be treated as assertions rather than assignments
      - Checks would make sure values are accessible from constraints to prevent non-local effects and enable cache.
   2. Elaborate blocks (can be done any time - including generators, though the generate phase won't run immediately).
      - Refinements are applied during elaboration.
      - Constraints are added to the constraint graph as elaboration happens.
      - TODO: what would be required to instantiate an entire sub-tree from cache (instead of only a single level at a time - which is expected to produce only marginal gains)?
   3. Elaborate links (can be done any time - though link arrays must wait until the length is evaluated - this can use a similar mechanism to directed generators)
   3. Run generators (if inputs are ready / available)
      - If the generator is marked as cache-able, and the generator results based on it specified input parameters are in cache, it is retrieved from cache instead of calling into the generator.
      - Otherwise, pass the input parameters into Python and run the generator to return the elaborated IR
      - Note: the explicit generator argument list also helps bound the amount of data to cache
3. Check assertions, check all parameters have assigned values, check there are no generators that still need to be run, and check no parts are abstract.
   - Errors should be batched (like type checkers) instead of failing first error. Source locators should be reported where possible (eg, failing assertion line, failing block instantiation line). More ambitiously, constraints should indicate the source locator of the error, though this is likely to be difficult to do well because constraints may have many inputs
4. Optionally, structural sanity double-checks (no cyclic dependencies, no multiple assigns - even if these weren't triggered during the actual compilation phase)

Elaboration is done by depth-first traversal, since the innermost component may be the one driving constraints required for the top-level to make progress.

rohit507, 2020-12-28:
> Some of the planned changes are pretty fundamental, in that it's likely the compiler core will need to be completely rewritten anyways. Current plan is to rewrite the core in Scala, which should make the code a bit more cleaner.

Agreed, seems like a generally good plan.

>     * Possible directed generators? As an alternative to the current subset tightening model, directed generators would "fire" when its inputs are ready. More thought would need to be put into supporting fixed-point design practices / loops

So, if we assume that generators will trigger in some total order<sup>[1]</sup> and we don't need to have semantics for generators firing "simultaneously"<sup>[2]</sup>, then we shouldn't have much issue in the short term. The problem is in the longer term we either need to have non-deterministic generators<sup>[3]</sup> (very hard for us, probably requires us to craft a custom (non-E)DSL) or require that generators meet a bunch of totality criteria that makes them much harder for their authors to make.

It might be worth considering if we could do anything with repeated evaluation of a generator. Generators have "types" that determine when we should fire them and are supposed to work for *every* input that's a subset of that type. That should mean we could fire generator `A`, do a bunch of other generation and propagation (that should only refine the input, never make it so the type of the original part doesn't fit the generator), delete all the stuff `A` added, and run `A` again. This should mean that `A` has a chance to generate a better implementation given the new information from the rest of the design, even though that new information was prompted by the first "draft" design that `A` generated.

Not sure if that would work in practice and it assumes that generators are mostly deterministic but it might allow for human usable fixed point-ish semantics that produce better optimized designs.

<sub>**[1]**: I think this is a fine assumption if we're willing to forgo some sort of logical determinism<sup>[4]</sup>, and that we shouldn't really be trying to have that kind of determinism with this version of the system.</sub>

<sub>**[2]**: As opposed to what I assume you're doing when generators `A` and `B` can both fire at the same time. Namely, the compiler would pick one of the generators, say `A`, evaluate it, propagate the updates as needed, and then fire `B`. Doing something like "fire `A`, fire `B`, propagate" would be a better match for the fixed point style of evaluation but would make it harder to write generators that function well and cause more unnecessary refinement failures.</sub>

<sub>**[3]**: In the sense of non-deterministic algorithms in complexity theory. Namely that all possible paths of evaluation occur simultaneously and that the results of all the paths are collected together. Not non-deterministic in the sense that you're sampling from all possible evaluations.</sub>

<sub>**[4]**: By logical determinism, which isn't a real term, I mean that the output of the compiler should be deterministic given only the input design and generators without any hacky tricks to ensure a consistent evaluation order. You could say "Always run the first available generator when sorted by alphabetical order" or something and have determinism, but now that determinism is decoupled from the logical formalism that backs the compilation process (Not that said formalism is well defined right now, but you get the point). This also applies to having a deterministic order for firing propagators instead of propagator firing following a diamond law.</sub>

>     * Would need a Scala <-> Python interface to call into Python generators and still allow a Python top-level object

Between `pickle` and `inspect` this should be possible, no idea how difficult though.

> ### Compiler structure

Mmm.

>     * A directed graph data structure for parameters, parsed from the directed constraints. In addition to being useful for optimized solving, this could also be used as part of a constraint tracing visualization for debugging

Hmm, you're only handling directed constraints in this compiler?

>  [algorithm sketch ...]

Seems broadly good.

>           * This can be implemented as a fixed point algorithm (naive simple version - inefficient) or using a directed graph that keeps track of unevaluated directed assignments (edges pointing into (inputs/ RHS) and out of (outputs / LHS) each constraint, with the evaluation attempts triggered by evaluation of RHSs and on instantiation).
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
ducky64, 2020-12-29:
**Generators and run order**: so combined with that parameters can't be overassigned, when a generator is ready, the inputs should be in their final state, so order shouldn't matter (but practically, if multiple generators were available, the one that runs would be arbitrary; at the end everything should converge to the same result).

I've thought about ideas to handle multiple runs to tighten bounds, but I think I'd like concrete examples to drive that. The idea I'm leaning towards is extending the Range tightening feature we have now to allow that to re-trigger generators, and iterating until a fixed-point solution or some number of iterations. Though, not completely sure how the control and specification of these should be handled.

**Compiler structure**: Yes, only planning to handle directed constraints for propagation. Undirected constraints would be treated as assertions. Also, there shouldn't be any cycles in this model (cycles would be detected and cause an error), in theory this should be a relatively simple DAG traversal? Though I'll take a look at the Rete algorithm

**Unassigned parameters**: Sorry, to clarify a bit: unassigned parameters can happen and will error to signal an under-constrained design. But I expect many parameters will have sensible defaults, eg voltage input ports would have a default voltage limit of (-inf, inf). Future analyses can detect propagation of default values, eg to warn on use.

**== as assertions**: The alternative would be to stylistically match `(var) == (expr)` constraints as directed assignments, but the disadvantages would be that it's not obvious that it's an assignment, and it's not obvious it's directed. I think I'd prefer a obviously different construct, maybe `var.assign(expr)`.

**Cache**: The idea is to cache a generator based on its input values. Some generators are expected to be expensive to run (eg, part table search), so it makes sense to save the result of the first run, and some generators get run a lot even within the same design (eg, 0.1uF capacitors). Generators would be explicitly marked as cache-able.

The other cache item worth thinking about in the future would be to cache entire sub-trees, though mainly for re-compilation speed. For example, if a buck converter is instantiated with the same inputs, in theory we can avoid elaborating the sub-tree from scratch and drop the cached one in. But this is harder than the generator case, where inputs are explicitly marked and hence very bounded. It's also less clear how much time this would save, since I expect library instantiation to be relatively fast,
because the number of parameters are limited (order tens?) and it's in JVM instead of Python.

Closed 2021-04-17.

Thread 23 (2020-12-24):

Abstract microcontroller type

ducky64, 2020-12-24:
One that has a grab-bag of common IO types (digital, SPI, I2C, UART, CAN, USB), using #20.

A future feature would allow the IOs to be of all of the above types, though the design model and implementation for that is unclear. For now, there would be an API similar to the current new_io that returns a io of the appropriate type. Main benefit is that it could allow micros to be more interchangeable with abstract types instead of changing HDL.

Related: #15, which is also relevant to this.

ducky64, 2022-03-13:
Thoughts on architecture of the components involved:

Chip level:
- instantiates the footprint
- ports more or less directly correlate with the footprint, probably configured as a named vector that correlates with the port name
- perhaps also creates peripheral ports (eg, SPI, I2C), but it's unclear how to handle configuration (either pin matrix like LPC1549 or alternative-mapping like STM32) and overlap with GPIO ports (perhaps mutual exclusion functionality? or pin mapping generator?)
  - peripherals at this level more accurately models the chip and its resources
  - this better modeling may also make it easier to generate firmware stubs (in the future), without needing things like graph traversal (but this will need to traverse the graph to get names - perhaps using link name with name inference from allocated port names)
  - otherwise, ports would need to be passively-typed, since analog functionality is often overlapped with digital ports

Application circuit level:
- contains required supporting components, like decoupling capacitors
- exposes the same interface as the chip above, except for anything only connecting to required components
  - requires vector export functionality
- does not contain optional components, like crystals (if there is an internal frequency source - but exposes the port)

Pin mapping level (IO controller wrapper / adapter):
- a very magical block, does a lot of things to present this software-controlled bag-of-IOs abstraction
  - everything else needed to use the microcontroller is automatically generated - for example, crystals (details below) and programming ports
  - parameters and refinements can be used to turn these off and control their implementation
- can contain mixins (#104) to provide the interface to support different functionality, eg frequency tolerance spec to automatically generate a crystal if needed
- contains a very basic pin mapper (greedy assignment - maybe better or configurable in the future), it is expected users will manually specify pin mappings through suggested name on the connected ports and refinements
  - if the chip or application circuit provides peripheral IOs: there are now overlapping responsibilities, in which case this will need to both handle direct port assignment (even bundles like SPI aren't broken up, they are directly forwarded) AND generating refinements to the chip to control its internal assignment
    - architecturally, this will need to understand the chip's peripheral assignment architecture, then serialize that configuration, pass it as a parameter, which the chip will deserialize and handle its internal mapping
  - bitbang case: should bitbang adapters be instantiated here? - probably don't need to worry about it right now

Current state of things:
- chips have passive pins (for the analog/digital reason above) - so the modelling is meh
- application circuit block also handles pin mapping
- the instantiating level must create supporting components like crystals and programming ports - composable but still kinda overhead

Defining a cross-level-of-abstraction pin mapping interface:
- requirement: handle multiple mapping schemes, including pin matrix and fixed peripherals with alternate pins
- requirement: single source of truth: the pin assignment definition should be centralized, and pin assignments (in both the chip and IO controller levels) should draw from this central source of truth
- architecture: TBD

Closed 2022-04-07.

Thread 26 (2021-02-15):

Consider stricter over-assign semantics

ducky64, 2021-02-15:
With the new compiler (refactor in progress), equality propagation when both values are equal is silently discarded. This is needed to support the DC-DC converter case, where the voltage is forward-declared from the feedback resistor, before the generator runs and hooks up the inductor which should define the output voltage.

Potential alternatives:
- Explicit forward-declaration tag / annotation to enable this discarding (and erroring otherwise)
- Allow merging of nets between generator functions (might still require other funkiness in the DC-DC converter code)
- Other DC-DC converter restructuring to avoid this behavior

ducky64, 2022-12-03:
Probably resolved with directed assigns and DC-DC re-structuring.

Closed 2022-12-03.

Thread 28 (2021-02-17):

Unified and coherent separation of specification and selected parameters

ducky64, 2021-02-17:
... and how specification component can be ignored when a subclass is set.

Use case:
- specifications are hack-ignored: Battery subtypes, PPTC fuse subtypes
- things could be cleaner in: all the part-table-based components, particularly resistors / caps / inductors.

ducky64, 2021-12-16:
Additionally: consider if restrictions on parameter flow can make sense (is there some restriction that isn't overly restrictive but can prevent parameter deadlock?).

And refactor all the parts table component to separate specification and solved values - and make sure that all parameter consumers are using the right one (probably the solved value?).

ducky64, 2022-02-11:
For now, and in #92, the convention will be:
- The default parameter (eg, `self.resistance`) reflects the specification, consistent with constructor arguments. All parameters must have a specificiation.
- Selected values will be prefixed with `actual_`, eg `self.actual_resistance`.

In the future, this might be cleaned up with syntactic sugar, eg `self.resistance.spec` or `self.resistance.actual`.

Closed 2022-02-18.

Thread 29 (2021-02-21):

Allow split nets in generators

ducky64, 2021-02-21:
Currently, links must be fully defined in a generate function or in the base block definition - they can't be split. This makes for some awkward code (though generators are advanced functionality).

One idea to fix this would be to defer link size resolution until all the generators that could attach to a link runs (perhaps sharing infrastructure with #20). Generators would need to declare where they connect, though.

Alternatively, generators could define the block's implementation so the block doesn't elaborate until its generator runs. Which, if it doesn't break any use cases, could be the more elegant solution. This limits to one generator per block.

ducky64, 2021-12-02:
Thinking about the "generators define the block's implementation" a bit more:
- This prohibits multiple generators on a single block (which is probably of dubious value)
- Drawing the boundary of what is available pre-generator and post-generator is the interesting part - and how to make this clean from an engineering standpoint
  - For example, should port parameters be available pre-generator?
  - What about exports of internal blocks (as commonly used for the above, eg the IC's port defines the application circuit block's voltage limits - note that this breaks the 'internal blocks not available pre-generate'))?

As a concrete example of something that could break (I think - not tested yet):
- Buck converter generator requires the current draw to generate
- Buck converter's output voltage depends on the feedback resistor, which is a internal block AND a generator (but not necessarily the buck converter generator)
- Some block powered by the buck converter requires the voltage to calculate its current draw (for example, a resistor)
- and we get deadlock

Ideas
- The generator is structured in the problem model as a sub-block.
  - But there would need to be some syntactic sugar to make this palatable, otherwise generators become cumbersome
    - Or perhaps not? Perhaps the buck converter power stage should be its own sub-block?
    - Perhaps the right answer is a flattening transform? It's more of an aesthetic issue at this point.
  - Interfaces with the containing block must still be declared, eg ports attached to
- Certain parameters must be statically provided to the generator (deadlock manually broken). In the buck converter example, it would take a current draw to size for, instead of deriving the current draw from connected loads.
  - Advantage: provides predictability and stability in design, while good error messages and inspection interfaces allow users to quickly correct mistakes.
  - How should this be structured? Is there a general philosophy / rule here? For example, should generator outputs only be usable in checks (and not to derive further generators)? Should (can?) this be enforced, or is this more akin to a style guide?
  - More general question: what restrictions do we need on parameter dataflow to avoid deadlock or brittle libraries?
- Both of the above?

Closed 2022-02-18.

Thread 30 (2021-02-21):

Eliminate self.get, self._has for generators

ducky64, 2021-02-21:
The generator functions receive the unpacked parameters, but a way is still needed to replace `self.get(some_port.link().name)` and `self.get(some_port.is_connected())` without like a 100-long argument list for microcontroller pin assignment.

ducky64, 2022-02-09:
Potential to be resolved by #92 (parameters should be explicit) and #20 (maybe the self.get - for the pin assign case - can be replaced with array ports of named elements).

Closed 2022-04-07.

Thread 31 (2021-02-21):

Clean up exporting of unconnected ports

ducky64, 2021-02-21:
Anything with the LCD's MISO not-connected causes compiler errors. Datalogger and high-side switch (lights controller) also has issues with unconnected CAN block pins, though is hacked around with explicit dummy block connections.

Solutions might include non-local compiler operations, or generating dummy blocks (either in the frontend or compiler).

ducky64, 2021-09-23:
New solution sketch: explicit not-connected - which is analogous to NC flags in schematics.

Implementation in IR: dummy block with port initialized to nop-defaults. Possibly some TBD syntactic sugar to generate these blocks - either as part of the port (eg, `DigitalBidir.makeDummy()`), or with infrastructural support (`DummyBlock(DigitalBidir)` - but where would this block definition live, automatically generated for all ports, for some ports, explicitly, or ???).

Alternatives considered:
- Remove unused exports - but requires chasing through the export and link chain, and would require deleting (or ignoring) elements from the IR that are not local to the block with the disconnected port. Likely difficult to implement and the result can be confusing.
- Automatically generate dummy blocks: requires core compiler support / refactoring (more complexity in an already somewhat-complex system), also wouldn't catch unintentionally disconnected ports (one of the more useful aspects of schematic ERC).

Closed 2021-09-27.

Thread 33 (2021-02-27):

Port model constructor refactoring: eliminate passing port model, support required parameters

ducky64, 2021-02-27:
For example, `DigitalBidir` can take a port model (another DigitalBidir) as a constructor argument, essentially cloning it. This is a confusing pattern as it requires support in each port definition, and presents an inconsistent interface where it isn't supported.

The current use case seems to be in Bundle definitions, like in the UART where
```python
    self.tx = self.Port(DigitalSource(model))
    self.rx = self.Port(DigitalSink(model))
```

It's "clean" in that it lexically has the `self.Port(DigitalSource(...))` structure, and supports model=None, but "unclean" in that it's passing a port model into the constructor for another port model, which is not a general pattern.

There are other use cases, such as extracting source-only / sink-only parameters from a DigitalBidir. Alternatives may be DigitalSource.fromModel or DigitalSource.fromModelOptional.

This bug only applies to cloning / casting use cases (is-a relationship), and does not apply to composition use cases (has-a relationship, eg passing a port model into a bundle, like the UART example above)

ducky64, 2022-02-10:
Related: add support for required parameters for port construction.

This would still need a null-parameter set for port construction, for link-side instantiation and library construction. Maybe `Port.empty()`?

ducky64, 2022-02-21:
A bit of a braindump going over possible refactoring:

Two main directions: removing port models to be more explicit (eg, `DigitalSource.fromBidir(...)` - pretty straightforward) and rethinking the default empty port (what does `DigitalSource()` mean? - needs more thought).

For (as an example) `DigitalSource()`, there are currently a few use cases:
- Declaring it as a link port, which needs to have uninitialized parameters. This can be more verbose (eg, `self.Port(DigitalSource.empty())`) since this is a power user feature. I believe current semantics have links discard port initializers, but instead this should be check-and-error or check-and-warn.
- Declaring a base class port. As the class shouldn't be in a final design (and causes an abstract class error), the semantics here are less important.
  - In any case, it needs to be override-able by a subclass. Current behavior has it creating a port with the default ideal initializer, but that gets dropped when it is over-assigned. Convenient semantics, but "magical"
  - One option would be to initialize it an empty (implicitly or explicitly). This will require all subclasses override all parameters.
  - The above can be combined with some syntax to allow subclasses to add an initializer to the port, and at least using the same port constructor. It must not overwrite the object (we need to keep the references to the previous object valid), so something like `self.pwr_in.init(VoltageSink(...))` would work.
- Declaring it as a hierarchy port. Normally, this would be solved by `self.Export(...)`, though this doesn't allow the `__init__`/`contents` split for code efficiency purposes.
  - An infrastructural solution to improving `__init__` efficiency would be desirable.
- Declaring an ideal port. `DigitalSource()` is convenient, but an explicit solution might be `DigitalSource.ideal()`.
- Declaring a normal port, with partial model. This is the tricky one.
  - Explicit option: require users to specify each parameter is ideal. Not sure how to resolve this in an elegant way. Ideas: `DigitalSource(voltage=ideal, current=ideal)`.
  - Implicit option: any option not specified is ideal (defaults ideal values). By extension (and for consistency), instantiating a port with no parameters must be ideal - because it would be indistinguishable.
  - Middle option (as below): some parameters may be required (potentially some explicit syntax to force them to be ideal), while some parameters may have defaults.
- Declaring a normal port, with full model. Current syntax is fine, but ideally it would be statically checkable to avoid forgetting parameters, perhaps except for rarely-used or esoteric parameters.

Currently learning towards:
- Obviously get rid of the model syntax (except for compositional / bundle cases)
- Empty should be the special (and explicit) case - it would only be used for links and base classes.
- Hierarchy ports should consistently use `self.Export(...)` syntax. Generators may be the only hard exception, but that's a power user feature anyways.
- Add in an override-init syntax, for subclasses (or forward declarations). This also unifies port syntax for subclasses.
- Unsure how to resolve ideal ports yet, needs more thought.

Closed 2022-03-10.

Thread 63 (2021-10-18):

Take another look at and probably refactor the compiler structure

ducky64, 2021-10-18:
The compiler structure could use another look as feature creep have pushed it beyond the initial clean-ish design. A refactor may be in order...

## Current compiler flow & requirements
Overview: the compiler runs until the outstanding work dependency graph is empty. Each unit of work is an ElaborateRecord - which generally elaborates (expands out) some aspect of the design. The graph starts with an unelaborated top-level block that is ready to go (no dependencies).

The compiler also maintains a ConstProp data structure, which handles parameter assignment and resolves parameter values. It is given constraints (assignments, forced-assignments such as from refinements, bidirectional equality such as from connects), and automatically evaluates expressions as dependencies are resolved. Assertions are stored separately in the top-level compiler.
(TODO: can we get rid of the bidirectional equality special case?)
(TODO: is there a cleaner way to support class-based parameter refinements?)

These supplemental data structures also exist (TODO can we get rid of them / unify them with something else?)
- `connectedLinkParams`: port to its connected link and all params in that link (TBD: recursive?)
- `directConnectedPorts`: all ports that have a direct connection (external side)

These are the elaboration operations:
- **Elaborate block** (entry point)
  - Check for refinements (by path, then by class), and instantiate block
  - Add class-based value refinements (TODO is this the right place for this?)
  - Instantiate ports in-place (replace with library elements? TBD more details)
  - Process constraints
    - `processBlocklikeConstraint` (needs a better name): handles assignments and assertions
    - collect all ports involved in link arrays - to size link ports
      - TODO: the direct connect case is expanded here, perhaps it should be delayed to unify with the array connect case?
      - TODO: the over-connect checks can probably happen here, but need some idea of hierarchy and levels of connection
  - For each connection, generate a ElaborateRecord.Connect, dependent on the port's block, the link, and when CONNECTED_LINK is known [TBD: ???]
    - Exports are dependent on the port's block, the current block (effectively a nop?), and when CONNECTED_LINK is known
  - For any generators: generate an ElaborateRecord.Generator, dependent on required parameters and ports
  - For any internal blocks: generate an ElaborateRecord.Block, dependent on own generators (since internal blocks need to know connected state on ports) and external block connected state
    - TODO: can these conditions be unified into a BlockFullyElaborated item (instead of dealing with them piecemeal), and sub-blocks can't start elaborating until its parent is complete?
  - Link this newly instantiated block into the containing (parent) block
- **Elaborate generator**
  - Dependency parameters values are collected
    - Currently, this also includes (implicitly) IS_CONNECTED and CONNECTED_LINK.NAME for edge ports. TODO: can we make these dependencies explicit, and how can we support CONNECTED_LINK.NAME in the case where IS_CONNECTED is optional?
  - Run the generator, passing in the parameter values
  - Merge the result into original block
- **Elaborate links** (quite similar to block case)
  - Set name variable (TODO this should be done in the other cases too)
  - Process constraints
    - same `processBlocklikeConstraint` for parameters
    - collect all ports involved in arrays (Export with MapExtract)
      - TODO the direct export case is expanded here, perhaps delay to unify?
  - Expand inner links, including arrays
    - For each leaf connection, generate a ElaborateRecord.Connect, dependent on the self link, the inner link, and that its CONNECTED_LINK is known [TBD: ???]
    - And add the direct connected ports of the inner port
    - Generate the new leaf constraint for the exported constraint (TODO: split the expand and elaborate phases?)
    - Set array elements and length parameters of inner port arrays
- **Elaborate connect**
  - Propagate (generate equality for ConstProp) for parameters between the connected ports, as well as CONNECTED_LINK sub-parameters
  - Adds ElaborateConnect records for exports for inner links, dependent on when the links resolve
  - TODO: instead of bidirectional equality constraints, can we instead have fully unidirectional constraints, mainly that parameters propagate towards the link? So the link can't assign any port parameters (except through CONNECTED_LINK)?
- **Elaborate block ports connected** (for block-side ports)
  - For non-connected ports, set just the name (but parameters otherwise empty)
  - Recursively set is-connected status
- TODO: where should things be mutable? Can we contain mutable effects, or make the individual elaborate operations more functional?

Summary of requirements
- Instantiate blocks (and its ports and links, recursively)
- Handle parameters evaluation, both from assignment constraints and connected equality
- Handle generators, dependent on required parameters and ports
- Handle IS_CONNECTED, especially the false case which can only be known after the block is fully elaborated (generators run)
- Handle values of special parameters IS_CONNECTED and NAME
  - IS_CONNECTED only used in MCU pin assignment, as well as an auto-generated constraint in non-optional ports
  - NAME also only used in MCU pin assignment (? - find usages isn't great because `name` gets used in a bunch of other contexts too)
  - Note: IS_CONNECTED does NOT imply that CONNECTED_LINK exists, IS_CONNECTED is a local operation only. Should this be the case? Can we require that IS_CONNECTED implies CONNECTED_LINK exists, even if it only connects to a dummy block?
- Handle link arrays, including nested link arrays

## Relevant issues
- #48 should probably be implemented in the compiler flow - so failures can be piped through and highlighted in the IDE instead of failing to compile completely
- #20 almost certainly requires a significant addition to the compiler, possibly even structural changes to support it

ducky64, 2022-02-01:
Implementation plan, combined with #92 :

Overall modular structure:
- Keep the elaboration dependency graph structure (pending list), seeded with the top-level block
- Keep the const-prop (parameter evaluation) as a distinct module
- The bulk of the logic is in block expansion (from a library reference with no implementation, to the fully expanded design tree)

Block elaboration:
- Blocks have these states: library reference (just a pointer to the library), generator (option step immediately after library reference, contains the generator function name and dependent parameters), and fully elaborated. From #92, there will no more partially elaborated blocks: blocks go from no implementation (library reference or generator) to fully elaborated.
  - Note: fully elaborated blocks may contain unelaborated internal blocks, but its immediate structure is closed to further modification. This does not include parameters, which can continue to change.
- Block elaboration consists of:
  - Copy-paste from the library implementation - relatively straightforward
  - Expand boundary ports - relatively straightforward, but recursive
    - For non-connected boundary ports, set IS_CONNECTED to false
  - Add all non-connectivity constraints to the const prop module (this may also make generators available)
  - Process all connectivity constraints (#20 means that some connections may be dependent on parameters) - add them to the pending list
    - Remap (lower) ALLOCATE ports as needed.
    - Register all connected internal block ports in some global data structure, this is needed to know which ports are not IS_CONNECTED for internal blocks.
  - Expand internal blocks - at this stage, add them to the pending list
  - Expand internal links - at this stage, add them to the pending list
- Link elaboration: looks like block elaboration (they're structurally similar), with the addition of:
  - For ports, set the CONNECTED_LINK parameters of the link itself
  - Skip inner link parameters (for now - if this is necessary, this can be added in the future)
- Connection elaboration consists of:
  - Add equivalence constraints for parameters of both ports. Both ports must be elaborated.
  - Add CONNECTED_LINK parameter equivalence constraints, including CONNECTED_LINK.NAME (note, this depends on the link being elaborated)
  - (for #20) add LENGTH equivalence constraint (where applicable), which may unblock link elaboration (for array links) or block elaboration (via a generator that depends on the LENGTH parameter)
    - Potential issue: if LENGTH propagation is handled by elaboration, and connect elaboration can't happen until both ports are elaborated, and ports require LENGTH to elaborate, this will deadlock. Perhaps LENGTH elaboration should be part of the initial constraint parsing?

Supporting cross-hierarchy features:
- _cross-hierarchy features (like `CONNECTED_LINK`) tend to introduce more complexity into the compiler structure, but are necessary for the current electronics model to work_
- `CONNECTED_LINK`: (see above, set by parameter equivalence constraints on each connect or export constraints)
  - Handling inner links: not supported for now (CONNECTED_LINK can only address the link's immediate parameters)
  - Potential alternative path: CONNECTED_LINK can instead be a 'pointer' to the link instead of passing through all its parameters (as if it were part of the port). But this complicates the rest of the logic since we need pointer support in the parameter system.
  - Potential alternative path: CONNECTED_LINK parameters can be discovered by inspecting into library links, using port-to-link resolution. This allows the connect to expand immediately (excluding length issues - so a dependency graph structure is still needed). Port-to-library-link would be a new feature. This would also be purely static (which is probably a reasonable restriction, especially given the Python structure).
  - Should CONNECTED_LINK elaboration be decoupled from port parameter propagation? Probably not for now.
- `IS_CONNECTED`: (see above, set to true on processing a connected constraint, set to false when a block's ports are elaborated and it was not connected at a upper level)
- `NAME`: parameter can be set when the block is elaborated.
  - Needs to compose with `CONNECTED_LINK`, but `NAME` can be just another parameter that gets passed with all the other `CONNECTED_LINK` items.
- TODO: Should `IS_CONNECTED` be better correlated with `CONNECTED_LINK` being defined?
  - `IS_CONNECTED` currently is a local operation. Even though a port may be connected, it may end up being exported to an optional port. Options:
    - disallow optional ports (require an explicit no-connect operation, which model-wise can create a dummy block)
    - handle exporting of optional ports to other optional ports (how?)

Closed 2022-02-18.

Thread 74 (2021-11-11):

Support multipack devices

ducky64, 2021-11-11:
For example, resistor arrays (which are pretty independent), multi-pack opamps (which share pins like power), multi-pack DACs (which not only share power, but may also share data).

A bunch of open design questions though:

## What level of abstraction?

- **Hierarchical Block Diagram**: for example, replace blocks with a super-block. This would be limited to cases where the blocks being replaced are within the same containing block, otherwise we'll need semantics to directly connect sub-blocks contained within different blocks. I think this limitation is significant... but maybe there are relatively few real-world cases where you pack across hierarchy boundaries?
- **Flattened Block Diagram**: we don't have flattening semantics right now, but doing the multipack replacement after flattening would eliminate the constraint that only sub-blocks of the same parent can be packed.
  - Flattening semantics might not be straightforward: how do we know when a bridge can be consolidated? Or, if we leave the bridges intact, how do we know when the downstream and upstream of a bridge are the "same" port for matching when pins can be consolidated?
- **Netlist**: the maximum amount of flexibility with the minimum amount of thinking about semantics, but also prevents any model checks (or other non-netlisting transformations) on the post-packed design. Packing would be done as part of the netlisting phase.

## What representation?

- At the block diagram level, we can replace constituent blocks with the multipack block. The constituent blocks can either be an abstract type (eg, generic `Opamp`) or a single part of a multipack device (eg, `Mcp6004Part` as a single opamp in a 4-pack `Mcp6004` quad opamp device).
- With the netlist approach, each block would need to be a single part of a multipack device - which allows model checking to happen at the individual part level.
  - How should shared pins be modeled? For example, how to model the power draw of a quad opamp? Should each part draw 1/4 of the total current (which may not be intuitive since it's no longer a straight transcription of datasheet specs)? Or should the first part draw all of the current? Or does it make sense to have a shared resources part (so the quad opamp is 4 power-less opamps plus a power part)? But that wouldn't allow the opamp blocks to depend on power supply parameters, such as would be needed for voltage limits.
- How to determine which pins can be merged? With the assumption that each part is independent until merged (so with the opamp example, each part contains independent power ports), the packer would need to check that all power pins of the parts are on the same net so they can be merged into a multipack device.
  - This could happen at the model level, though cross-hierarchy operations would be difficult.
  - This could happen at the netlist level, which is as close to ground truth as possible, but limits model checking.
  - Or perhaps some weird hybrid approach? The models stay independent, but the packing and packing checks operate on netlists?
  - Should digital control pins be independent? For example, if using a SPI DAC, each individual DAC needs its own CS pin, but a multipack DAC only needs one CS pin. Should each part be connected to the same CS line (which wouldn't make sense if they weren't being multipacked!), or should they be connected to different CS lines and the packer delete the extra lines (which is kind of overly complex and weird)

## Frontend

One idea is to define a block that contains the parts to be replaced. or example, using the Mcp6004:
```python
class Mcp6004(MultipackBlock):
  def __init__(self):
    self.a = self.Block(Mcp6004Part())
    self.b = self.Block(Mcp6004Part())
    self.c = self.Block(Mcp6004Part())
    self.d = self.Block(Mcp6004Part())
    self.pwr = self.Export(self.a.pwr)  # shared power line
    self.connect(self.a.pwr, self.b.pwr, self.c.pwr, self.d.pwr)
    ...
```
Effectively this provides the template to pattern match on - if the parts are connected similarly, they can be replaced by the multipart block, either at the netlist or block diagram level.

Refinements can control which parts are packed together, for example each part can have a `pack_refdes` parameter that specifies the multipack device refdes and part, eg `U1.a`.

ducky64, 2021-12-13:
Random idea:
Can multipack devices be a mechanism to support compositional parts too? For example, a SPI DAC can be viewed as two parts: the SPI interface, and the DAC block. Other subcircuits might want to use the DAC block alone, and multipack support can be a way to connect the interface to an abstract and generic DAC.

More practically, this might allow replacing a feedback resistive divider in a power converter with a controlled element (eg, DAC through some resistor network) that makes it a programmable converter. Though, it probably would break a bunch of the electronics modeling

Note, the other solution for this was some type of multi-domain modeling, where another domain like dataflow specifies that the analog line must be 'connected' to the microcontroller firmware. That might be cleaner, since the constraints are cleaner and perhaps conducive to more powerful automated solvers.

In Chisel, there was also the idea of cross-hierarchy operations as a compiler transform. It's a bit low-level, but similar in concept here. I believe in chip design this kind of stuff might be used for inserting BIST circuits that aren't 'conceptually' part of the 'main' logic, but need to be wired up with it.

ducky64, 2022-01-25:
This was discussed today. Short tl;dr: the best solution at the moment is to handle packing at the netlisting stage, with the EDG IR model using blocks that represent one in a pack of devices (for example, a block being 1/4 of a quad-pack ADC).

Longer recap of options:
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
ducky64, 2022-05-22:
Stepping back a bit, I did a pass on the IR structure in #116. The PR currently encodes multipacking in the main design structure (board top Block) instead of in a supplemental refinements data structure.

There's a larger question about the role and structure of refinements. As currently, refinements:
  - Have non-local effects from the top-level design - for example, changing classes or forcing values arbitrarily deep in the design
  - Are effectively consumed by the compiler (effects of the refinements should be baked into the compiler output)
    - Note, this isn't true for parameter value refinements, the compiler should maybe generate those into constraints - but unsure how to deal with conflicting constraints and this doesn't need to be resolved immediately
  - Are not read in by backends (like the netlister)

Multipack kinda breaks that:
- It's a non-local effect - in fact, the user specification must be with design-path rather than strongly-typed references
- The connectivity data is needed by the netlister, since it affects netlisting - so either the refinement needs to be passed onto the netlister (ugly - especially since it becomes an integral part of the design tree) or baked into the design tree
- The current compromise solution (as in #116) will be to have tunneling exports and assigns live in the design  tree at the top block
  - The multipack blocks themselves would be baked in to the top block like a normal block
- The main inconsistency would be that these would look like HDL constructs but they would be specified in `List[str]` design paths.
  - One possible longer-term solution is to (re)merge `contents()` and `__init__()` so it's possible to do strongly-typed accesses deep through the design tree. Note that this still would not be able to address generators, so this `List[str]` may always need to be necessary
- Alternatively, it may have design-tree structure in the IR but refinements syntax in the user HDL. I think it definitely makes sense to have design-tree structure in the IR.

With the idea that a multipack block is a concrete item in the top block, the user-facing syntax could be a bit more consistent with the regular block definition syntax and preserve some of the niceness of the functional syntax:
```python
class DualOpamp(..., MultipackDevice):  # this would only by the multipack shim block
  def __init__(self):
    self.ic = self.Block(…)  # this is the application circuit block, so contains the cap and the IC block inside

    self.opamp1 = self.PackedPart(Opamp())  # PackedPart and co. are methods on MultipackDevice
    self.opamp2 = self.PackedPart(Opamp())

    # alternative array syntax - as analogous to the Vector (port array) syntax as possible
    self.opamp2 = self.PackedPart(PackedArray(Opamp()))

    # this block has the same ports as the packed components
    self.pwr1 = self.PackedExport(self.opamp1.pwr)
    self.gnd1 = self.PackedExport(self.opamp1.pwr)
    self.pwr2 = self.PackedExport(self.opamp2.pwr)
    self.gnd2 = self.PackedExport(self.opamp2.pwr)
    ...

    # alternative, this could be explicit:
    self.pwr1 = self.Port(VoltageSink.empty())
    self.packed_connect(self.opamp1.pwr, self.pwr1)

class BoardTop(...):
  # This tries to more follow the design-tree syntax.
  # In theory this can go into __init__, but this seems more of a supplemental thing so is in a separate function, more like refinements
  # Because this doesn't need a monolithic multipack() call on the packed device, this may also be more composition and automation friendly?
  def multipacks():
    self.oapack = self.PackedBlock(DualOpamp())  # PackedBlock and pack are methods on BoardTop (or DesignTop); alternatively this can just be Block(...)
    self.pack(self.oapack.opamp1, ['measure', 'follower', 'ic'])
    self.pack(self.oapack.opamp2, ['measure', 'measure', 'ic'])
    # self.pack would also understand array components - where each pack() statement is one allocation
```

One downside here is that there's nothing to check that the packing is valid, that `measure.follower.ic` (in the example above) is of class Opamp, other than perhaps a check that the relevant packing ports exist. Options might be:
- Create a specialty packed Block, eg PackedOpampPart that extends Opamp but is a non-abstract part, and rely on the subclass refinement checking. I'm leaning towards this solution, but it does require that part to be defined.
- Make packing a core IR construct - but may add a lot of specialized complexity into the compiler?
- Have an class equivalence assertion

I think this also address naming?

Closed 2022-06-11.

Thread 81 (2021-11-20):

Adapters and Bridges

ducky64, 2021-11-20:
Adapters are currently widely used (common pattern: Passive-typed port for a low-level device like Resistor, with an adapter to a higher-level subcircuit). The current implementation has a few issues:
- Adapters don't work with bridges, since adapters are only defined on the external-facing ports. So VoltageSink can adapt to AnalogSink, but that port is effectively an VoltageSource if viewed from the inside and lacks the `as_analog_sink` method.
- Adapter creation is ad-hoc, currently as functions on the port (like the above `as_analog_sink`). It'd mildly redundant with the adapter block definition.

TODOs
- [ ] from #97, fix the USB resistor parameter propagation in the Raytac part

Main issues / requirements for designing adapters, to explore new options:

## Bridge Support

Obviously, adapters should work nicely with bridges. Currently, the workaround is to manually instantiate the adapter as a block, or to manually instantiate the bridge. Both break abstraction, are verbose, and are bad. Other options:
- Move adapter creation to infrastructure (instead of a per-adapter method defined on each port). A significant overhaul, not sure how this would work. If it's something like `Passive.adapter_to(VoltageSource, voltage_out=2*Volt)` or `Passive.adapter_to(VoltageSource(voltage_out=2*Volt))`, this may limit what type checkers can catch, since the legal set of adapters isn't encoded.
- Define bridged adapter methods on ports, with the same name. For example, define `VoltageSink.as_analog_source(...)`, that would only work (runtime-checked) in the bridge / internal-facing boundary port case.
- Define bridged adapter methods on ports, with a different name. For example, define `VoltageSink.bridged_as_analog_source(...)`. Similar semantics as above, but with another name. The name won't help static typing tools, but might be nice to be more explicit?
- Or, as below, put adapters on the block-side instead of the boundary port side. Unclear if this will work for all cases.

## Adapter Parameterization

Adapters can have different parameter lists: for example, a VoltageSource -> AnalogSource doesn't need additional parameterrsr because it can take the voltage directly from the VoltageSource port, while a Passive -> AnalogSource needs parameters specified in the adapter (because Passive carries no data).

The current structure `VoltageSource.as_analog_source(...)` allows the functions to define an adapter-specific parameter list which can be type-checked. It uses **kwargs to delegate (and deduplicate) the parameter list and parameter handling to the adapter Block's constructor.

## Tooling Support

Although the IDE doesn't currently support adapter inference, it really should. Since the IDE knows all the library blocks and their super-types, it can determine the adapter block available for some connection. Generating the stylized code under the current setup (`as_someotherport(...)`) is a bit more difficult, Options include:
- Infer the adapter generation function based on type signature and method name.
- Require user-defined annotations (broadly speaking - can be some sort of stylized comment, or a class variable) for tools to support adapter inference.
- More differently, some variation of infrastructural adapter creation (`Passive.adapter_to(VoltageSource, ...)` ) would be more amenable to tooling, though is less friendly to type-checking.

## Multiple Adapters / Connections

A different issue from the above: what rules should there be for multiple adapters on a single port?
- Does the current link checks catch enough issues (at least when the ports involved are non-Passive)?
- When does it make sense to have multiple adapters on a single port? (possibly for a source-type port that feeds multiple things? though maybe the answer should be to only have adapters on the sink side?)
- When does it make sense to have both direct connects and adapters on a single port? (probably similarly to the above?)

## Multi-ported Adapters

Should this be a different thing completely? Or integrated as part of the existing adapters system?

Simplest examples are the GroundSource merger (to tie by direct copper connection two ground source ports) or the AnalogSource merger (similarly, but with a bit of parameter propagation) - both currently structured as regular blocks. More complex is a VoltageSource merger via diode, which is arguably more like a regular block, but arguably could be a static method in VoltageSource.

However, in terms of IDE / tooling, these should probably be inferred and visualized like the single-ported adapters. Maybe with some lighter-weight symbol that isn't just a rectangle.

ducky64, 2023-02-26:
Kinda fixed by allowing the adapter generation on ports of any polarity.

Closed 2023-02-26.

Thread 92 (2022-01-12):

Single-shot generators

ducky64, 2022-01-12:
Perhaps not the most accurate title.

Implementation path to address #29 by preventing the feature - generators would no longer append nets / connections, rather the single generator on a block would define all the connections. This may also simplify parts of the compiler logic, since there was logic and state to handle partially defined blocks.

Before the generator runs, these would be defined on the block:
- Parameters
- Parameter assignments
- No internal blocks are defined
- No connections are defined

The generator then defines these parts of the block:
- Internal blocks
- Connections (between internal blocks, and between boundary ports and internal blocks)
- ... including any parameters

Example issues: buck converter generator
- Actual output voltage is dependent on the feedback resistive divider - and dependent on internal blocks
- The inductor sizing is dependent on the current draw
- There are some components where the current draw is dependent on the voltage (perhaps this is bad practice and can lead to brittle design? perhaps listed voltages and currents must be independent of each other to avoid deadlock?)
- Possible solution: move the generator boundary for the buck converter to internal blocks. For example, instead of the buck converter block generating the power stage, the power stage would be a separate generator block contained within a non-generator buck converter block. This allows the feedback resistive divider and power stage to generate independently, but at the cost of more levels of hierarchy / blocks. However, this structure might enable better re-use in the power converter generator through better modularization.
  - In general, the idea would be to have very minimal generators (instead of more monolithic generators). Downside is that it may mean more individual sub-blocks so we can have those generator boundaries. This structure (top-level block is just a non-generator encapsulating block) also avoids needing the generator to propagate internal block information that the generator needs to run.

Alternatively, a pre-generator block can be more akin to a library block, where it defines nothing at all. This would probably simplify and unify the block elaboration logic.

ducky64, 2022-01-28:
Additional notes:
- The above style of minimalistic blocks (eg, instead of a generator implementing the buck converter interface, there is a buck converter power stage generator that is instantiated by the buck converter itself) may be incompatible with where the block needs to provide pin-mapping. For example, an abstract microcontroller block would need to map connections from the external grab-bag-of-IO interface to the physical pins of the internal chip.
- Under this style, the pin mapping functionality would need to be implemented as a dedicated block, which internally would need edge-port-to-edge-port connections (semantics not well specified), and require links (and possible direction flipping to make the model work out) when connecting to that block. This makes much less sense compared to a direct export.
- One solution to enable the above include some kind of pass-through connection type - but this seems excessive for what may be a rare / special case.
- However, semantics-wise, the proposed single-shot generators would work for pin-mapping blocks, since they have no required parameters and can generate and elaborate immediately (which avoids potential deadlock that requires the above minimalistic generator block style). The downside is that while it's semantically consistent, it is two different styles from the user-facing view.
- Related: generators will likely be required for block-side port arrays, and it is likely that they must be implemented in this style (may have no dependent parameters, aside from optionally the array size of ports). Where more advanced generation is required, it can be delegated to an minimalistic internal block.
- But the above seems to be the least worst solution so far.

ducky64, 2022-02-03:
Need some thought on how dependency parameters are to be expressed, especially if a generator block's parameters aren't declared / elaborated until the generator runs.

Options:
- Generator blocks contain some parameter declarations. This could just be the constructor argument parameters (so it's more guaranteed to be consistent), or may also include boundary port (which should also be guaranteed to be static, with the exception of parameters like arrays).
  - For version 1, constructor argument parameters should be done, and all generator parameters should be explicitly passed in through those. Where others are needed (eg, port parameters), this can be handled by mapping those from an wrapping block to inner generator parameters. More ergonomics can be explored in the future, if needed.
  - Generator parameters would be checked for consistency with parameters declared in the generated block.
  - Downside: some level of generator and generated block "merging" still needs to happen, but vastly simplified from before.
- Generators refer to parameters without those parameters being declared. Works with the current compiler implementation, because it doesn't check for the declarations (just assignments). Not very principled, may not continue to work if declarations are checked.
  - Like the above, minus parameter declarations.
- Generators can only refer to parameters in the containing block. This would be very odd, since the expression would need to refer to parameters in the parent scope (which there currently is not support for).

Closed 2022-02-18.

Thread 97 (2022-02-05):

Multimeter examples TODOs

ducky64, 2022-02-05:
Definitely was a rushed design.

- [x] Ranging circuit: divider needs to go to the input negative, not GND (blue wire fix confirmed in testing)
- [x] ~Ground negative input, use a switched cap inverter + diff-amp to re-center negative voltages~ may not be a good idea
  - Note: scope node used LM2660
  - Inverter selection:
  - Dual-rail analog switch selection
    - SPST switches: DG9421/2, ADG601/2, MAX4675/6 are pin-compatible
      - DG467/8 and DG447/8 are compatible and inexpensive
    - Note: 2:1/1:2 muxes are uncommon / unavailable for dual-rail
- [x] ~Actual clamping diodes~ the 1M input resistor is probably good enough, if it's high volt rated
- [ ] High voltage input protection - resistor, fuse (PPTC or otherwise), TVS suppressor (Zener diode or MOV) - suppress input voltage down to levels within the device ratings.
- [x] nRF: VBUS needed if USB is being used (blue wire fix confirmed in testing)
- [ ] Ranging circuit: don't need the 1:10000 step (at 4096 counts, centered around zero, this gives a 30kV full scale (at like 4 volts per bit), which will fry everything else)
- [ ] Ranging circuit: support more ranges, depends on #20, probably a 1:10, 1:100 step, maybe also a 10:1 amplification step
  - 10:1 amplification unnecessary, MCP3561 has internal amplifier 1/3 to 64x
- [x] Speaker circuit: needs to be redone, ~the fake-ADC does not work well for audio-frequency signals (could also be a software issue)~ (it was a software issue, mbed's PwmOut is limited to 1us increments)
  - [x] Use a class-D amp for efficiency. TPA2005D1 and PAM8302A are pin-compatible in MSOP-8. Use single-ended mode.
  - [x] Lower the filter cutoff frequency to like 2kHz
- [x] Speaker to use a base Connector class
- [x] Add battery measurement circuit (optionally w/ disable?)
- [x] nRF: perhaps replace with easier to source (but also difficult-to-solder LGA instead of castellated pads) MDBT50Q-1MV2
  - Note: MDBT50Q-512K (nRF52833) also exists and appears partially pin compatible. No mbed support yet.
- [x] ~Transflective LCD~
  - no great options in the desired form factor - [G132CLGFGSW6WTCCXAL](https://www.digikey.com/en/products/detail/focus-lcds/G132CLGFGSW6WTCCXAL/12691213) and similar come close but the bezel positioning is awful
- [x] nRF: P1_0 needs TRACECONFIG cleared, otherwise SWO asserts control over the pin
- [x] Higher resolution ADC
  - Selected: MCP3561R (24b w/ optional internal voltage reference)
  - MCP3461 (16b, 50sps-153ksps), MCP3561 (24b, 50sps-24b/19ksps-16b/153ksps) - both with programmable oversampling rate, pin compatible (including multipack)
  - MPC3553 (22b 60Hz) - Dout only, non-configurable
  - MAX11205 (16b) / MAX11208 (20b) / MAX11201 (24b) - Dout only, non-configurable; ultra-low-power; optional external clock
- [x] Power: separate analog rail
- [x] Power: better boost converter chip
  - XC9142 (0.3 ohm NMOS and PMOS, 800mA, 0.9V startup), pin compatible with XC9140 (0.6ohm NMOS, 0.65ohm PMOS, 0.9v startup), semi-pin-compatible with LTC3525 (0.5ohm NMOS, 0.8ohm PMOS, 400mA, 0.85v startup) and MAX1724 (0.5ohm NMOS, 1ohm PMOS, 150mA, 0.91v startup)
- [x] ~Isolated USB~ high complexity and cost, perhaps a future revision
- [x] ~Infrastructure: better port bridging - to get rid of the USB resistor hack for the Raytac MDBT part~ delegated to #81
- [x] MergedAnalogSource to bridge the input negative and output of the source selection (actual ground vs. Vdd/2 virtual ground)

To be tested:
- [x] Driving circuit - constant current into current meter
  - Directly into multimeter mA input: 1mA control -> 1.047mA (reading 13mV)
  - Mostly similar (except for positive input facing nodes, including diode in and out) at -19.3v
- [x] Continuity test - with driver active, voltage goes to zero when shorted ... obviously
- [x] Resistance test - reads a reasonable voltage given the drive strength, into a resistor
- [x] Diode test - reads a reasonable voltage into a LED, about ~100mV off against a Fluke meter, but the drive strength is configured higher (2mA)
- [x] High voltage resist in measurement mode (driver disabled)
  - With -19.3v input:
    - 3.230v at both driver gate and into output of resistor (note, 3.232v at positive rail)
    - In direct measurement mode: -0.324v at 1M res out (measurement side), reading -1648mV
    - 17uA out of multimeter positive terminal
  - With +19.3v input:
    - Driver: 20.96v at diode output, 0.083v at diode input, 3.235v at driver FET gate and 3.236v at current-set resistor out
    - In direct measurement mode:  3.486v at 1M res out, 3.236v at buffer out, reading 1649mV
    - 18uA into multimeter positive terminal
- [x] High voltage resist in driving mode (for if the user accidentally a connection)
  - Into 1.4v voltage source: 1.048mA (reading 1444mV); ramping down to zero from 1.5v to 3.0v; -6uA into a 10v source (reading 3299mV), -16uA into a 19.3v source (reading 3299mV)
  - Into negative voltage source: 1.058mA (reading 0mV) into -10v source, 1.067 (reading 0mV) into -19.3v source
  - At -10V: voltage at diode out: -10.05v, voltage at diode in: -9.47v, voltage at 1M res out (measurement side) -0.313v, voltage at measure buffer out: 0.000v; voltage at R19 (current-setting resistor) out 2.187v; voltage at Q3 (constant current driver) gate: 1.606v
- [x] Swap in MCP3553 (22b sigma-delta ADC) for testing - works fine, noise is relatively high compared to LSB, but was probably expected
  - Measurements: (with 1:10 range) -19.28 -> -19417mV; +19.28 -> 19902mV; (with 1:1 range) 1.406 -> 1436mV; (with 1:1 range) -1.407 -> -1431mV;

Closed 2022-05-06.

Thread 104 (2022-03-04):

Mixin Types

ducky64, 2022-03-04:
One potential issue with abstract microcontroller types (#23, enabled by #20 which is coming soonTM) is that while we can reasonably define an abstract micro with all the common IOs (GPIO, SPI, IIC, ADC, DAC, CAN, UART, maaaaaybe USB + Vbus), there may be a long tail of IOs (not necessarily super important right this moment), and are IOs that are necessary but not universal (for example, oscillator or clock inputs, needed for USB and CAN on many bare micros but not present on things like dev boards).

A possible solution is a mixin type: a way to add capabilities (including structural - like ports) to a base Block type.

For example: we would have a base `Microcontroller` type with GPIOs and stuff, and a `MicrocontrollerWithOscIn` (or something with better name) that extends `Microcontroller` but adds an oscillator input port. Then, a microcontroller supporting that (eg, `Lpc1549`) would extend `MicrocontrollerWithOscIn` while one not supporting it (eg, `Nucleo_F303k8` dev board) would only extend `Microcontroller`.

On the instantiation side, the system designer could ask for an abstraction `Microcontroller` with `MicrocontrollerWithOscIn` (and potentially other mixins) - which both preserves the design space of compatible microcontrollers for the refinement system (instead of hardcoding, for example, `Lpc1549` in the design) while also encoding the constraint that the oscillator port is required.

Python's multiple inheritance system should support this on the block definition side, however it's less clear how to support this on the instantiation side. Worst case, perhaps a class could be defined, for example `MyMicrocontrollerWithNeededMixins` extends `Microcontroller` and `MicrocontrollerWithOscIn`. Alternatively, perhaps some kind of syntax, for example `self.Block(Microcontroller.withMixins(MicrocontrollerWithOscin)()`.

In all cases, since the block extends the base Block (eg, `Lpc1549` extends `Microcontroller` even though it also has mixins), it must be able to be usable when none of the mixins are used. In this case, the oscillator pin would be ignored if disconnected (though this can fire assertions, for example if USB is also used).

Potential microcontroller mixins:
- Needed now:
  - Oscillator input
  - SWD programming port
  - (maybe) USB (with Vbus - ignored if the chip doesn't use it) - since not all chips support USB
  - (maybe) CAN, DAC - similar reason
- Possible in the future:
  - other programming ports: JTAG, more
  - RTC crystal input

Potential other mixins:
- EN pin on voltage regulators - perhaps also encoding whether it's active-high or active-low.
  - The block would need to be reactive to if the EN pin is not connected. This requires a generator to tie the EN pin high or low.
- Feedback pin on voltage regulators - allows external programming

Open questions:
- As above, the right instantiation-side syntax for declaring a port with mixins
- In the EN pin on voltage regulators case: is there a way to achieve this without generators? Some kind of conditional connect statement?
- What else can mixins support? Should they support keyword arguments?
- What issues arise with multiple inheritance support? Does the current compiler implementation support multiple inheritance well?

Alternatives:
- For oscillators: should the crystal generation be internal to the microcontroller? For example, the microcontroller will generate a crystal if the frequency required is beyond the internal RC's tolerance, or if certain timing-sensitive ports (like USB) are used.
- A generalization of the above: when should mixins be used, vs when should required blocks auto-generate?
  - Options may be best, for example supporting an oscillator mixin, but auto-generating crystals if needed and the oscillator port is not connected.
- Other options?

---

Things that need to be fixed:
- The default SWD target has a TDI pin, which is nonstandard and should be an optional addition

Closed 2023-06-28.

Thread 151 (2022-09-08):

Remove array literal

ducky64, 2022-09-08:
This seems redundant with the ValueExpr.Array array-from-arbitrary-expression constructor. The main reason literals are used are to ensure only literals are passed through generators, but those can be modified to take arbitrary ValueExpr and fail on non-literal cases.

rohit507, 2022-09-13:
> This seems redundant with the ValueExpr.Array array-from-arbitrary-expression constructor. The main reason literals are used are to ensure only literals are passed through generators, but those can be modified to take arbitrary ValueExpr and fail on non-literal cases.

The original reason for this was to make the literal message in the proto structurally distinct from expressions. Remove that and you need to add a bunch of checks for whether each expression is a literal wherever you use them.

This makes more sense in a well-typed language like Scala or Haskell.

I'd treat reusing ValueExpr as a code smell but that might not be worth it if it adds a lot of boilerplate.

ducky64, 2022-09-15:
I think in the end those applications that require literals are requiring a subset of the IR. The current structure with array literals means that the types are well bounded (structurally impossible to have a non-literal value), but even without array literals I don't think the code would look too much different since it just tests cases - it can just fail if it sees a non-literal. Scala can statically check for match completeness including on proto, I don't think Python can do that.

This isn't too bad of an issue with arrays, since it's just one more thing. But if we have more containers / collections in the future we also need to grow the parallel structures maintained, which may be undesirable. This is a possible way to minimize the IR, but I'm not super attached to it.

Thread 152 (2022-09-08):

Robot driver example fixes

ducky64, 2022-09-08:
- [x] Isen on motor driver needs to be grounded
- [x] the 2-pin PH SMT connectors are horrible, they will not demate
- [x] add 3-pin connector for WS2812 extensions
- [x] there are 4 input-only IOs =(
- [x] TBD as more bringup happens

ducky64, 2023-01-27:
All major blocks on the driver tested!

Closed 2023-01-27.

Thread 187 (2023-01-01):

Support offset voltages

ducky64, 2023-01-01:
Currently, the system assumes all grounds are at 0v, which is reasonable for many systems. However, two applications break this assumption: offset grounds (eg, in a series battery pack, circuits might be referenced to different cells - primarily relevant for BMSes) and isolation.

No applications currently use offset grounds (this will change soon...), and isolation is handled with separate nets (though there's no isolation enforcement).

Ideas for supporting offset grounds:
- Status quo: we assume each ground is at zero, so nothing needs to change. Effectively, a positive source only defines the local voltage. Users must be diligent about signals that cross different grounds, because the model will false-negative since it's unaware of the ground offsets.
- Precise ground offset. The main problem with encoding grounds as a range (and supporting tolerances) is anything referenced from that then inherits that tolerance - for example, a signal stacked on top of a 5v +/- 5% ground inherits the ground's tolerance, and because operations always expand tolerance, subtracting the ground does not recover the original signal. So grounds must be at exactly one voltage (presumably the nominal voltage?), even if not zero. But this won't do proper tolerance stackup analysis across ground domains.
  - Not all nodes have a clean fixed reference voltage even if tolerance is ignored - for example, a switching node in a power converter oscillates between voltages. It could be set at the average (or either extreme), but the full tolerance stackup would be incorrect.
  - This requires refactoring all the examples and libraries so signals have a defined reference. Which really is probably a good API anyways.
  - Maybe there could be some kind of implicit ground for syntactic sugar - TBD what the semantics would look like.
  - Isolation can be defined in terms of the maximum offset voltage.
- Symbolic analysis. Maybe not a full blown symbolic solver (yet?), but grounds provide a reference variable that other values can be defined in terms of .
  - For example, a ground defines `g`. A signal voltage can then be defined in terms of that, for example v = g + 5v +/- 5%. A check might be v within g and g + 10v, and the solver would cancel out the gs without introducing additional tolerance, even if g was defined as 10v +/- 5% referenced to something else.
  - This could be API compatible with the above - it could be practical to start with the above, then the solver / internal representation could be swapped without library and example changes.
  - Isolation can be defined as the range of offset voltages.
  - Needs a lot of thought on how this should be exposed to the user (both at the edg_core level and electronics model level) and defined in the IR.
    - What is the return value and type of an expression where not all variables cancel out?

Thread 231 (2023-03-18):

Incremental connect building

ducky64, 2023-03-18:
Restore the old connect algorithm which would error immediately on an invalid connection, instead of the current structure which loses the line number when it stack-traces.

Additionally, fix net join, though that may be tricky (eg, what name to assign, if multiple names are assigned).

ducky64, 2023-08-02:
Fixed in #274

Closed 2023-08-02.

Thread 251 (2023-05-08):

Compiling with blocks defined outside of library.

imuli, 2023-05-08:
After refactoring my board into nice sub-modules, I was very confused when it no longer compiled!

Example following the blinky tutorial:

```python
from edg import *

class Lf21215tmr_Device(FootprintBlock):
  def __init__(self) -> None:
    super().__init__()
    self.vcc = self.Port(
      VoltageSink(voltage_limits=(1.8, 5.5)*Volt, current_draw=(0.5, 2.0)*uAmp))
    self.gnd = self.Port(Ground())

    self.vout = self.Port(DigitalSource.from_supply(
      self.gnd, self.vcc,
      current_limits=(-9, 9)*mAmp,
      output_threshold_offset=(0.2, -0.3)
    ))

  def contents(self) -> None:
    super().contents()
    self.footprint(
      'U', 'Package_TO_SOT_SMD:SOT-23',
      {
        '1': self.vcc,
        '2': self.vout,
        '3': self.gnd,
      },
      mfr='Littelfuse', part='LF21215TMR',
      datasheet='https://www.littelfuse.com/~/media/electronics/datasheets/magnetic_sensors_and_reed_switches/littelfuse_tmr_switch_lf21215tmr_datasheet.pdf.pdf'
    )

class Lf21215tmr(Block):
  def __init__(self) -> None:
    super().__init__()
    self.ic = self.Block(Lf21215tmr_Device())
    self.pwr = self.Export(self.ic.vcc, [Power])
    self.gnd = self.Export(self.ic.gnd, [Common])
    self.out = self.Export(self.ic.vout)

    self.cap = self.Block(DecouplingCapacitor(capacitance=0.1*uFarad(tol=0.2)))
    self.connect(self.cap.pwr, self.pwr)
    self.connect(self.cap.gnd, self.gnd)

  def contents(self) -> None:
    super().contents()

class BlinkyExample(SimpleBoardTop):
  def contents(self) -> None:
    super().contents()
    self.usb = self.Block(UsbCReceptacle())
    self.reg = self.Block(VoltageRegulator(3.3*Volt(tol=0.05)))
    self.connect(self.usb.gnd, self.reg.gnd)
    self.connect(self.usb.pwr, self.reg.pwr_in)

    with self.implicit_connect(
        ImplicitConnect(self.reg.pwr_out, [Power]),
        ImplicitConnect(self.reg.gnd, [Common]),
    ) as imp:
      self.mcu = imp.Block(IoController())
      # if the following two lines are commented out it compiles fine
      self.mag = imp.Block(Lf21215tmr())
      self.connect(self.mcu.gpio.request('mag'), self.mag.out)

      (self.sw, ), _ = self.chain(imp.Block(DigitalSwitch()), self.mcu.gpio.request('sw'))

      self.led = ElementDict[IndicatorLed]()
      for i in range(4):
        (self.led[i], ), _ = self.chain(self.mcu.gpio.request(f'led{i}'), imp.Block(IndicatorLed()))

  def refinements(self) -> Refinements:
    return super().refinements() + Refinements(
    instance_refinements=[
      (['reg'], Tps561201),
      (['mcu'], Esp32_Wroom_32),
    ],
    instance_values=[
      (['mcu', 'pin_assigns'], [
        'led0=26',
        'led1=27',
        'led2=28',
        'led3=29',
       ])
    ])

if __name__ == "__main__":
  compile_board(BlinkyExample, ("./", "blinky"))
```

Upon running `python blinky.py` I get a lot of errors that look like:

```
Traceback (most recent call last):
  File "/nix/store/2lq7wa3rj44nr4jjr8ap44h5y28hcy61-python3-3.10.10-env/lib/python3.10/site-packages/edg_hdl_server/__main__.py", line 100, in run_server
    cls = class_from_library(request.get_library_element.element,
  File "/nix/store/2lq7wa3rj44nr4jjr8ap44h5y28hcy61-python3-3.10.10-env/lib/python3.10/site-packages/edg_hdl_server/__main__.py", line 77, in class_from_library
    cls = getattr(elt_module, elt_split[-1])
AttributeError: module '__main__' has no attribute 'Lf21215tmr'
```

which seems to indicate that it can only pull classes from the `edg` library, not from the user's modules.

imuli, 2023-05-08:
This can be worked around by creating a seperate `__main__.py` like this:

```python
from .blinky import BlinkyExample
from edg import compile_board

if __name__ == "__main__":
  compile_board(BlinkyExample, ("./", "blinky"))
```

Otherwise it appears that `edg_hdl_server` loads itself as `__main__` and tries to find the class inside itself.

ducky64, 2023-05-08:
Yeah, working on fixing this, I think I found the issue. The problem is that the file run in the `python` command is internally referred to as `__main__`, but the compiler spins up a separate HDL interface server which has itself as `__main__`, and it can't resolve `__main__` references in the original file since it has a different idea of what `__main__` is.

I think in general, if you put libraries in the not-`__main__` file it should work, but a fix is coming soon.

ducky64, 2023-05-08:
Should work now, and a new version (0.0.1) should be available on pip.

Closed 2023-05-08.

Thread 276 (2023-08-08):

CS as part of the SPI interface

ducky64, 2023-08-08:
... maybe, not completely sure this is a good idea ...

Currently, CS is modeled as a digital IO separate from the SPI port, instead of as part of it (like SCK/SDI/SDO). Perhaps CS should be moved into being part of the SPI interface?

Advantages:
- Don't need to connect CS separately, one less connect statement for SPI interface devices
- For microcontrollers: can model peripheral pin restrictions for CS pins in peripheral mode
  - And also having a CS pin defined would be correct-by-construction, impossible to forget about
- Pretty straightforward on the peripheral side, a single DIO for CS

Challenges (and pretty substantial ones too):
- Not straightforward on the controller side, it's a DIO vector since the port may service multiple peripherals
  - Requires logic to support nested ports arrays, since IoController SPI controller ports are arrays, which may further have nested CS port arrays in each SPI controller port
  - Nested port arrays must be exposed to generators
    - Some kind of recursive dict infrastructure? idk
- What would test points look like?
  - How to specify CS on only a subset of test points?
- For manually-specified pin assignment: how to keep the names reasonable?
  - e.g. instead of an numeric array index like `my_spi.cs.2` we would want `my_spi.cs.oled`
  - which would need some way to assign names to link elements, e.g. `connect(oled.spi, spi.new_peripheral('oled'))` (which is a substantial departure from how link port allocation is currently done)

ducky64, 2024-07-24:
Probably not worth the complexity

Closed 2024-07-24.

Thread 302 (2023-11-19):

Better error messages from port array errors

ducky64, 2023-11-19:
... those stack traces are the worst ...

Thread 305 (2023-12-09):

IoController with PowerOut fails when power or ground is unconnected

ducky64, 2023-12-09:
... for instance when using a switch matrix where the only connection is IO

The reasoning seems to be from pwr_out not having a link, so DigitalBidir.from_supply(...) which tries to inspect the power rail links fails.

A solution might be to have a BaseVoltagePort base class that defines voltage_range and the link, which dynamically determines whether it gets its own voltage (if a source) or its links voltage (if a sink). If there's bidirectionality, this might be more complex and require if-then-else logic

ducky64, 2024-04-21:
Resolved by #315

Closed 2024-04-21.

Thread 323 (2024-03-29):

PMOS reverse protections

Suke0811, 2024-03-29:
## Pmos

From 1.
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

Implementation:
https://github.com/BerkeleyHCI/PolymorphicBlocks/blob/5bb5b504e6a5da03bbd40ef9a66a422e02ea0a58/electronics_lib/PowerConditioning.py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

## PMOS for bi-directional application (Low voltage)

From 2.
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

Implementation:

https://github.com/BerkeleyHCI/PolymorphicBlocks/blob/5bb5b504e6a5da03bbd40ef9a66a422e02ea0a58/electronics_lib/PowerConditioning.py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

Currently, this code gets stuck during the netlist generations
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

## Ref
1.  https://components101.com/articles/design-guide-pmos-mosfet-for-reverse-voltage-polarity-protection
2.  https://www.edn.com/reverse-voltage-protection-for-battery-chargers/

Suke0811, 2024-04-01:
- duplicated r1/r2 naming issues now detected with ducky update (5cbf405b4c51cfc1389c8e80515faf2c7b2c650b)

- Updated the charging protection to use schematics
chg and the power_out is manually connected, and the block looks like this?
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

```python
    chg_adapter = self.Block(PassiveAdapterVoltageSink())
    setattr(self, '(adapter)chg', chg_adapter)  # hack so the netlister recognizes this as an adapter
    self.connect(self.mp1.source, chg_adapter.src)
    self.connect(self.chg, chg_adapter.dst)
    ```

ducky64, 2024-04-01:
Yeah, the diagram weirdness is from some weirdness in how the underlying layout libraries handles connections between exterior ports.

Suke0811, 2024-04-30:
#328

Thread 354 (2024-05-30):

Dedicated Ground type

ducky64, 2024-05-30:
because `gnd` and `gnd_out` in the microcontroller dev board is actually pretty confusing

Idea: unify it into a single bidirectional gnd type. Voltage-source-to-ground requires an explicit conversion (which it probably should).

Some considerations:
- How to support offset grounds? Perhaps there does need to be a GroundSource that supports offset-grounds, while a link with no GroundSource is zero implicitly? (and conflicting GroundSources are an obvious error)
- How should voltage APIs look like? Perhaps Voltage[Source|Sink].voltage_from(gnd)? Likely all the port constructors should have a ground reference?

ducky64, 2024-07-14:
Resolved by #364

Closed 2024-07-14.

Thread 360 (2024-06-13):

Materialize disconnected output links

ducky64, 2024-06-13:
For VoltageSource/VoltageSink, port.link().voltage is useful to get the port voltage. In the VoltageSource case, this is intuitive even if the link isn't connected. Currently, the link doesn't exist (because the port is disconnected) and the link voltage parameter doesn't exist (unsolved). One example in practice is a microcontroller dev board with power out that is the power rail, but isn't used elsewhere. GPIOs that reference that then have missing parameters.

Current workaround: VoltagePort._voltage_range that inspects if it's a source or sink, and returns its own voltage out or the link voltage respectively. Definitely a hack. This doesn't require any more generator support, since the port type is known. This no longer works with an undirectioned Ground.

Potential solutions:
- Materialize a link for all disconnected ports. This will (probably) blow up the design size and compile time. These links may also not be valid.
- Materialize a link for selected disconnected ports. This eliminates the size problem above, but requires the block writer to know this specific API. A bunch of questions though:
  - What does IS_CONNECTED return? Model-wise it's true, but we may want to assert it's not connected.
  - Is there a way to make this conditional - eg only materialize the link if some other port is or is not connected? This would also be separate from generators, since links need to be created in the parent context.
- Materialize link parameters for disconnected ports. The compiler will create parameters for disconnected ports by processing a connected link, skipping link legality checks (is this a good idea?). It will not materialize the link, so avoids design size explosion, but computation is still required to process the link.
- Materialize link parameters for selected disconnected ports. Kind of avoids computational explosion above, but requires another specialized IR construct.
- Allow explicit assignment of link().voltage in the block, even if the port is disconnected. This solves a lot of problems and can leverage generator logic.

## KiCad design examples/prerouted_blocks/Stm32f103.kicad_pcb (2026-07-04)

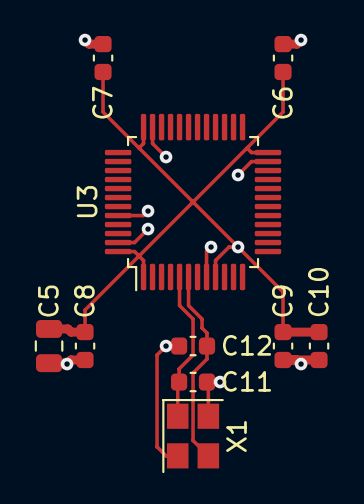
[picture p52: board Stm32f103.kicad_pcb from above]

Board: 2 copper layers, 10 parts (0 on the bottom side), 4 nets.

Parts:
C5: C1779; C_0805_2012Metric
C6, C7, C8: C14663; C_0603_1608Metric
C9: C57112; C_0603_1608Metric
C10: C15849; C_0603_1608Metric
C11, C12: C1663; C_0603_1608Metric
U3: C8734; LQFP-48_7x7mm_P0.5mm
X1: C9002; Crystal_SMD_3225-4Pin_3.2x2.5mm

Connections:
gnd: C5.2, C6.2, C7.2, C8.2, C9.2, C10.2, C11.2, C12.2, U3.8, U3.23, U3.35, U3.44, U3.47, X1.2, X1.4
mcu.crystal.crystal.a: C11.1, U3.5, X1.1
mcu.crystal.crystal.b: C12.1, U3.6, X1.3
v3v3: C5.1, C6.1, C7.1, C8.1, C9.1, C10.1, U3.1, U3.9, U3.24, U3.36, U3.48

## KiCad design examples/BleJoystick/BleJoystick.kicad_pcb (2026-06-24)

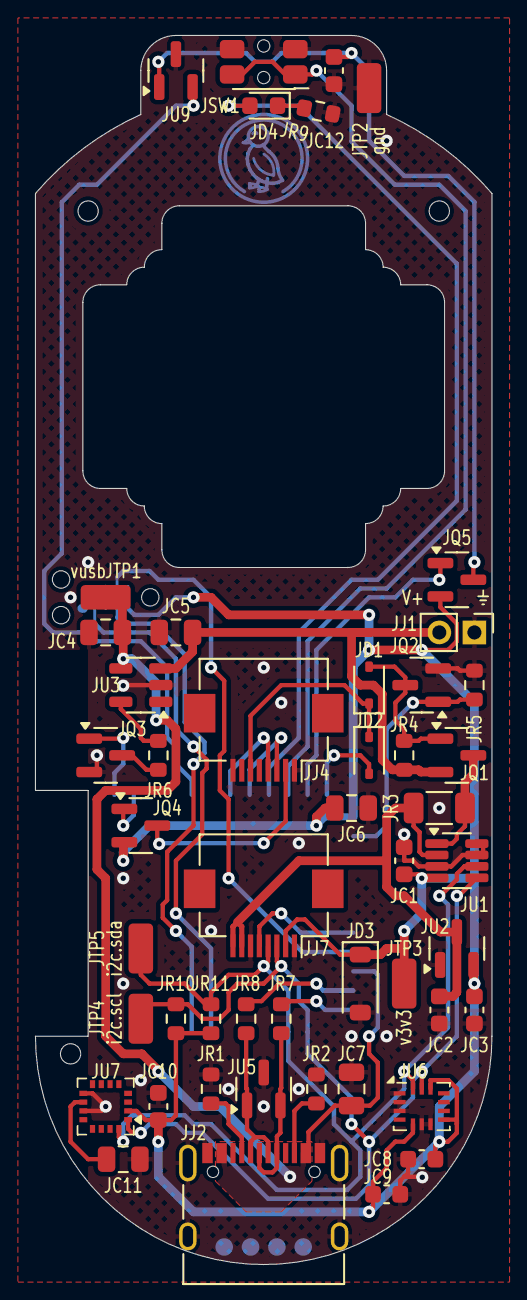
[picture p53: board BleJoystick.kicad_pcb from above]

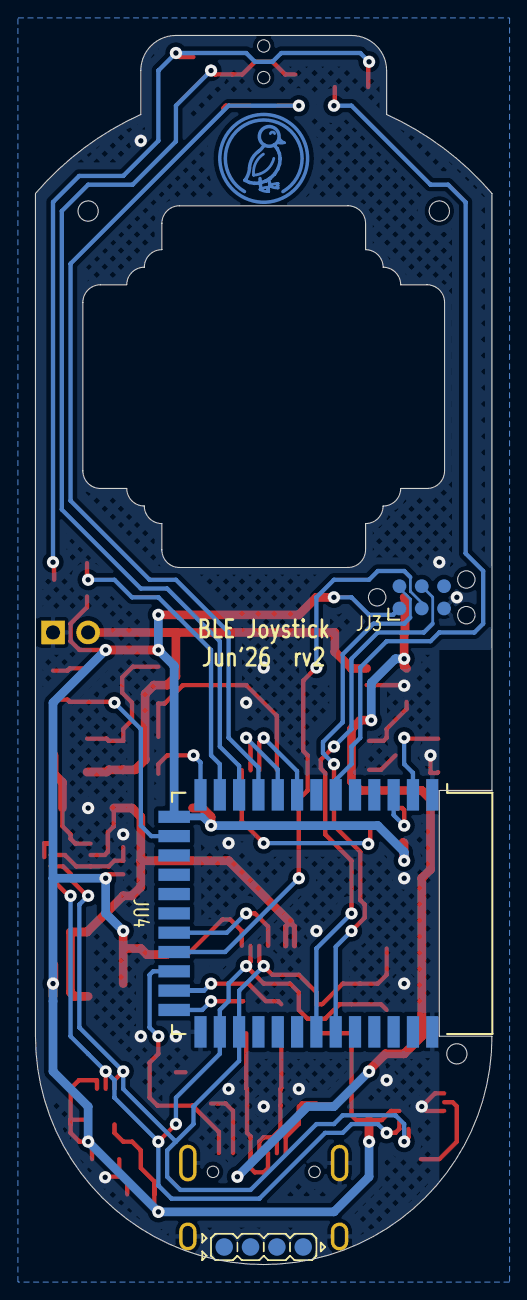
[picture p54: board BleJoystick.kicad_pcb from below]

Board: 2 copper layers, 26.0 x 70.0 mm, 55 parts (3 on the bottom side), 36 nets.

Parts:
JC1: vbat_sense.vs_cap; C_0603_1608Metric
JC2: reg_3v3.in_cap; C_0603_1608Metric
JC3: reg_3v3.out_cap; C_0603_1608Metric
JC4: chg.vdd_cap; C_0805_2012Metric
JC5: chg.vbat_cap; C_0805_2012Metric
JC6: mcu.vcc_cap; C_0805_2012Metric
JC7: mcu.vbus_cap; C_0805_2012Metric
JC8: imu.vdd_cap; C_0603_1608Metric
JC9: imu.vddio_cap; C_0603_1608Metric
JC10: mag.vdd_cap; C_0603_1608Metric
JC11: mag.c1; C_0805_2012Metric
JC12: trig.cbyp; C_0603_1608Metric
JD1: gate.ctl_diode; D_SOD-323
JD2: gate.btn_diode; D_SOD-323
JD3: prot_3v3; D_SOD-123
JD4: ledr.package; LED_0603_1608Metric
JH1: jlc_th.th1; JlcToolingHole_1.152mm
JH2: jlc_th.th2; JlcToolingHole_1.152mm
JH3: jlc_th.th3; JlcToolingHole_1.152mm
JJ1: bat; PinHeader_1x02_P2.00mm_Vertical
JJ2: usb.conn; USB_C_Receptacle_XKB_U262-16XN-4BVC11
JJ3: mcu.swd; Tag-Connect_TC2030-IDC-NL_2x03_P1.27mm_Vertical
JJ4: stick; Hirose_FH12-8S-0.5SH_1x08-1MP_P0.50mm_Horizontal
JJ7: btns; Hirose_FH12-8S-0.5SH_1x08-1MP_P0.50mm_Horizontal
JQ1: gate.pwr_fet; SOT-23
JQ2: gate.amp_fet; SOT-23
JQ3: chg.prog_sw; SOT-23
JQ4: stick_gate; SOT-23
JQ5: trig_gate; SOT-23
JR1: usb.cc_pull.cc1; R_0603_1608Metric
JR2: usb.cc_pull.cc2; R_0603_1608Metric
JR3: vbat_sense.Rs; R_1206_3216Metric
JR4: gate.pull_res; R_0603_1608Metric
JR5: gate.amp_res; R_0603_1608Metric
JR6: chg.prog_res; R_0603_1608Metric
JR7: mcu.usb_res.dp; R_0603_1608Metric
JR8: mcu.usb_res.dm; R_0603_1608Metric
JR9: ledr.res; R_0603_1608Metric
JR10: i2c_pull.scl_res; R_0603_1608Metric
JR11: i2c_pull.sda_res; R_0603_1608Metric
JSW1: bumper_sw; SW_SPST_EVQP7C
JTP1: vusb; TestPoint_TE_RCT_0805
JTP2: gnd; TestPoint_TE_RCT_0805
JTP3: v3v3; TestPoint_TE_RCT_0805
JTP4: i2c.scl; TestPoint_TE_RCT_0805
JTP5: i2c.sda; TestPoint_TE_RCT_0805
JU1: vbat_sense.ic; SOT-23-8
JU2: reg_3v3.ic; SOT-23
JU3: chg.ic; SOT-23-5
JU4: mcu.ic; Holyiot-18010-NRF52840
JU5: usb_esd; SOT-23
JU6: imu.ic; Bosch_LGA-14_3x2.5mm_P0.5mm
JU7: mag.ic; LGA-16_3x3mm_P0.5mm
JU9: trig.ic; SOT-23
duck: G***; Symbol_Duckling

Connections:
Jbtns.io0: JJ7.5, JU4.20
Jbumper_sw.out: JSW1.1, JU4.11
Jchg.ic.prog: JR6.2, JU3.5
Jchg.prog_ctl: JQ3.1, JU4.2
Jchg.prog_res.gnd: JQ3.3, JR6.1
Jgate.btn_in: JD1.1, JD2.1, JJ4.6
Jgate.btn_out: JD2.2, JU4.13
Jgate.control: JQ2.1, JR5.2, JU4.15
Jgate.pull_res.b: JD1.2, JQ1.1, JQ2.3, JR4.2
Jgnd: JC1.2, JC2.2, JC3.2, JC4.2, JC5.2, JC6.2, JC7.2, JC8.2, JC9.2, JC10.2, JC11.2, JC12.2, JD3.2, JJ1.1, JJ2.A1, JJ2.A12, JJ2.B1, JJ2.B12, JJ2.S1, JJ3.5, JJ4.1, JJ4.8, JJ7.1, JJ7.6, JQ2.2, JQ3.2, JR1.1, JR2.1, JR5.1, JR9.2, JSW1.2, JTP2.1, JU1.3, JU1.7, JU1.8, JU2.1, JU3.2, JU4.1, JU4.25, JU4.37, JU5.3, JU6.1, JU6.2, JU6.3, JU6.6, JU6.7, JU7.9, JU7.11, JU9.3
Jledr.package.k: JD4.1, JR9.1
Jledr.signal: JD4.2, JU4.10
Jmag.ic.c1: JC11.1, JU7.10
Jmcu.reset_node: JJ3.3, JU4.21
Jmcu.swd_node.swclk: JJ3.4, JU4.31
Jmcu.swd_node.swdio: JJ3.2, JU4.32
Jmcu.usb_res.interior.dm: JR8.2, JU4.23
Jmcu.usb_res.interior.dp: JR7.2, JU4.24
Jstick.ax1: JJ4.4, JU4.8
Jstick.ax2: JJ4.3, JU4.9
Jstick.pwr: JJ4.2, JQ4.3
Jstick_gate.control: JQ4.1, JU4.3
Jtrig.out: JU4.6, JU9.2
Jtrig.pwr: JC12.1, JQ5.3, JU9.1
Jtrig_gate.control: JQ5.1, JU4.12
Jusb.conn.cc.cc1: JJ2.A5, JR1.2
Jusb.conn.cc.cc2: JJ2.B5, JR2.2
Jusb_chain_0.d_N: JJ2.A7, JJ2.B7, JR8.1, JU5.1
Jusb_chain_0.d_P: JJ2.A6, JJ2.B6, JR7.1, JU5.2
Jv3v3: JC1.1, JC3.1, JC6.1, JC8.1, JC9.1, JC10.1, JD3.1, JJ3.1, JJ7.2, JQ4.2, JQ5.2, JR10.1, JR11.1, JTP3.1, JU1.4, JU2.2, JU4.14, JU6.5, JU6.8, JU6.12, JU7.2
Jvbat: JC5.1, JJ1.2, JQ1.2, JR4.1, JU3.3
Jvbat_gated: JC2.1, JJ7.7, JJ7.8, JR3.2, JU1.2, JU2.3
Jvbat_sense.i2c.scl: JJ7.3, JR10.2, JTP4.1, JU1.5, JU4.26, JU6.13, JU7.1
Jvbat_sense.i2c.sda: JJ7.4, JR11.2, JTP5.1, JU1.6, JU4.27, JU6.14, JU7.16
Jvbat_sense.sense_pwr_in: JQ1.3, JR3.1, JU1.1
Jvusb: JC4.1, JC7.1, JJ2.A4, JJ2.A9, JJ2.B4, JJ2.B9, JTP1.1, JU3.4, JU4.22

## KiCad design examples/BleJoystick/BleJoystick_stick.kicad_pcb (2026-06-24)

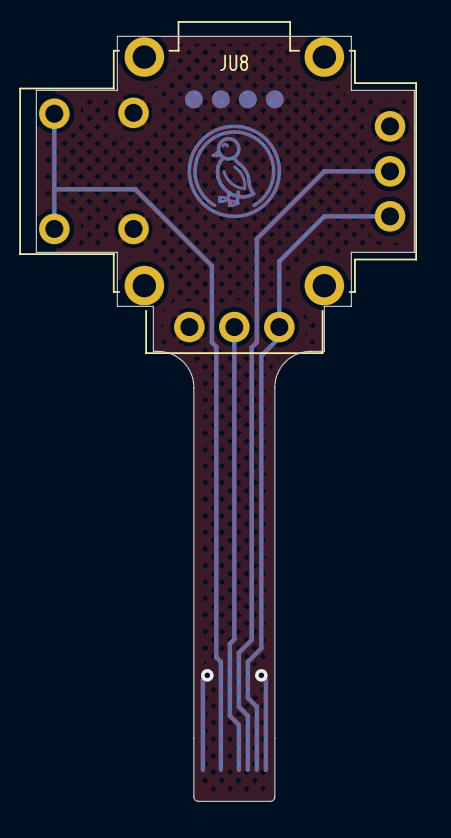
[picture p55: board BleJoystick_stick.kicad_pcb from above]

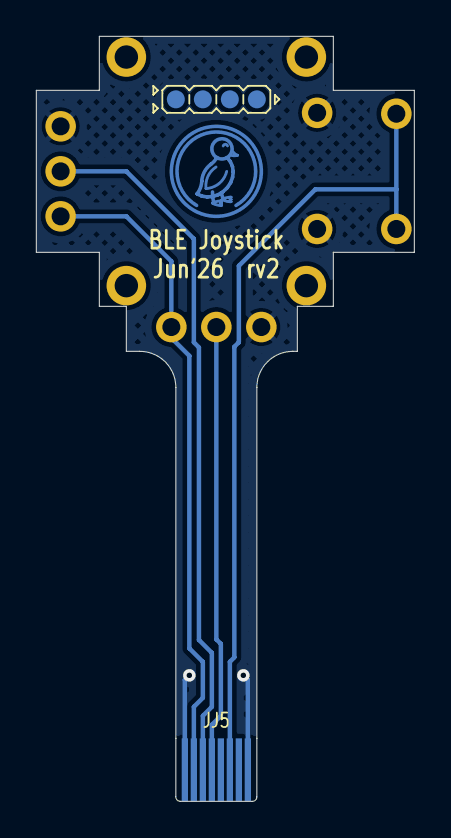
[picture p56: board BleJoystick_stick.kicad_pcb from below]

Board: 2 copper layers, 21.0 x 42.5 mm, 3 parts (2 on the bottom side), 5 nets.

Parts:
JJ5: stick.conn; FpcTab_1x08_P0.50mm
JU8: stick.stick; Joystick_XboxElite2
duck: G***; Symbol_Duckling

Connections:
Jstick_stick.ax1: JJ5.5, JU8.4
Jstick_stick.ax2: JJ5.6, JU8.7
Jstick_stick.gnd: JJ5.1, JJ5.8, JU8.2, JU8.3, JU8.8
Jstick_stick.pwr: JJ5.7, JU8.5, JU8.6
Jstick_stick.sw: JJ5.3, JU8.1

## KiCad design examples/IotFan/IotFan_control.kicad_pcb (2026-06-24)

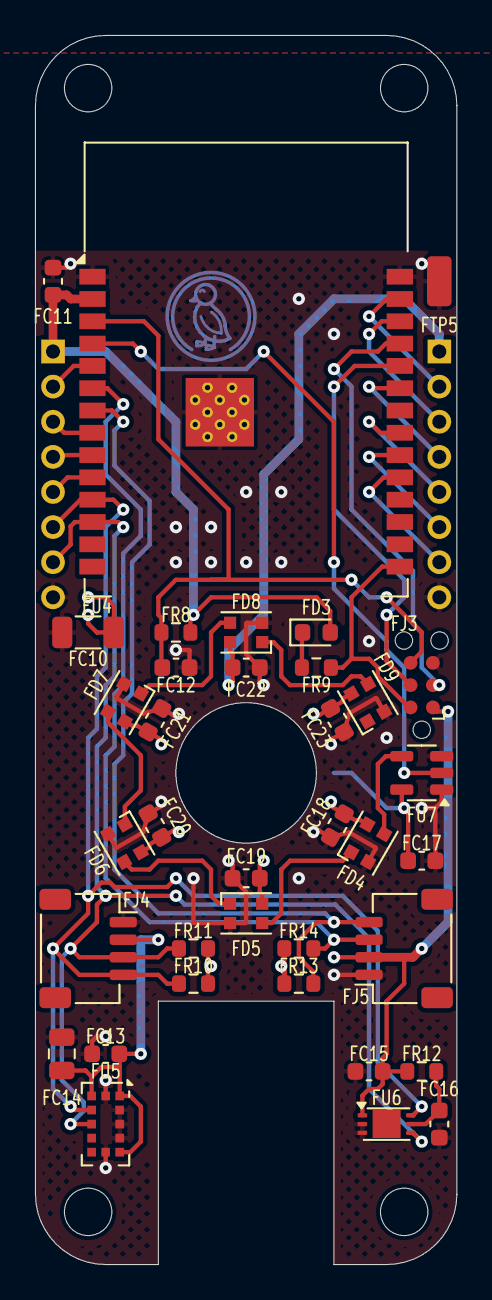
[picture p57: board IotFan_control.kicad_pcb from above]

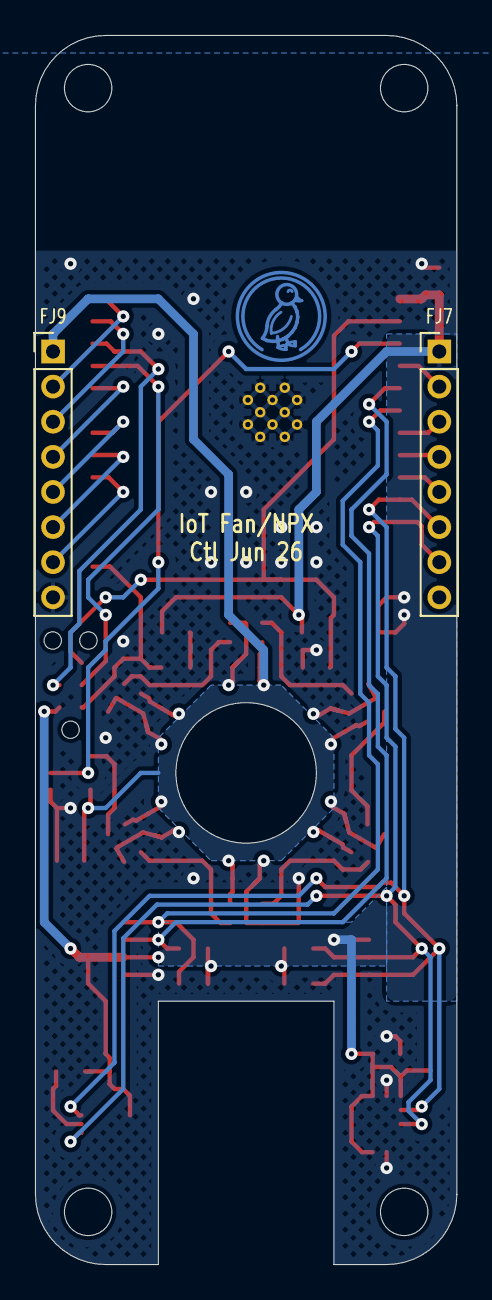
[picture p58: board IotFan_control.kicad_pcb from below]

Board: 2 copper layers, 24.0 x 70.0 mm, 43 parts (3 on the bottom side), 30 nets.

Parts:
FC10: control.mcu.vcc_cap0; C_1206_3216Metric
FC11: control.mcu.vcc_cap1; C_0603_1608Metric
FC12: control.mcu.en_pull.c; C_0603_1608Metric
FC13: control.dist.vdd_cap[0]; C_0603_1608Metric
FC14: control.dist.vdd_cap[1]; C_0805_2012Metric
FC15: control.als.vcc_cap; C_0603_1608Metric
FC16: control.als.dvi_pull.c; C_0603_1608Metric
FC17: control.npx_shift.vdd_cap; C_0603_1608Metric
FC18: control.npx.led[0].cap; C_0603_1608Metric
FC19: control.npx.led[1].cap; C_0603_1608Metric
FC20: control.npx.led[2].cap; C_0603_1608Metric
FC21: control.npx.led[3].cap; C_0603_1608Metric
FC22: control.npx.led[4].cap; C_0603_1608Metric
FC23: control.npx.led[5].cap; C_0603_1608Metric
FD3: control.ledr.package; LED_0603_1608Metric
FD4: control.npx.led[0].device; LED_WS2812B-2020_PLCC4_2.0x2.0mm
FD5: control.npx.led[1].device; LED_WS2812B-2020_PLCC4_2.0x2.0mm
FD6: control.npx.led[2].device; LED_WS2812B-2020_PLCC4_2.0x2.0mm
FD7: control.npx.led[3].device; LED_WS2812B-2020_PLCC4_2.0x2.0mm
FD8: control.npx.led[4].device; LED_WS2812B-2020_PLCC4_2.0x2.0mm
FD9: control.npx.led[5].device; LED_WS2812B-2020_PLCC4_2.0x2.0mm
FJ3: control.mcu.prog; Tag-Connect_TC2030-IDC-NL_2x03_P1.27mm_Vertical
FJ4: control.qwiic; JST_SH_SM04B-SRSS-TB_1x04-1MP_P1.00mm_Horizontal
FJ5: control.qwiic2; JST_SH_SM04B-SRSS-TB_1x04-1MP_P1.00mm_Horizontal
FJ7: control.conn1; PinHeader_1x08_P2.00mm_Vertical
FJ9: control.conn2; PinHeader_1x08_P2.00mm_Vertical
FR8: control.mcu.en_pull.r; R_0603_1608Metric
FR9: control.ledr.res; R_0603_1608Metric
FR10: control.i2c_pull.scl_res; R_0603_1608Metric
FR11: control.i2c_pull.sda_res; R_0603_1608Metric
FR12: control.als.dvi_pull.r; R_0603_1608Metric
FR13: control.i2c2_pull.scl_res; R_0603_1608Metric
FR14: control.i2c2_pull.sda_res; R_0603_1608Metric
FTP5: gnd; TestPoint_TE_RCT_0805
FU4: control.mcu.ic; ESP32-S3-WROOM-1
FU5: control.dist.ic; ST_VL53L0X
FU6: control.als.ic; HVSOF6
FU7: control.npx_shift.ic; SOT-23-5
H1, H2, H3, H4: MountingHole_2.7mm_M2.5_ISO14580
duck: G***; Symbol_Duckling

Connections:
Fcontrol_control.als.ic.dvi: FC16.1, FR12.2, FU6.5
Fcontrol_control.drv: FJ9.3, FU4.38
Fcontrol_control.enc_a: FJ9.5, FU4.33
Fcontrol_control.enc_b: FJ9.6, FU4.32
Fcontrol_control.enc_sw: FJ9.7, FU4.31
Fcontrol_control.extra1: FJ9.4, FU4.35
Fcontrol_control.gnd: FC10.2, FC11.2, FC12.2, FC13.2, FC14.2, FC15.2, FC16.2, FC17.2, FC18.2, FC19.2, FC20.2, FC21.2, FC22.2, FC23.2, FD4.2, FD5.2, FD6.2, FD7.2, FD8.2, FD9.2, FJ3.5, FJ4.1, FJ5.1, FJ7.8, FJ9.8, FTP5.1, FU4.1, FU4.40, FU4.41, FU5.2, FU5.3, FU5.4, FU5.6, FU5.12, FU6.2, FU6.3, FU7.1, FU7.3
Fcontrol_control.i2c2_pull.i2c.scl: FJ5.4, FR13.2, FU4.7
Fcontrol_control.i2c2_pull.i2c.sda: FJ5.3, FR14.2, FU4.6
Fcontrol_control.i2c.scl: FJ4.4, FJ7.6, FR10.2, FU4.11, FU5.10, FU6.6
Fcontrol_control.i2c.sda: FJ4.3, FJ7.7, FR11.2, FU4.12, FU5.9, FU6.4
Fcontrol_control.ledr.package.k: FD3.1, FR9.1
Fcontrol_control.mcu.program_boot_node: FJ3.2, FR9.2, FU4.27
Fcontrol_control.mcu.program_en_node: FC12.1, FJ3.6, FR8.2, FU4.3
Fcontrol_control.mcu.program_uart_node.a_tx: FJ3.4, FU4.36
Fcontrol_control.mcu.program_uart_node.b_tx: FJ3.3, FU4.37
Fcontrol_control.npx.led[0].dout: FD4.1, FD5.3
Fcontrol_control.npx.led[1].dout: FD5.1, FD6.3
Fcontrol_control.npx.led[2].dout: FD6.1, FD7.3
Fcontrol_control.npx.led[3].dout: FD7.1, FD8.3
Fcontrol_control.npx.led[4].dout: FD8.1, FD9.3
Fcontrol_control.npx_en: FJ7.2, FU4.5
Fcontrol_control.npx_shift.input: FU4.4, FU7.2
Fcontrol_control.npx_shift.output: FD4.3, FU7.4
Fcontrol_control.pd_int: FJ7.5, FU4.10
Fcontrol_control.pwm: FJ7.3, FU4.8
Fcontrol_control.spk: FJ7.4, FU4.9
Fcontrol_control.tach: FJ9.2, FU4.39
Fcontrol_control.v3v3: FC10.1, FC11.1, FC13.1, FC14.1, FC15.1, FD3.2, FJ3.1, FJ4.2, FJ5.2, FJ7.1, FR8.1, FR10.1, FR11.1, FR12.1, FR13.1, FR14.1, FU4.2, FU5.1, FU5.5, FU5.11, FU6.1
Fcontrol_control.v5: FC17.1, FC18.1, FC19.1, FC20.1, FC21.1, FC22.1, FC23.1, FD4.4, FD5.4, FD6.4, FD7.4, FD8.4, FD9.4, FJ9.1, FU7.5

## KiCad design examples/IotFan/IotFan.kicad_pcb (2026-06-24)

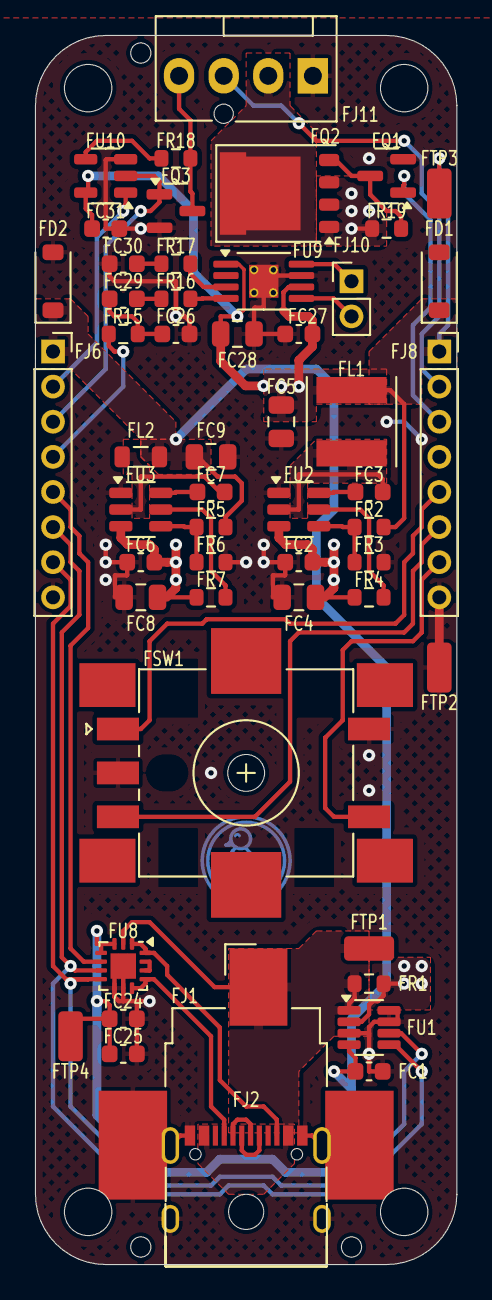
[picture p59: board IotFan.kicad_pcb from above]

Board: 2 copper layers, 24.0 x 70.0 mm, 61 parts (1 on the bottom side), 40 nets.

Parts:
FC1: vin_sense.vs_cap; C_0603_1608Metric
FC2: reg_5v.hf_in_cap; C_0603_1608Metric
FC3: reg_5v.boot_cap; C_0603_1608Metric
FC4: reg_5v.power_path.in_cap; C_0805_2012Metric
FC5: reg_5v.power_path.out_cap; C_0805_2012Metric
FC6: reg_3v3.hf_in_cap; C_0603_1608Metric
FC7: reg_3v3.boot_cap; C_0603_1608Metric
FC8: reg_3v3.power_path.in_cap; C_0805_2012Metric
FC9: reg_3v3.power_path.out_cap; C_0805_2012Metric
FC24: pd.vdd_cap[0]; C_0603_1608Metric
FC25: pd.vdd_cap[1]; C_0603_1608Metric
FC26: spk_dac.c; C_0603_1608Metric
FC27: spk_drv.pwr_cap; C_0603_1608Metric
FC28: spk_drv.bulk_cap; C_0805_2012Metric
FC29: spk_drv.inp_cap; C_0603_1608Metric
FC30: spk_drv.inn_cap; C_0603_1608Metric
FC31: npx_shift.vdd_cap; C_0603_1608Metric
FD1: prot_5v; D_SOD-123
FD2: prot_3v3; D_SOD-123
FH1: jlc_th.th1; JlcToolingHole_1.152mm
FH2: jlc_th.th2; JlcToolingHole_1.152mm
FH3: jlc_th.th3; JlcToolingHole_1.152mm
FJ1: pwr; BarrelJack_CUI_PJ-036AH-SMT_Horizontal
FJ2: usb; USB_C_Receptacle_XKB_U262-16XN-4BVC11
FJ6: control.conn1; PinSocket_1x08_P2.00mm_Vertical
FJ8: control.conn2; PinSocket_1x08_P2.00mm_Vertical
FJ10: spk; PinHeader_1x02_P2.00mm_Vertical
FJ11: fan; FanPinHeader_1x04_P2.54mm_Vertical
FL1: reg_5v.power_path.inductor; L_Taiyo-Yuden_NR-50xx
FL2: reg_3v3.power_path.inductor; L_0805_2012Metric
FQ1: fan_drv.pre; SOT-23
FQ2: fan_drv.drv; PQFN-8-EP_6x5mm_P1.27mm_Generic
FQ3: fan_ctl; SOT-23
FR1: vin_sense.Rs; R_0603_1608Metric
FR2: reg_5v.fb.top_res; R_0603_1608Metric
FR3: reg_5v.fb.bottom_res; R_0603_1608Metric
FR4: reg_5v.en_res; R_0603_1608Metric
FR5: reg_3v3.fb.top_res; R_0603_1608Metric
FR6: reg_3v3.fb.bottom_res; R_0603_1608Metric
FR7: reg_3v3.en_res; R_0603_1608Metric
FR15: spk_dac.r; R_0603_1608Metric
FR16: spk_drv.inp_res; R_0603_1608Metric
FR17: spk_drv.inn_res; R_0603_1608Metric
FR18: npx_res; R_0603_1608Metric
FR19: fan_drv.pull; R_0603_1608Metric
FSW1: enc; RotaryEncoder_Alps_EC11J15-Switch
FTP1: _pwr_merge_pwr_out_link; TestPoint_TE_RCT_0805
FTP2: gnd; TestPoint_TE_RCT_0805
FTP3: v5; TestPoint_TE_RCT_0805
FTP4: v3v3; TestPoint_TE_RCT_0805
FU1: vin_sense.ic; SOT-23-8
FU2: reg_5v.ic; SOT-23-6
FU3: reg_3v3.ic; SOT-23-6
FU8: pd.ic; WQFN-14-1EP_2.5x2.5mm_P0.5mm_EP1.45x1.45mm
FU9: spk_drv.ic; MSOP-8-1EP_3x3mm_P0.65mm_EP1.68x1.88mm_ThermalVias
FU10: npx_shift.ic; SOT-23-5
H1, H2, H3, H4: MountingHole_2.7mm_M2.5_ISO14580
UU4: Duck; Symbol_Duckling

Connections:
Fcontrol.drv: FJ8.3, FQ1.1
Fcontrol.enc_a: FJ8.5, FSW1.A
Fcontrol.enc_b: FJ8.6, FSW1.B
Fcontrol.enc_sw: FJ8.7, FSW1.S1
Fcontrol.npx_en: FJ6.2, FU10.1
Fcontrol.pd_int: FJ6.5, FU8.5
Fcontrol.pwm: FJ6.3, FQ3.1, FU10.2
Fcontrol.spk: FJ6.4, FR15.1
Fcontrol.tach: FJ8.2, FJ11.3
Ffan.pwr: FJ11.2, FQ2.5
Ffan_drv.pre.drain: FQ1.3, FQ2.4, FR19.2
Fgnd: FC1.2, FC2.2, FC4.2, FC5.2, FC6.2, FC8.2, FC9.2, FC24.2, FC25.2, FC26.2, FC27.2, FC28.2, FC30.2, FC31.2, FD1.2, FD2.2, FJ1.2, FJ2.A1, FJ2.A12, FJ2.B1, FJ2.B12, FJ2.S1, FJ6.8, FJ8.8, FJ11.1, FQ1.2, FQ3.2, FR3.2, FR6.2, FSW1.C, FSW1.S2, FTP2.1, FU1.3, FU1.7, FU1.8, FU2.1, FU3.1, FU8.8, FU8.9, FU8.15, FU9.7, FU9.9, FU10.3
Fnpx_res.output: FJ11.4, FQ3.3, FR18.2
Fnpx_shift.output: FR18.1, FU10.4
Fpd.ic.vconn: FU8.12, FU8.13
Fpwr.pwr: FJ1.1, FJ2.A4, FJ2.A9, FJ2.B4, FJ2.B9, FR1.1, FTP1.1, FU1.1, FU8.2
Freg_3v3.ic.boot: FC7.1, FU3.6
Freg_3v3.ic.en: FR7.2, FU3.5
Freg_3v3.ic.fb: FR5.2, FR6.1, FU3.4
Freg_3v3.ic.sw: FC7.2, FL2.1, FU3.2
Freg_5v.ic.boot: FC3.1, FU2.6
Freg_5v.ic.en: FR4.2, FU2.5
Freg_5v.ic.fb: FR2.2, FR3.1, FU2.4
Freg_5v.ic.sw: FC3.2, FL1.1, FU2.2
Fspk_dac.output: FC26.1, FC29.2, FR15.2
Fspk_drv.ic.inn: FR17.2, FU9.3
Fspk_drv.ic.inp: FR16.2, FU9.4
Fspk_drv.inn_res.input: FC30.1, FR17.1
Fspk_drv.inp_res.input: FC29.1, FR16.1
Fspk_drv.spk.a: FJ10.1, FU9.8
Fspk_drv.spk.b: FJ10.2, FU9.5
Fusb.cc.cc1: FJ2.A5, FU8.10, FU8.11
Fusb.cc.cc2: FJ2.B5, FU8.1, FU8.14
Fusb.usb.dm: FJ2.A7, FJ2.B7
Fusb.usb.dp: FJ2.A6, FJ2.B6
Fv3v3: FC1.1, FC9.1, FC24.1, FC25.1, FD2.1, FJ6.1, FL2.2, FR5.1, FTP4.1, FU1.4, FU8.3, FU8.4
Fv5: FC5.1, FC6.1, FC8.1, FC27.1, FC28.1, FC31.1, FD1.1, FJ8.1, FL1.2, FR2.1, FR7.1, FTP3.1, FU3.3, FU9.1, FU9.6, FU10.5
Fvin: FC2.1, FC4.1, FQ2.1, FQ2.2, FQ2.3, FR1.2, FR4.1, FR19.1, FU1.2, FU2.3
Fvin_sense.i2c.scl: FJ6.6, FU1.5, FU8.6
Fvin_sense.i2c.sda: FJ6.7, FU1.6, FU8.7

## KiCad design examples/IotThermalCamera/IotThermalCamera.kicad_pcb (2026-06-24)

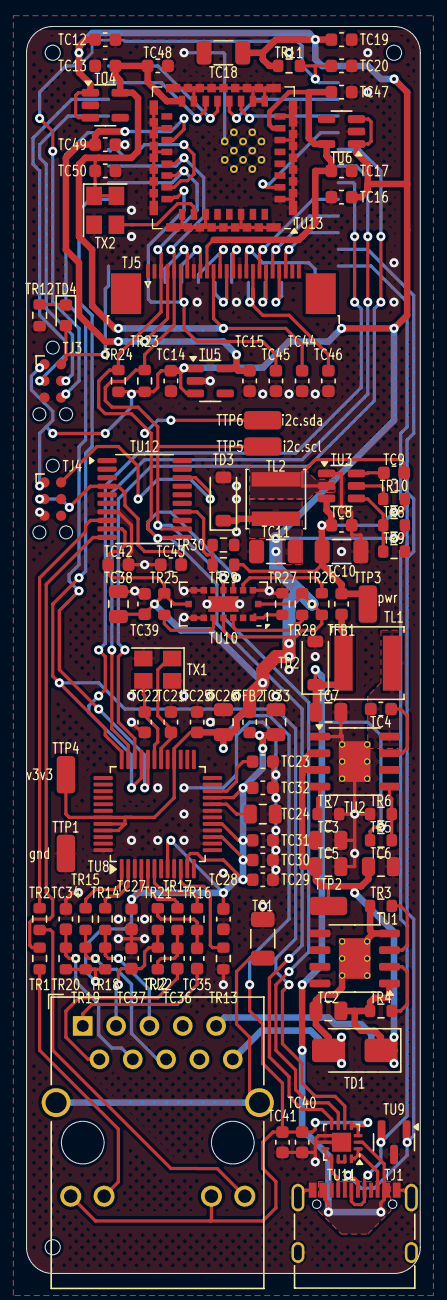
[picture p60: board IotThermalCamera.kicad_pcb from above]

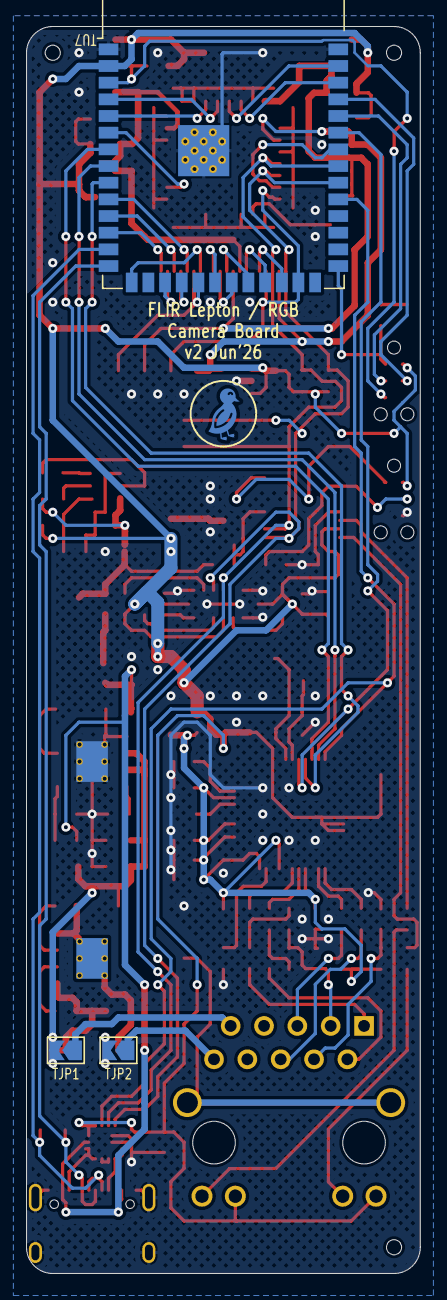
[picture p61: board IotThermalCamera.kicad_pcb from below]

Board: 2 copper layers, 30.0 x 95.0 mm, 120 parts (4 on the bottom side), 88 nets.

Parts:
TC1: eth.cap; C_1206_3216Metric
TC2: poe.vdd_cap; C_0805_2012Metric
TC3: reg_poe.hf_cap; C_0805_2012Metric
TC4: reg_poe.boot_cap; C_0603_1608Metric
TC5: reg_poe.power_path.in_cap.c[0]; C_0805_2012Metric
TC6: reg_poe.power_path.in_cap.c[1]; C_0805_2012Metric
TC7: reg_poe.power_path.out_cap; C_0805_2012Metric
TC8: reg_3v3.hf_in_cap; C_0603_1608Metric
TC9: reg_3v3.boot_cap; C_0603_1608Metric
TC10: reg_3v3.power_path.in_cap; C_1206_3216Metric
TC11: reg_3v3.power_path.out_cap; C_1206_3216Metric
TC12: reg_3v0.in_cap; C_0603_1608Metric
TC13: reg_3v0.out_cap; C_0603_1608Metric
TC14: reg_2v8.in_cap; C_0603_1608Metric
TC15: reg_2v8.out_cap; C_0603_1608Metric
TC16: reg_1v2.in_cap; C_0603_1608Metric
TC17: reg_1v2.out_cap; C_0603_1608Metric
TC18: mcu.vcc_cap0; C_1206_3216Metric
TC19: mcu.vcc_cap1; C_0603_1608Metric
TC20: mcu.en_pull.c; C_0603_1608Metric
TC21: phy.crystal.cap_a; C_0603_1608Metric
TC22: phy.crystal.cap_b; C_0603_1608Metric
TC23: phy.c1v20; C_0603_1608Metric
TC24: phy.tocap; C_0805_2012Metric
TC25: phy.vdd_cap0; C_0603_1608Metric
TC26: phy.vdd_cap1; C_0805_2012Metric
TC27: phy.avdd_caps[0]; C_0603_1608Metric
TC28: phy.avdd_caps[1]; C_0603_1608Metric
TC29: phy.avdd_caps[2]; C_0603_1608Metric
TC30: phy.avdd_caps[3]; C_0603_1608Metric
TC31: phy.avdd_caps[4]; C_0603_1608Metric
TC32: phy.avdd_caps[5]; C_0603_1608Metric
TC33: phy.avdd_caps[6]; C_0805_2012Metric
TC34: phy.txc_cap; C_0603_1608Metric
TC35: phy.rxp_ac; C_0603_1608Metric
TC36: phy.rxn_ac; C_0603_1608Metric
TC37: phy.rxc_cap; C_0603_1608Metric
TC38: dist.avdd_cap; C_0805_2012Metric
TC39: dist.iovdd_cap; C_0603_1608Metric
TC40: pd.vdd_cap[0]; C_0603_1608Metric
TC41: pd.vdd_cap[1]; C_0603_1608Metric
TC42: ioe.vdd_cap; C_0603_1608Metric
TC43: ioe.reset_cap; C_0603_1608Metric
TC44: cam.dovdd_cap; C_0603_1608Metric
TC45: cam.reset_cap; C_0603_1608Metric
TC46: cam.pclk_cap; C_0603_1608Metric
TC47: flir.vddc_cap; C_0603_1608Metric
TC48: flir.vddio_cap; C_0603_1608Metric
TC49: flir.vdd_cap; C_0603_1608Metric
TC50: flir.mclk.cap; C_0603_1608Metric
TD1: poe.prot; D_SMA
TD2: prot_v5; D_SOD-123
TD3: prot_3v3; D_SOD-123
TD4: ledr.package; LED_0603_1608Metric
TFB1: choke; L_0603_1608Metric
TFB2: phy.l; L_0603_1608Metric
TH1: jlc_th.th1; JlcToolingHole_1.152mm
TH2: jlc_th.th2; JlcToolingHole_1.152mm
TH3: jlc_th.th3; JlcToolingHole_1.152mm
TJ1: usb; USB_C_Receptacle_XKB_U262-16XN-4BVC11
TJ2: eth.conn; RJ45_Wuerth_7499111446_Horizontal
TJ3: mcu.prog; Tag-Connect_TC2030-IDC-NL_2x03_P1.27mm_Vertical
TJ4: ioe.sdi; Tag-Connect_TC2030-IDC-NL_2x03_P1.27mm_Vertical
TJ5: cam.device; TE_2-1734839-4_1x24-1MP_P0.5mm_Horizontal
TJP1: poe_jmp.pos; SolderJumper-2_P1.3mm_Open_TrianglePad1.0x1.5mm
TJP2: poe_jmp.neg; SolderJumper-2_P1.3mm_Open_TrianglePad1.0x1.5mm
TL1: reg_poe.power_path.inductor; L_Sunlord_SWPA5040S
TL2: reg_3v3.power_path.inductor; L_Sunlord_SWPA4030S
TR1: eth.led_yel_res; R_0603_1608Metric
TR2: eth.led_grn_res; R_0603_1608Metric
TR3: poe.cls; R_0603_1608Metric
TR4: poe.den; R_0603_1608Metric
TR5: reg_poe.fb.top_res; R_0603_1608Metric
TR6: reg_poe.fb.bottom_res; R_0603_1608Metric
TR7: reg_poe.rt; R_0603_1608Metric
TR8: reg_3v3.fb.top_res; R_0603_1608Metric
TR9: reg_3v3.fb.bottom_res; R_0603_1608Metric
TR10: reg_3v3.en_res; R_0603_1608Metric
TR11: mcu.en_pull.r; R_0603_1608Metric
TR12: ledr.res; R_0603_1608Metric
TR13: phy.exres1; R_0603_1608Metric
TR14: phy.txp_damp; R_0603_1608Metric
TR15: phy.txn_damp; R_0603_1608Metric
TR16: phy.rxp_damp; R_0603_1608Metric
TR17: phy.rxn_damp; R_0603_1608Metric
TR18: phy.txp_bias; R_0603_1608Metric
TR19: phy.txn_bias; R_0603_1608Metric
TR20: phy.txc_bias; R_0603_1608Metric
TR21: phy.rxp_bias; R_0603_1608Metric
TR22: phy.rxn_bias; R_0603_1608Metric
TR23: i2c_pull.scl_res; R_0603_1608Metric
TR24: i2c_pull.sda_res; R_0603_1608Metric
TR25: dist.lpn_pull; R_0603_1608Metric
TR26: dist.rsvd6_pull; R_0603_1608Metric
TR27: dist.i2c_rst_pull; R_0603_1608Metric
TR28: dist.int_pull; R_0603_1608Metric
TR29: poe_sense.top_res; R_0603_1608Metric
TR30: poe_sense.bottom_res; R_0603_1608Metric
TTP1: gnd; TestPoint_TE_RCT_0805
TTP2: _poe_pwr_out_link; TestPoint_TE_RCT_0805
TTP3: pwr; TestPoint_TE_RCT_0805
TTP4: v3v3; TestPoint_TE_RCT_0805
TTP5: i2c.scl; TestPoint_TE_RCT_0805
TTP6: i2c.sda; TestPoint_TE_RCT_0805
TU1: poe.ic; HSOP-8-1EP_3.9x4.9mm_P1.27mm_EP2.41x3.1mm_ThermalVias
TU2: reg_poe.ic; HSOP-8-1EP_3.9x4.9mm_P1.27mm_EP2.41x3.1mm_ThermalVias
TU3: reg_3v3.ic; SOT-23-6
TU4: reg_3v0.ic; SOT-23-5
TU5: reg_2v8.ic; SOT-23-5
TU6: reg_1v2.ic; SOT-23-5
TU7: Symbol_DucklingSolid
TU7#2: mcu.ic; ESP32-S3-WROOM-1
TU8: phy.ic; LQFP-48_7x7mm_P0.5mm
TU9: usb_esd; SOT-23
TU10: dist.ic; ST_VL53L5x
TU11: pd.ic; WQFN-14-1EP_2.5x2.5mm_P0.5mm_EP1.45x1.45mm
TU12: ioe.ic; TSSOP-20_4.4x6.5mm_P0.65mm
TU13: flir.ic; Molex_1050281001
TX1: phy.crystal.package; Crystal_SMD_3225-4Pin_3.2x2.5mm
TX2: flir.mclk.device; Crystal_SMD_3225-4Pin_3.2x2.5mm

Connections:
Tcam.dvp8.href: TJ5.9, TU7#2.23
Tcam.dvp8.pclk: TC46.1, TJ5.17, TU7#2.19
Tcam.dvp8.vsync: TJ5.7, TU7#2.24
Tcam.dvp8.xclk: TJ5.13, TU7#2.21
Tcam.dvp8.y0: TJ5.19, TU7#2.18
Tcam.dvp8.y1: TJ5.21, TU7#2.17
Tcam.dvp8.y2: TJ5.22, TU7#2.12
Tcam.dvp8.y3: TJ5.20, TU7#2.11
Tcam.dvp8.y4: TJ5.18, TU7#2.10
Tcam.dvp8.y5: TJ5.16, TU7#2.15
Tcam.dvp8.y6: TJ5.14, TU7#2.20
Tcam.dvp8.y7: TJ5.12, TU7#2.22
Tcam.reset: TC45.1, TJ5.6, TU7#2.25, TU13.24
Tdist.ic.i2c_rst: TR27.2, TU10.A1
Tdist.ic.int: TR28.2, TU10.A3
Tdist.ic.lpn: TR25.2, TU10.A5
Tdist.ic.rsvd6: TR26.2, TU10.C2
Teth.conn.led_grn_cathode: TJ2.14, TR2.1
Teth.conn.led_yel_cathode: TJ2.12, TR1.1
Teth.conn.shield: TC1.1, TJ2.SH
Teth.eth.rx.center: TC37.1, TJ2.3, TR21.2, TR22.2
Teth.eth.rx.neg: TC36.1, TJ2.2
Teth.eth.rx.pos: TC35.1, TJ2.1
Teth.eth.tx.center: TC34.1, TJ2.4, TR20.2
Teth.eth.tx.neg: TJ2.6, TR15.2, TR19.2
Teth.eth.tx.pos: TJ2.5, TR14.2, TR18.2
Teth.led_grn_sink: TR2.2, TU12.8
Teth.led_yel_sink: TR1.2, TU12.10
Teth.poe.neg: TJ2.10, TJP2.1
Teth.poe.pos: TJ2.9, TJP1.1
Tflir.cs: TU7#2.38, TU13.14
Tflir.ic.master_clk: TU13.26, TX2.3
Tflir.shutdown: TU7#2.34, TU13.23
Tflir.spi.miso: TU7#2.4, TU13.12
Tflir.spi.mosi: TU7#2.5, TU13.11
Tflir.spi.sck: TU7#2.39, TU13.13
Tflir.vsync: TU7#2.6, TU13.2
Tgnd: TC1.2, TC3.2, TC5.2, TC6.2, TC7.2, TC8.2, TC10.2, TC11.2, TC12.2, TC13.2, TC14.2, TC15.2, TC16.2, TC17.2, TC18.2, TC19.2, TC20.2, TC21.2, TC22.2, TC23.2, TC24.2, TC25.2, TC26.2, TC27.2, TC28.2, TC29.2, TC30.2, TC31.2, TC32.2, TC33.2, TC34.2, TC37.2, TC38.2, TC39.2, TC40.2, TC41.2, TC42.2, TC43.2, TC44.2, TC45.2, TC46.2, TC47.2, TC48.2, TC49.2, TC50.2, TD2.2, TD3.2, TJ1.A1, TJ1.A12, TJ1.B1, TJ1.B12, TJ1.S1, TJ3.5, TJ4.5, TJ5.2, TJ5.8, TJ5.15, TR6.2, TR7.1, TR9.2, TR12.2, TR13.1, TR27.1, TR30.2, TTP1.1, TU1.5, TU1.8, TU2.1, TU2.9, TU3.1, TU4.2, TU5.2, TU6.2, TU7#2.1, TU7#2.40, TU7#2.41, TU8.3, TU8.9, TU8.14, TU8.16, TU8.19, TU8.23, TU8.29, TU8.48, TU9.3, TU10.A2, TU10.A6, TU10.A7, TU10.B4, TU10.C1, TU10.C6, TU10.C7, TU11.8, TU11.9, TU11.15, TU12.7, TU13.1, TU13.6, TU13.8, TU13.9, TU13.10, TU13.15, TU13.18, TU13.20, TU13.25, TU13.27, TU13.30, TU13.33, TX1.2, TX1.4, TX2.2
Ti2c_chain_0.scl: TJ5.5, TR23.2, TTP5.1, TU7#2.33, TU10.C4, TU11.6, TU12.12, TU13.21
Ti2c_chain_0.sda: TJ5.3, TR24.2, TTP6.1, TU7#2.32, TU10.C3, TU11.7, TU12.11, TU13.22
Tioe.ic.nrst: TC43.1, TJ4.3, TU12.4
Tioe.ic.swio: TJ4.2, TU12.18
Tledr.package.k: TD4.1, TR12.1
Tmcu.program_boot_node: TD4.2, TJ3.2, TU7#2.27
Tmcu.program_en_node: TC20.1, TJ3.6, TR11.2, TU7#2.3
Tmcu.program_uart_node.a_tx: TJ3.4, TU7#2.36
Tmcu.program_uart_node.b_tx: TJ3.3, TU7#2.37
Tpd.ic.vconn: TU11.12, TU11.13
Tphy.cs: TU7#2.35, TU8.32
Tphy.ic.avdd: TC27.1, TC28.1, TC29.1, TC30.1, TC31.1, TC32.1, TC33.1, TFB2.2, TR18.1, TR19.1, TR20.1, TU8.4, TU8.8, TU8.11, TU8.15, TU8.17, TU8.21
Tphy.ic.crystal.xtal_in: TC21.1, TU8.30, TX1.1
Tphy.ic.crystal.xtal_out: TC22.1, TU8.31, TX1.3
Tphy.ic.exres1: TR13.2, TU8.10
Tphy.ic.rxn: TR17.1, TU8.5
Tphy.ic.rxp: TR16.1, TU8.6
Tphy.ic.tocap: TC24.1, TU8.20
Tphy.ic.txn: TR15.1, TU8.1
Tphy.ic.txp: TR14.1, TU8.2
Tphy.ic.v1v20: TC23.1, TU8.22
Tphy.int: TU7#2.31, TU8.36, TU11.5
Tphy.rxn_damp.b: TC36.2, TR17.2, TR22.1
Tphy.rxp_damp.b: TC35.2, TR16.2, TR21.1
Tphy.spi.miso: TU7#2.7, TU8.34
Tphy.spi.mosi: TU7#2.8, TU8.35
Tphy.spi.sck: TU7#2.9, TU8.33
Tpoe.ic.cls: TR3.2, TU1.3
Tpoe.ic.den: TR4.2, TU1.2
Tpoe.poe.neg: TC2.2, TD1.2, TJP2.2, TR3.1, TU1.4, TU1.9
Tpoe.pwr_out: TC2.1, TC3.1, TC5.1, TC6.1, TD1.1, TJP1.2, TR4.1, TTP2.1, TU1.1, TU2.2, TU2.3
Tpoe_sense.output: TR29.2, TR30.1, TU12.14
Tpwr: TC8.1, TC10.1, TFB1.2, TR10.1, TR29.1, TTP3.1, TU3.3
Treg_3v3.ic.boot: TC9.1, TU3.6
Treg_3v3.ic.en: TR10.2, TU3.5
Treg_3v3.ic.fb: TR8.2, TR9.1, TU3.4
Treg_3v3.ic.sw: TC9.2, TL2.1, TU3.2
Treg_poe.ic.boot: TC4.1, TU2.7
Treg_poe.ic.fb: TR5.2, TR6.1, TU2.5
Treg_poe.ic.rt: TR7.2, TU2.4
Treg_poe.ic.sw: TC4.2, TL1.1, TU2.8
Tusb.cc.cc1: TJ1.A5, TU11.10, TU11.11
Tusb.cc.cc2: TJ1.B5, TU11.1, TU11.14
Tusb.pwr: TC7.1, TD2.1, TFB1.1, TJ1.A4, TJ1.A9, TJ1.B4, TJ1.B9, TL1.2, TR5.1, TU11.2
Tusb_chain_0.d_N: TJ1.A7, TJ1.B7, TU7#2.13, TU9.1
Tusb_chain_0.d_P: TJ1.A6, TJ1.B6, TU7#2.14, TU9.2
Tv1v2: TC17.1, TC47.1, TJ5.10, TU6.5, TU13.7
Tv2v8: TC15.1, TC49.1, TJ5.4, TU5.5, TU13.19
Tv3v0: TC13.1, TC44.1, TC48.1, TC50.1, TJ5.11, TU4.5, TU13.16, TX2.1, TX2.4
Tv3v3: TC11.1, TC12.1, TC14.1, TC16.1, TC18.1, TC19.1, TC25.1, TC26.1, TC38.1, TC39.1, TC40.1, TC41.1, TC42.1, TD3.1, TFB2.1, TJ2.11, TJ2.13, TJ3.1, TJ4.1, TL2.2, TR8.1, TR11.1, TR23.1, TR24.1, TR25.1, TR26.1, TR28.1, TTP4.1, TU4.1, TU4.3, TU5.1, TU5.3, TU6.1, TU6.3, TU7#2.2, TU8.28, TU8.43, TU8.44, TU8.45, TU10.A4, TU10.B1, TU10.B7, TU11.3, TU11.4, TU12.9

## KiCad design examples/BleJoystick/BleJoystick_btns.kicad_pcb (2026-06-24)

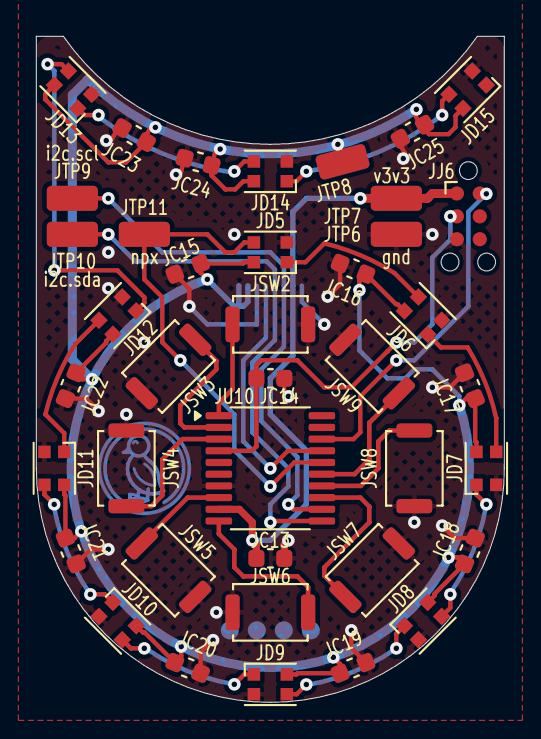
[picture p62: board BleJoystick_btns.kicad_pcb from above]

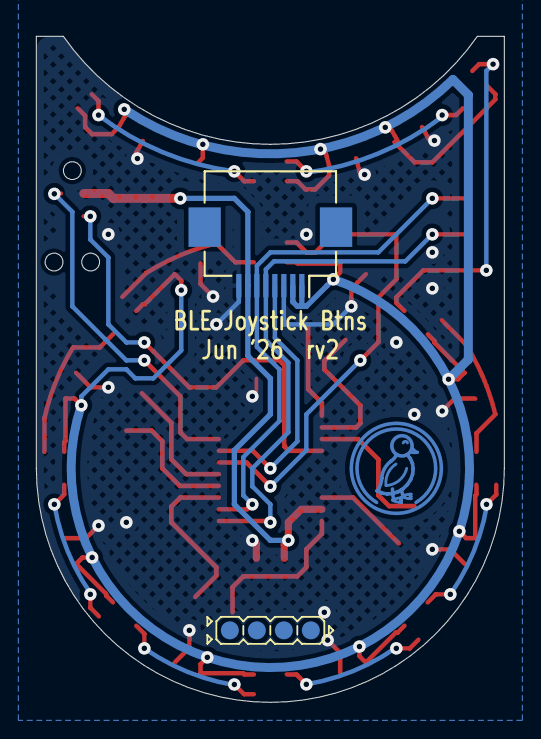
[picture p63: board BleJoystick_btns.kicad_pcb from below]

Board: 2 copper layers, 26.0 x 37.0 mm, 42 parts (2 on the bottom side), 27 nets.

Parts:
JC13: btns.ioe.vdd_cap; C_0603_1608Metric
JC14: btns.ioe.reset_cap; C_0603_1608Metric
JC15: btns.npx_dpad.led[0].cap; C_0603_1608Metric
JC16: btns.npx_dpad.led[1].cap; C_0603_1608Metric
JC17: btns.npx_dpad.led[2].cap; C_0603_1608Metric
JC18: btns.npx_dpad.led[3].cap; C_0603_1608Metric
JC19: btns.npx_dpad.led[4].cap; C_0603_1608Metric
JC20: btns.npx_dpad.led[5].cap; C_0603_1608Metric
JC21: btns.npx_dpad.led[6].cap; C_0603_1608Metric
JC22: btns.npx_dpad.led[7].cap; C_0603_1608Metric
JC23: btns.npx_js.led[0].cap; C_0603_1608Metric
JC24: btns.npx_js.led[1].cap; C_0603_1608Metric
JC25: btns.npx_js.led[2].cap; C_0603_1608Metric
JD5: btns.npx_dpad.led[0].device; LED_WS2812B-2020_PLCC4_2.0x2.0mm
JD6: btns.npx_dpad.led[1].device; LED_WS2812B-2020_PLCC4_2.0x2.0mm
JD7: btns.npx_dpad.led[2].device; LED_WS2812B-2020_PLCC4_2.0x2.0mm
JD8: btns.npx_dpad.led[3].device; LED_WS2812B-2020_PLCC4_2.0x2.0mm
JD9: btns.npx_dpad.led[4].device; LED_WS2812B-2020_PLCC4_2.0x2.0mm
JD10: btns.npx_dpad.led[5].device; LED_WS2812B-2020_PLCC4_2.0x2.0mm
JD11: btns.npx_dpad.led[6].device; LED_WS2812B-2020_PLCC4_2.0x2.0mm
JD12: btns.npx_dpad.led[7].device; LED_WS2812B-2020_PLCC4_2.0x2.0mm
JD13: btns.npx_js.led[0].device; LED_WS2812B-2020_PLCC4_2.0x2.0mm
JD14: btns.npx_js.led[1].device; LED_WS2812B-2020_PLCC4_2.0x2.0mm
JD15: btns.npx_js.led[2].device; LED_WS2812B-2020_PLCC4_2.0x2.0mm
JJ6: btns.ioe.sdi; Tag-Connect_TC2030-IDC-NL_2x03_P1.27mm_Vertical
JJ8: btns.conn; Hirose_FH12-8S-0.5SH_1x08-1MP_P0.50mm_Horizontal
JSW2: btns.sw[0]; SW_Push_SPST_NO_Alps_SKRK
JSW3: btns.sw[1]; SW_Push_SPST_NO_Alps_SKRK
JSW4: btns.sw[2]; SW_Push_SPST_NO_Alps_SKRK
JSW5: btns.sw[3]; SW_Push_SPST_NO_Alps_SKRK
JSW6: btns.sw[4]; SW_Push_SPST_NO_Alps_SKRK
JSW7: btns.sw[5]; SW_Push_SPST_NO_Alps_SKRK
JSW8: btns.sw[6]; SW_Push_SPST_NO_Alps_SKRK
JSW9: btns.sw[7]; SW_Push_SPST_NO_Alps_SKRK
JTP6: gnd; TestPoint_TE_RCT_0805
JTP7: v3v3; TestPoint_TE_RCT_0805
JTP8: vbat; TestPoint_TE_RCT_0805
JTP9: i2c.scl; TestPoint_TE_RCT_0805
JTP10: i2c.sda; TestPoint_TE_RCT_0805
JTP11: npx; TestPoint_TE_RCT_0805
JU10: btns.ioe.ic; TSSOP-20_4.4x6.5mm_P0.65mm
duck: G***; Symbol_Duckling

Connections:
Jbtns_btns.gnd: JC13.2, JC14.2, JC15.2, JC16.2, JC17.2, JC18.2, JC19.2, JC20.2, JC21.2, JC22.2, JC23.2, JC24.2, JC25.2, JD5.2, JD6.2, JD7.2, JD8.2, JD9.2, JD10.2, JD11.2, JD12.2, JD13.2, JD14.2, JD15.2, JJ6.5, JJ8.3, JJ8.8, JSW2.2, JSW3.2, JSW4.2, JSW5.2, JSW6.2, JSW7.2, JSW8.2, JSW9.2, JTP6.1, JU10.7
Jbtns_btns.i2c.scl: JJ8.6, JTP9.1, JU10.12
Jbtns_btns.i2c.sda: JJ8.5, JTP10.1, JU10.11
Jbtns_btns.io0: JJ8.4, JU10.17
Jbtns_btns.ioe.ic.nrst: JC14.1, JJ6.3, JU10.4
Jbtns_btns.ioe.ic.swio: JJ6.2, JU10.18
Jbtns_btns.npx_dpad.dout: JD12.1, JD13.3
Jbtns_btns.npx_dpad.led[0].dout: JD5.1, JD6.3
Jbtns_btns.npx_dpad.led[1].dout: JD6.1, JD7.3
Jbtns_btns.npx_dpad.led[2].dout: JD7.1, JD8.3
Jbtns_btns.npx_dpad.led[3].dout: JD8.1, JD9.3
Jbtns_btns.npx_dpad.led[4].dout: JD9.1, JD10.3
Jbtns_btns.npx_dpad.led[5].dout: JD10.1, JD11.3
Jbtns_btns.npx_dpad.led[6].dout: JD11.1, JD12.3
Jbtns_btns.npx_js.led[0].dout: JD13.1, JD14.3
Jbtns_btns.npx_js.led[1].dout: JD14.1, JD15.3
Jbtns_btns.npx_tp.io: JD5.3, JTP11.1, JU10.16
Jbtns_btns.pwr: JC13.1, JJ6.1, JJ8.7, JTP7.1, JU10.9
Jbtns_btns.sw[0].out: JSW2.1, JU10.1
Jbtns_btns.sw[1].out: JSW3.1, JU10.2
Jbtns_btns.sw[2].out: JSW4.1, JU10.3
Jbtns_btns.sw[3].out: JSW5.1, JU10.8
Jbtns_btns.sw[4].out: JSW6.1, JU10.10
Jbtns_btns.sw[5].out: JSW7.1, JU10.13
Jbtns_btns.sw[6].out: JSW8.1, JU10.14
Jbtns_btns.sw[7].out: JSW9.1, JU10.15
Jbtns_btns.vbat: JC15.1, JC16.1, JC17.1, JC18.1, JC19.1, JC20.1, JC21.1, JC22.1, JC23.1, JC24.1, JC25.1, JD5.4, JD6.4, JD7.4, JD8.4, JD9.4, JD10.4, JD11.4, JD12.4, JD13.4, JD14.4, JD15.4, JJ8.1, JJ8.2, JTP8.1

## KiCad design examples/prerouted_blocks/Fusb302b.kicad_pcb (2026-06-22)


Board: 2 copper layers, 3 parts (0 on the bottom side), 5 nets.

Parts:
TC40: pd.vdd_cap[0]; C_0603_1608Metric
TC41: pd.vdd_cap[1]; C_0603_1608Metric
TU11: pd.ic; WQFN-14-1EP_2.5x2.5mm_P0.5mm_EP1.45x1.45mm

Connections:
Tgnd: TC40.2, TC41.2, TU11.8, TU11.9, TU11.15
Tpd.ic.vconn: TU11.12, TU11.13
Tusb.cc.cc1: TU11.10, TU11.11
Tusb.cc.cc2: TU11.1, TU11.14
Tv3v3: TC40.1, TC41.1, TU11.3, TU11.4

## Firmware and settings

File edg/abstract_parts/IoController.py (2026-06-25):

import warnings
from itertools import chain
from typing import List, Dict, Tuple, Type, Optional, Any, Union, Callable, Mapping, Iterable
from typing_extensions import override
from deprecated import deprecated

from ..electronics_interfaces import *
from .PinMappable import AllocatedResource, PinMappable, PinMapUtil


@non_library
@abstract_block
class BaseIoController(PinMappable, Block):
    """An abstract IO controller block, that takes power input and provides a grab-bag of common IOs.
    A base interface for microcontrollers and microcontroller-like devices (eg, FPGAs).
    Pin assignments are handled via refinements and can be assigned to pins' allocated names.

    This should not be instantiated as a generic block."""

    def __init__(self, *args: Any, **kwargs: Any) -> None:
        super().__init__(*args, **kwargs)

        self.gpio = self.Port(Vector(DigitalBidir.empty()), optional=True, doc="Microcontroller digital GPIO pins")
        self.adc = self.Port(Vector(AnalogSink.empty()), optional=True, doc="Microcontroller analog input pins")

        self.spi = self.Port(
            Vector(SpiController.empty()),
            optional=True,
            doc="Microcontroller SPI controllers, each element is an independent SPI controller",
        )
        self.i2c = self.Port(
            Vector(I2cController.empty()),
            optional=True,
            doc="Microcontroller I2C controllers, each element is an independent I2C controller",
        )
        self.uart = self.Port(Vector(UartPort.empty()), optional=True, doc="Microcontroller UARTs")

        # USB should be a mixin, but because it's probably common, it's in base until mixins have GUI support
        self.usb = self.Port(Vector(UsbDevicePort.empty()), optional=True, doc="Microcontroller USB device ports")

        # CAN is now mixins, but automatically materialized for compatibility
        # In new code, explicit mixin syntax should be used.
        self.can: Vector[CanControllerPort]
        from .IoControllerInterfaceMixins import IoControllerCan

        self._can_mixin: Optional[IoControllerCan] = None

        self.io_current_draw = self.Parameter(RangeExpr())  # total current draw for all leaf-level IO sinks

        self._io_ports: List[BasePort] = [  # ordered by assignment order, most restrictive should be first
            self.adc,
            self.spi,
            self.i2c,
            self.uart,
            self.usb,
            self.gpio,
        ]

    def __getattr__(self, item: str) -> Any:
        # automatically materialize some mixins on abstract classes, only if this is IoController
        # note, getattr ONLY called when the field does not exist, and hasattr is implemented via getattr
        if self.__class__ is IoController and item == "can":
            if self._can_mixin is None:
                from .IoControllerInterfaceMixins import IoControllerCan

                self._can_mixin = self.with_mixin(IoControllerCan())
            warnings.warn(
                f"can is now a mixin, use .with_mixin(IoControllerCan()).can mixin instead",
                DeprecationWarning,
                stacklevel=2,
            )
            return self._can_mixin.can
        else:
            raise AttributeError(
                item
            )  # ideally we'd use super().__getattr__(...), but that's not defined in base classes

    def _type_of_io(self, io_port: BasePort) -> Type[Port]:
        if isinstance(io_port, Vector):
            return io_port.elt_type()
        elif isinstance(io_port, Port):
            return type(io_port)
        else:
            raise NotImplementedError(f"unknown port type {io_port}")

    @deprecated("use _export_ios_inner")
    def _export_ios_from(self, inner: "BaseIoController", excludes: List[BasePort] = []) -> None:
        """Exports all the IO ports from an inner BaseIoController to this block's IO ports.
        Optional exclude list, for example if a more complex connection is needed."""
        assert isinstance(inner, BaseIoController), "can only export from inner block of type BaseIoController"
        self_ios_by_type = {self._type_of_io(io_port): io_port for io_port in self._io_ports}
        exclude_set = IdentitySet(*excludes)
        for inner_io in inner._io_ports:
            if inner_io in exclude_set:
                continue
            inner_io_type = self._type_of_io(inner_io)
            assert inner_io_type in self_ios_by_type, f"outer missing IO of type {inner_io_type}"
            self.connect(self_ios_by_type[inner_io_type], inner_io)
        self.assign(self.io_current_draw, inner.io_current_draw)

    ExportPortTransform = Callable[[BasePort, Optional[str]], Optional[BasePort]]

    def _export_ios_inner(
        self, inner: "BaseIoController", transforms: Dict[Type[BasePort], ExportPortTransform] = {}
    ) -> ArrayStringExpr:
        """Exports all IOs from some inner BaseIoController.
        This must be called in contents() or generate(), after IOs have been defined.

        Optionally specify a transform function, by port type, on IOs.
        This function takes the outer IO port and assignment name (if specified) and returns the transformed IO port.
        For example, this can be used add resistors inline to USB ports.
        If returned (transformed) port is None, the connection is discarded (though connections can be made
        within the transform function as a side effect).
        Otherwise, the returned port is connected to the inner port.
        If this function is used, this must be a GeneratorBlock and the transformed port requested()s and
        device pin_assigns must be generator params.

        Returns the filtered pin assigns, to pass into the inner block's pin assign.

        In most cases, use _wrap_inner which provides all the wrapping functionality, though
        this may be useful where other logic needs to happen with parameters.
        """
        from ..core.Blocks import BlockElaborationState

        assert self._elaboration_state in (
            BlockElaborationState.contents,
            BlockElaborationState.generate,
        ), "can only run in contents() or generate()"

        if transforms:
            assert isinstance(self, GeneratorBlock), "transforms require a GeneratorBlock to work"
            assert self._elaboration_state in (BlockElaborationState.generate,), "transforms can only run in generate()"

            assigns_dict: Optional[Dict[str, str]] = {}
            assert assigns_dict is not None
            for assign in self.get(self.pin_assigns):
                key, value = assign.split("=")
                assigns_dict[key] = value
        else:
            assigns_dict = None
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

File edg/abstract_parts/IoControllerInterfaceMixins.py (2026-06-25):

from typing import Any, Union

from typing_extensions import override

from ..electronics_interfaces import *
from .IoController import BaseIoController, IoController
from ..util import deprecated_param_remap


class IoControllerSpiPeripheral(BlockInterfaceMixin[BaseIoController]):
    def __init__(self, *args: Any, **kwargs: Any) -> None:
        super().__init__(*args, **kwargs)

        self.spi_peripheral = self.Port(
            Vector(SpiPeripheral.empty()),
            optional=True,
            doc="Microcontroller SPI peripherals (excluding CS pin, which must be handled separately), each element is an independent SPI peripheral",
        )
        self.implementation(lambda base: base._io_ports.append(self.spi_peripheral))


class IoControllerI2cTarget(BlockInterfaceMixin[BaseIoController]):
    def __init__(self, *args: Any, **kwargs: Any) -> None:
        super().__init__(*args, **kwargs)

        self.i2c_target = self.Port(
            Vector(I2cTarget.empty()),
            optional=True,
            doc="Microcontroller I2C targets, each element is an independent I2C target",
        )
        self.implementation(lambda base: base._io_ports.append(self.i2c_target))


class IoControllerTouchDriver(BlockInterfaceMixin[BaseIoController]):
    def __init__(self, *args: Any, **kwargs: Any) -> None:
        super().__init__(*args, **kwargs)

        self.touch = self.Port(Vector(TouchDriver.empty()), optional=True, doc="Microcontroller touch input")
        self.implementation(lambda base: base._io_ports.insert(0, self.touch))  # allocate first


class IoControllerDac(BlockInterfaceMixin[BaseIoController]):
    def __init__(self, *args: Any, **kwargs: Any) -> None:
        super().__init__(*args, **kwargs)

        self.dac = self.Port(Vector(AnalogSource.empty()), optional=True, doc="Microcontroller analog output pins")
        self.implementation(lambda base: base._io_ports.insert(0, self.dac))  # allocate first


class IoControllerCan(BlockInterfaceMixin[BaseIoController]):
    def __init__(self, *args: Any, **kwargs: Any) -> None:
        super().__init__(*args, **kwargs)

        self.can = self.Port(
            Vector(CanControllerPort.empty()), optional=True, doc="Microcontroller CAN controller ports"
        )
        self.implementation(lambda base: base._io_ports.append(self.can))


class IoControllerUsb(BlockInterfaceMixin[BaseIoController]):
    """Eventually, the USB device port will be an IoController mixin.
    For now, it's part of base, since it's common enough and there isn't GUI support for mixins.

    This class SHOULD BE mixed into IoController blocks, in preparation for the eventual move.
    This WILL NOT WORK when used in .with_mixin, since this defines no fields."""

    pass


class IoControllerUsbCc(BlockInterfaceMixin[BaseIoController]):
    def __init__(self, *args: Any, **kwargs: Any) -> None:
        super().__init__(*args, **kwargs)

        self.cc = self.Port(Vector(UsbCcPort.empty()), optional=True, doc="Microcontroller USB Power delivery CC pins")
        self.implementation(lambda base: base._io_ports.append(self.cc))


class IoControllerI2s(BlockInterfaceMixin[BaseIoController]):
    def __init__(self, *args: Any, **kwargs: Any) -> None:
        super().__init__(*args, **kwargs)

        self.i2s = self.Port(
            Vector(I2sController.empty()),
            optional=True,
            doc="Microcontroller I2S controller ports, each element is an independent I2S controller",
        )
        self.implementation(lambda base: base._io_ports.append(self.i2s))


class IoControllerDvp8(BlockInterfaceMixin[BaseIoController]):
    def __init__(self, *args: Any, **kwargs: Any) -> None:
        super().__init__(*args, **kwargs)

        self.dvp8 = self.Port(
            Vector(Dvp8Host.empty()), optional=True, doc="Microcontroller 8-bit DVP digital video ports"
        )
        self.implementation(lambda base: base._io_ports.append(self.dvp8))


class IoControllerWifi(BlockInterfaceMixin[BaseIoController]):
    """Mixin indicating this IoController has programmable WiFi. Does not expose any ports."""


class IoControllerBluetooth(BlockInterfaceMixin[BaseIoController]):
    """Mixin indicating this IoController has programmable Bluetooth Classic. Does not expose any ports."""


class IoControllerBle(BlockInterfaceMixin[BaseIoController]):
    """Mixin indicating this IoController has programmable Bluetooth LE. Does not expose any ports."""


class IoControllerPowerOut(BlockInterfaceMixin[IoController]):
    """IO controller mixin that provides an output of the IO controller's VddIO rail, commonly 3.3v."""

    def __init__(self, *args: Any, **kwargs: Any) -> None:
        super().__init__(*args, **kwargs)
        self.pwr_out = self.Port(
            VoltageSource.empty(),
            optional=True,
            doc="Power output port, typically of the device's Vdd or VddIO rail at 3.3v",
        )

    @override
    def contents(self) -> None:
        super().contents()
        if isinstance(self, IoController):
            self.require(
                self.pwr_out.is_connected().implies(~self.pwr.is_connected()),
                "can only connect one of pwr and pwr_out (same physical pin)",
            )
            self.require(
                self.pwr_out.is_connected().implies(self.gnd.is_connected()),
                "gnd must be connected if pwr_out connected",
            )

    def _generate_gnd_node(self) -> Ground:
        """Helper function that returns a ground node, either directly taking the gnd port if available,
        or generating an internal ground node.

        Requires self.gnd.is_connected() as a generator param.
        """
        assert isinstance(self, IoController)
        if self.get(self.gnd.is_connected()):  # gnd connected externally
            return self.gnd
        else:
            self.gnd_model = self.Block(DummyGround())
            return self.gnd_model.io

    @deprecated_param_remap(("voltage_out", "voltage"))
    def _generate_pwr_node(self, voltage: RangeLike, current_limits: RangeLike) -> Union[VoltageSink, VoltageSource]:
        """Helper function that returns a power node, either directly taking the pwr port if available,
        or generating an internal voltage node and optionally connecting it to pwr_out (if used).

        Requires self.pwr.is_connected(), self.pwr_out.is_connected as generator params.
        """
        assert isinstance(self, IoController)
        if self.get(self.pwr.is_connected()):  # power supplied externally
            return self.pwr
        else:
            self.pwr_out_model = self.Block(
                DummyVoltageSource(
                    voltage=voltage,  # tolerance is a guess
                    current_limits=current_limits,
                )
            )
            if self.get(self.pwr_out.is_connected()):
                self.connect(self.pwr_out, self.pwr_out_model.io)
            return self.pwr_out_model.io
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

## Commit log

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2022-09-21 Concatenate operator (#149)
    Adds FLATTEN (for arrays-of-arrays) and CONCATENATE (text append)
    operators in the IR. The implementation is minimal to support these two
    use cases:
    - Check I2C addresses - flatten the address list of all attached
    devices, then check for uniqueness
    - Refactor array-connect expansion to use the expression language
    internally, instead of custom compiler tasks that basically do the same
    thing.
    Other minor maintenance fixes:
    - Roll Scala version for compiler
    - Add .jvmopts so sbt doesn't barf on startup
    Other changes:
    - Support .flatten(port => contained array parameter) on array ports
    - Support EQ and NEQ between Array types
    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
    [Distance_Vl53l0x.py]
2022-10-03 Remove dependencies on unavailable data (#158)
    Deletes the Digikey part table parsers which relied on data that was
    never committed to the repository and reworks the examples to work
    around that.
    Digikey has changed their parts tables since we downloaded our initial
    data set, and because it's unclear if we can redistribute our data set,
    we're just going to nuke it from orbit altogether. At some point in the
    future we may manually curate a parts table, eg using a parts list from
    a textbook.
    This means all the examples will unit test, and the full test suite is
    now part of the PR test workflow.
    - For the non-generic parts (inductor, diode, Zener, FET, crystal),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
    [design.kicad_pcb]
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2022-10-13 Robot Driver Cleanup (#164)
    Makes robotdriver2 the only robotdriver, since the original had issues
    (mostly around connecting peripheral IOs through an IO expander, which
    doesn't work well with Arduino libraries that expect to be able to
    digitalWrite things). Also updates the code to rename allocate to
    request.
    [CombinedPanel.kicad_pcb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]
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2022-10-29 BLDC driver / omnibus test board (#168)
    As the title implies, a brushless motor driver board using the DRV8313
    chip. Also tests mechanical keyboard parts and a discrete buck-boost
    converter.
    Other misc changes:
    - for adapters, change all ports to be required
    - add DigitalBidir -> open drain (DigitalSingleSource configured for low
    side drive) adapter, and use as part of the voltage translator for the
    SK6812
    - add `__repr__` for some of the pin mapping utils - the debugging that
    led to #169
    - add capacitor derating floor
    - add if-connected utility pseudoblock
    - fix digital source -> voltage source adapter
    - fix max d(1-d) for boost buck converter sizing
    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
    [BldcDriverBoard-B_Mask.gbr, BldcDriverBoard-B_Silkscreen.gbr, BldcDriverBoard-Back.gbr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]
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2022-12-20 KiCad Schematic Import (#183)
    Instead of importing netlists, this now directly imports schematics and
    netlists from that. There are 3 methods:
    - Block defined in HDL, connectivity loaded from KiCad using refdes.
    - Block defined in KiCad using inline Python
    - Block defined in KiCad, where the Block class defines symbol parsing
    rules (eg, resistor with value "51" is parsed as a 51-ohm resistor +/- a
    default tolerance of 5%)
    Also adds a more general infrastructure to add KiCad value parsing rules
    and symbol pin mapping rules to any block, through superclasses
    KiCadInstantiableBlock (creates a Block model from a KiCad symbol) and
    KiCadImportableBlock (defines symbol pinning) respecti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
    [test_kicad_import_codeparts.kicad_sch, test_kicad_import_inline.kicad_sch, test_kicad_import_inline_vars.kicad_sch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]
2022-12-27 Refactor examples / libraries to use import KiCad schematics (#184)
    Refactors a lot of analog blocks (most opamp topologies, analog
    switches) to be KiCad importable blocks (by defining a symbol pin
    mapping) and/or KiCad imported schematics. Adds custom symbols for many
    of these parts, some KiCad's base symbol library for the most part lacks
    abstract / generic and high-level parts.
    Netlists of example designs should not have changed.
    KiCad import behavior change:
    - global labels must connect to either a node or external block port and
    are not treated as link names
    - net labels are used as link names and must not collide with any
    existing object member
    - add unit tests for the a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
    [Amplifier.kicad_sch, DifferentialAmplifier.kicad_sch, ErrorAmplifier.kicad_sch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]
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2023-01-06 Add PCB tstamp / path upgrader (#190)
    Older PCB designs used a component tstamp / path format that was the
    string path which is no longer supported in KiCad 6 which requires the
    hex format. So boards designed in KiCad 5 don't preserve components when
    importing a new netlist. This adds a script that takes a PCB and
    netlist, and updates the PCB tstamps / paths.
    (note: while tstamps is what's indicated in the KiCad GUI, loading a new
    netlist actually seems to link by the path field)
    This also updates the CanAdapter PCB. The design is not changed, but
    this updates the tstamp / path and does a KiCad 5 -> 6 format
    conversion. Actually updating the netlist may change the design because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
    [CanAdapter.kicad_pcb, design.kicad_pcb]
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2023-01-08 Separate SWO/TDI debug header pinning (#193)
    Prior, SWO was part of SWD even for micros that do not support it. Now,
    SWD is defined as only power, reset, SWCLK, SWDIO, and SWO and TDI (pins
    available on the 10-pin SWD header) can be separately connected. Also
    defines a mixin-style class for IoControllers with a SWD header.
    By default, SWO and TDI on the header is not connected, though it can be
    specified with a refinement. For now, all the examples are updated to
    keep the previous netlist (except for blinky, which now has SWO
    disconnected), though this could be changed later, eg connect a
    bidirectional UART instead of the SWO pin.
    Additionally, changes the compiler so a boundary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
    [IoControllerProgramming.py]
2023-01-09 Support pin name = number in schematic import (#195)
    Prior, if pin name = number, it would give an ambiguous pinning error
    because both match. This adds a check that they're different to trigger
    the error.
    [test_kicad_import_aliasedpinname.kicad_sch]
2023-01-11 Fix KiCad import on symbols with no ports (#196)
    like the graphical symbol on the example
    lack of explicit `portarray.defined()` strikes again =( maybe there will
    be a cleaner fix for this at some point
    [test_kicad_import_blackbox.kicad_sch]
2023-01-18 Refactor internal microcontrollers to use BaseIoController (#200)
    ... so the IoController subclass list is clean for application-level
    subcircuits instead of bare chips
    Also changes the compiler so that bad array references will not lower
    (and cause an error in structural validation) instead of crashing the
    compiler
    [IoController.py]
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2023-01-31 FCML test board... and (many other) related changes (#199)
    This turned out to be quite the omnibus PR.
    Main change is a buck FCML (flying capacitor multilevel converter) test
    board. No idea if it'll work, the design risk here is through the roof.
    Also a FT232 based FPGA programmer and a USB-UART board (because why
    not) that will go on the same panel.
    Library changes & fixes: simple parts:
    - Add Jumper and DigitalJumper - a disconnect-able (in footprint)
    connection though treated as always connected in the electronics model
    - Add triangular solder jumper
    - Move Keystone 5015 compact footprint to libraries, since it's tested
    working
    - Add SOIC-8 pinning to FETs
    - Add more f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
    [FcmlBoard.kicad_pcb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]
2023-02-01 Robot Driver 3 (#205)
    Another board, a wheeled robot driver based on the ESP32 camera
    microcontroller board and with servo connectors, RGB LEDs, ToF lidar
    sensor connector ports, and a LiPo -> 3.3v buck converter.
    Changes:
    - Electronics model: all VoltageSource / VoltageSink can have
    as_digital_source and friends, because of the polarity can be flipped as
    a bridge
    - Add PPTC fuse using passively typed ports, and separates this from the
    SeriesPowerPptcFuse with VoltageSource/Sink ports that was used before.
    - Fix the fallout of this in the examples
    - Parse PPTC "resettable fuses" from the jlc parts table
    - VL53L0x array: allow first XSHUT to be fixed high
    - Add QMC5883L 3-axis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
    [RobotDriver3-B_Mask.gbr, RobotDriver3-B_Silkscreen.gbr, RobotDriver3-Back.gbr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]
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2023-02-23 Clean up categories (#212)
    Add categories where there are none and fix some ones that exist, so
    that the blocks library panel looks clean and usable. Some general
    cleanup too.
    Other fixes:
    - In general hide a bunch of inner stuff behind an `InternalBlock`
    category superclass
    - Allow adapters to be created on boundary ports
    - When subclassing a `non_library` superclass, the superclass's
    superclasses are pulled in to the proto (and won't throw an error for
    things like refinements if it's missing a link).
    - Add unit test
    - Replaces a bunch of `abstract_block` with `non_library`. The general
    rule is that `abstract_block` should be able to be instantiated, while
    `non_library` is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
    [Distance_Vl53l0x.py, GateDrivers.py, Imu_Lsm6ds3trc.py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]
2023-02-23 Switch controller board (#209)
    A board that controls power to a target using a high side MOSFET and
    through a 4-pin header. Autorouted, 'pcb in 2 hours'.
    Library changes:
    - Current sense resistor: add actual_power parameter based on actual
    resistance and current draw
    - Set current limits for HighSideSwitch
    - Change OLEDs to use bottom-contact FPC headers
    - Add OLED outline to the 0.91" OLED as a nonfunctional component
    - Add AFC01 series FPC headers, make this the default
    - Update netlists to use this part
    - Allow high current off USB-C connector
    - For nonfunctional board footprints: correct nonfunctional attributes
    (through_hole / other) and exclude non-components from BoM a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
    [SwitchControllerBoard-B_Mask.gbr, SwitchControllerBoard-B_Silkscreen.gbr, SwitchControllerBoard-Back.gbr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]
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2023-03-01 Block-based default subclass refinement and ideal components (#220)
    Add a default refinement on blocks through the decorator
    `@abstract_block_default(lambda: MyRefinedBlock)`, and add default ideal
    refinements for power converters and IoController. This allows designs
    with unselected choices of those components to build (instead of the
    cascading errors with an abstract part with no implementation). Ideal
    components create an error by default if they are left in the design.
    Changes the DigitalLink behavior to apply tolerance thresholds loosely -
    previously the IO voltage threshold was the overly-strict (gnd.upper -
    tol, pwr.lower + tol), now this is the less-strict (gnd.lower - tol,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
    [IoController.py]
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2023-03-05 General library cleanup (#228)
    - nRF52 device: if vbus not used, don't generate the cap
    - add default for SPI memory to W25Q
    - better handling of zero and inf
    - power converters: don't error on zero current draw, create an
    arbitrarily large maximum inductance
    - E-series utils: if lower zero, arbitrarily set a lower bound at 1e-6
    (micro series)
    - E-series utils: if upper unbounded, set it two decades from the lower
    now, so it picks a decade value
    - Abstract Vl53l0x: move default into the abstract block instead of a
    default BoardTop refinement
    [Distance_Vl53l0x.py, IoControllerProgramming.py]
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2023-03-28 Schematic import improvements and compiler UI improvements (#237)
    - KiCad schematic import improvements
    - Support `_Small` versions of symbols
    - Add symbol pinning for DecouplingCapacitor, FerriteBead,
    SeriesPowerFerriteBead
    - Support dot notation in global / hierarchy labels, to access inner
    components of bundles
    - Add test case for bundle dot notation
    - Open schematic file as unicode, to support the tolerance format
    - Add test case for tolerance
    - Fixes a few cases where the compiler could hard crash if a library
    element failed to compile - instead, this allows the compiler to ignore
    those and continue. In the IDE, this avoids the compiler crashing
    verbose stacktrace.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
    [test_kicad_import.kicad_sch, test_kicad_import_bundle.kicad_sch]
2023-03-29 Schematic import improvements (#238)
    - More checks to the import flow:
    - Detect disconnected labels and error on those (since the import flow
    can't detect connections mid-wire)
    - Not-connected checks if there's no pins connected or >1 pins connected
    (NC must be connected to exactly one pin)
    - Note, not-connected is not required (should this change in the
    future?)
    - Refactor the import flow:
    - Power pins are treated as pseudolabels, since they don't show up on
    component symbols list
    - Shared connected-components algorithm that takes a list of list of
    connected components and merges all the sublists that overlap in terms
    of components
    - Two stage import flow: first stage to connec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
    [test_kicad_import.kicad_sch, test_kicad_import_aliasedpinname.kicad_sch, test_kicad_import_badlabel.kicad_sch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]
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2023-04-04 Library additions and cleanup (#242)
    - Move PassiveConnector to electronics_abstract_parts... where it
    belongs
    - Move the LiPo connector to the library, and add some documentation
    - Add a connector-based resistive sensor, eg for an external thermistor.
    Calculates the output voltage range (though includes the +v tolerance
    stackup).
    - Refactor the battery protector to the S-8261, which is actually
    available
    - Misc minor cleanup
    [Distance_Vl53l0x.py]
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2023-04-07 Cleanup (#245)
    - Resolves #232, removes not_connected which wasn't really used anywhere
    else
    - Resolves #219, renames all the example folders to the board name
    - Remove `Test` from the board names
    - Update .gitignore, should be a bit cleaner now
    - Allow example designs that aren't meant to be board (all the blinky
    examples) to not generate netlists and stuff
    - Remove gerbers, in the repo probably wasn't the right place to put
    them
    - Add another parsing rule for JLC diodes
    [BldcController.kicad_pcb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]
2023-05-07 Compositional generators (#250)
    Resolves #215. One of those rare PRs with more lines removed than added!
    Changes generators to be compositional: instead of a monolithic single
    `self.generator(fn, ...args...)`, this now invokes `self.generate()`
    (structurally like `self.contents()`) which can `self.get(...)` on any
    parameter. Parameters must be declared with `self.generator_param(...)`
    ahead of time (in `__init__` and `contents`), but this can be called
    multiple times.
    Refactors libraries to use mixins and have better separation of
    concerns. Major changes:
    - Parts table based selectors now have individual select functionality
    in each mixin class, e.g. the footprint class handles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
    [Distance_Vl53l0x.py, IoController.py, IoControllerMixins.py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]
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2023-05-28 SWD Probe v2 + fix refinement blocks with additional ports (#254)
    A spin of the SWD debug probe using modern infrastructure. Major board
    changes:
    - Move the SWD source header into the board file. Technically it's
    reusable, but it's a bit of a mess.
    - Add a SWD source header for the TC2030 as a 6-pin 2.54mm dual-row
    edge-inline header
    - Add 5v protection Zener diode, add USB ESD diode
    - Replace RGBs with single-color LEDs - while RGBs are nice we never did
    anything with them in firmware
    - Specify LED colors: white for USB connectivity (custom function),
    yellow for programming activity, green for target power
    - Add pull-up resistor on target LDO enable, so it should work with
    stock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
    [SwdDebugger.kicad_pcb]
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2023-06-09 More example boards: 7-segment, IoT display, robot controller, ESP programmer (#255)
    As the title says, more example boards.
    Example PCBs
    - IoT 7-segment display board, using 0606-size Neopixels as replacement
    innards for 7-segment clocks
    - SVG-PCB hybrid flow, with included SVG-PCB layout definition (.js)
    file and a script to handle renaming (since programmatic naming doesn't
    seem supported in SVG-PCB?)
    - SVG-PCB layout definition includes parameterized geometry and
    LEDs-per-segment for the 7-segment display
    - IoT display with 2 OLEDs (24- and 30-pin FPC) and e-ink display
    (30-pin FPC)
    - Robot crawler controller (ESP32S3 board with 4 servo PWMs w/ feedback
    sense, camera, OLED)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
    [EInkBoostPowerPath.kicad_sch, EspAutoProgram.kicad_sch, EspProgrammer.kicad_pcb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]
2023-06-24 IoT robot owl driver board (#261)
    A circular board to drive a simple animatronic robot owl. With camera,
    mic, speaker, servo PWMs, neopixels, basic analog ambient light sensor.
    Experimental.
    Also includes a SVGPCB definition + name remap script (workaround) for
    the LED ring generator.
    Infrastructural bugfixes:
    - Unit tests dump proto to disk even when the design errors
    - JlcInductor used to overwrite the frequency rating from all to zero,
    meaning that particular inductor could never be selected again (ugh
    mutable state). Now it's moved to a different variable
    Library improvements:
    - Support refdes prefix in KiCadBlackBox
    - Better naming of the prior ESP32 WROVER DEV board a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
    [PhotodiodeSensor.kicad_sch, RobotOwl.kicad_pcb]
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2023-07-02 Mixin implementation for dev boards, I2S, DVP, VReg EN (#264)
    - Add VoltageRegulatorEnable mixin, which adds an optional active-high
    enable pin to a VoltageRegulator
    - Implemented on the ideal regulators and AP2204K
    - Add IoControllerI2s
    - Add Dvp8 link + port (8-bit digital video port, commonly used by ESP32
    + OV2640 cameras) and IoControllerDvp8 mixin
    - Ideally, this would be a width-parameterizable interface, but the core
    logic for structurally parameterized links doesn't exist ... yet
    - Refactor existing boards to use this port
    - Add IoControllerPowerOut, and IoControllerUsbOut (plus intermediate
    classes in the hierarchy) for dev boards which can supply po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
    [Camera_Ov2640_Fpc24.py, IoController.py, IoControllerInterfaceMixins.py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]
2023-07-02 BLDC driver and SWD debugger spin (#265)
    As the title implies.
    Design changes:
    - Layout not included (for an external project).
    - BLDC:
    - Remove the extraneous stuff from the prior omnibus run
    - Replace micro with a Feather nRF52840 dev board.
    - Add hall sensors, motor voltage sense, motor current sense
    - TEST POINTS EVERYWHERE
    - Move PowerOutConnector to fcml (prior in bldc for the buck-boost
    converter)
    - SWD:
    - Change to DAPLink pinning
    - Add target reset switch and pull-up (since this acts as bootloader
    entry on DAPLink)
    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
    [BldcController.kicad_pcb]
2023-07-07 IoT devices mega-panel, more mixin examples (#266)
    Applications of mixins and 3 PCBs: an IoT knob, IoT CPU fan controller /
    driver, and IoT power LED driver (buck converter).
    Bugfixes
    - Remove USB from ESP32C3 - it was debug only, not programmable (like
    ESP32S3)
    Library changes
    - Refactor RotaryEncoderWithSwitch to use a RotaryEncoderSwitch mixin
    - Add parallel wrapper hierarchy for RotaryEncoder, which delegates
    mixins appropriately
    - Add Sunlord and TDK inductors - because we didn't really have power
    inductors before
    - In some older designs, peg their inductors to the prior selection
    - Power and CurrentSense resistors: propagate actual_resistance
    - OpenDrainDriver, which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
    [IotFan.kicad_pcb, IotLedDriver.kicad_pcb]
2023-07-09 OwlBot r2 (#269)
    - OLEDs now require the reset pin, experimentally there doesn't seem to
    be a way to initiate a software reset - even the comms interfaces might
    be corrupt on startup.
    - Add APX803S power-on reset generator with parameterized reset
    threshold.
    - OwlBot now includes a power-on reset generator, using the same circuit
    as the Adafruit OLED boards
    - Make PinHeader254 abstract, and have separate Vertical and Horizontal
    types. Vertical is the default refinement
    - Update OwlBot layout to use horizontal PTH headers, to avoid
    mechanical interference. As sent for the production run!
    [RobotOwl.kicad_pcb]
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2023-07-27 Small fixes (#273)
    - Fix ncols for switch matrix
    - Allocate USB pins first, since they're generally dedicated pins
    [IoControllerInterfaceMixins.py]
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2023-08-10 Resettable mixin (#280)
    Add external reset pin support to microcontrollers via a Resettable
    mixin which can be applied to any Block. Refactor VoltageRegulatorEnable
    to use the Resettable mixin instead.
    Resettable defines an optional reset port, which when not connected
    generates internal reset circuitry to keep the device always enabled,
    and when connected directly connects the digital reset line (without
    generating any interface circuitry - it is up to the system designer to
    create a proper circuit).
    Also break up big SWD, by separating out the optional (from the spec
    points of view) reset line. SWD connector now only defines the base gnd,
    power, and SWD lines, with reset, SWO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
    [IoControllerProgramming.py]
2023-08-16 Automatically materialize USB and CAN mixins for compatibility (#283)
    Legacy code had CAN and USB on all IoControllers, but mixins changed
    that (because USB and CAN are not universal peripherals) which was a
    breaking change. This automatically materializes the USB and CAN mixins
    when requested using legacy-style code, by overloading
    `__getattr__(...)`. This should also correctly encode the requirement
    for mixins as part of the block type.
    Likely examples and tutorials will continue using the old-style
    (non-mixin) USB syntax for simplicity.
    [IoController.py]
2023-08-17 Crawlerbot 2, fox project example boards (#281)
    Updates crawlerbot with 14 servos (using a STM32F103 as an IO expander),
    and adds the fox wearable project (E-ink + neopixel chain + ESP32). As
    with most board revisions, lots of library additions / improvements and
    some infrastructural changes.
    Infrastructural changes
    - Add refdes prefix to net names - so net connectivity can work even
    after panelization
    - Was bitten by this before, fool me once...
    - Lots of netlist changes
    - SWD connector reset now Bidir indicating that it can tri-state, needed
    since other signals can also drive the line
    - Add (experimental) QSPI mixin
    - Connect QSPI pins to RP2040 - hope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
    [Esp32Camera.kicad_pcb, FoxProject.kicad_pcb, Ice40.kicad_pcb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]
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2023-08-29 Cleanup type hierarchy / categorization (#286)
    Add non_library tags (to prevent some items from showing up in the
    library browser) and categorization superclasses.
    Also add a output-voltage-greater-than-input constraint to the Tps61040
    boost converter.
    [IoController.py]
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2023-10-19 Continued example boards (#299)
    More example boards:
    - IoT soldering iron controller with discrete synchronous buck converter
    - Update the IoT fan controller with a discrete micro (instead of RF
    module)
    - Picoprobe, maybe this will be the RP2040 board that finally works
    - USB key, as an example of an ultra-size-optimized board
    - Jacdac mechanical keyswitch
    Including these additional libraries:
    - CombinedCapacitor as a multipack device, to combine capacitors on the
    same net
    - Half-bridge with gate driver, replacing the old half-bridge generator
    which didn't work
    - HDC1080 I2C temperature sensor
    - UCC27282 gate driver, 5v compatible with shoot through protect
    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
    [DifferentialAmplifier.kicad_sch, EspProgrammer.kicad_pcb, IotFan.kicad_pcb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]
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
